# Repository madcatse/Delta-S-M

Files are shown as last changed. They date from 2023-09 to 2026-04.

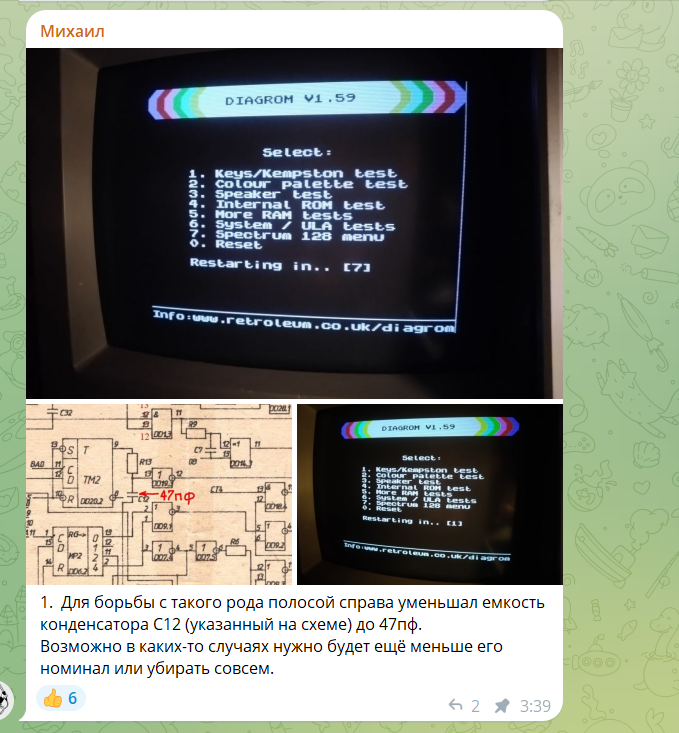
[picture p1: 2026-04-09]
fix1.PNG

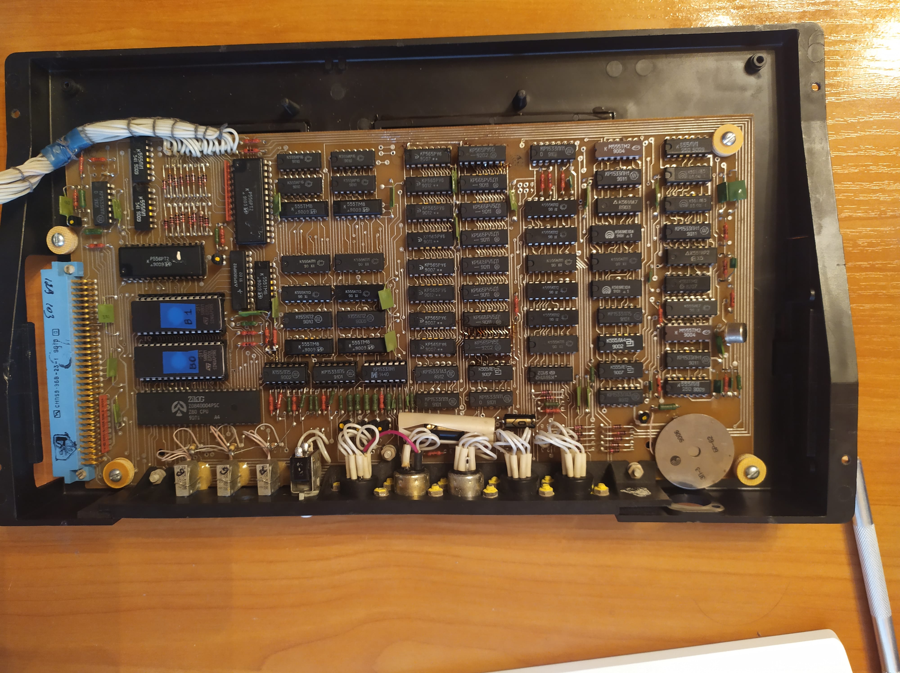
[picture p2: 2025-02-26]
docs/Original Delta/2023-03-17 20.00.21-min.jpg

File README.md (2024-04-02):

# Delta-S-M Ver.1.0 Gerber Files

Delta-S-M Logo

Welcome to the first release of Gerber files for Delta-S-M Ver.1.0! This repository contains the manufacturing files necessary to produce the Delta-S-M Ver.1.0 board.

## Table of Contents
- [Introduction](#introduction)
- [Features](#features)
- [Getting Started](#getting-started)
- [Folder Structure](#folder-structure)
- [Cable pinout difference](#cable-pinout-difference)
- [Making SCART cable](#making-scart-cable)
- [License](#license)

## Introduction
Основной задачей данного проекта я поставил создание наиболее близкого к оригиналу клона персонального восьмибитного компьютера "Дельта-С", который в свою очередь является клоном ZX Spectrum 48K. Выбор модели был обусловлен давней мечтой об "улучшении" оригинальной машины, которой я обладаю с 1991 года. В процессе работы цель проекта несколько раз корректировалась и вместо точной копии стала некоторой "вариацией" на тему оригинала, с небольшими корректировками.

## Features
- High-performance microcontroller
- Multiple digital and analog I/O options
- Onboard peripherals such as LEDs, buttons, and connectors
- Expandable with additional modules or shields
- Compact form factor for easy integration

## Getting Started
To get started with Delta-S-M Ver.1.0, follow these steps:
1. Clone or download this repository.
2. Open the Gerber files in your preferred PCB manufacturing software.
3. Verify the design and make any necessary adjustments.
4. Generate the necessary manufacturing files (e.g., drill files, copper layers).
5. Submit the generated files to your preferred PCB manufacturer.
6. Review the manufacturer's guidelines and requirements for PCB production.
7. Proceed with the manufacturing process.
8. Once manufactured, assemble the components onto the PCB following the provided bill of materials (BOM).
9. Power up the Delta-S-M Ver.1.0 board and start exploring its capabilities!

## Folder Structure
The repository is organized as follows:
- /Gerber: Contains the Gerber files necessary for PCB manufacturing.
- /BOM: Includes the bill of materials (BOM) listing all components required for assembly.
- /Documentation: Provides additional documentation, schematics, and datasheets related to Delta-S-M Ver.1.0.

## Cable pinout difference

Be carefull, as there is a very important difference in video cable pinout between v0.1, v1.0 and v1.2 and up.

**v0.1 and v1.0 boards video pinout:**

- 1 - Sync
- 2 - Red
- 3 - N/C
- 4 - Blue
- 5 - Green
- 6 - GND
- 7 - +5V

**v1.2 boards video pinout:**

- 1 - Sync
- 2 - GND
- 3 - Red
- 4 - Green
- 5 - Blue
- 6 - Audio
- 7 - +5V

V1.2 boards are compatible with original Delta-S and Delta-128 and could be connected with their cables.

## Making SCART cable
The best video quality could be achived with SCART cable with RGB mode. Delta S-M is capable of outputting native RGB signal and uses a SCART cable to connect to RGB-capable TVs. The picture below illustrates pinout of both SCART plug and DIN-7 plug.

SCART Pinout

15 - Red
11 - Green
7 - Blue
20 - Sync
16 - ADD 180 Ohm resistor between computer and SCART plug and connect it to pin 16 to enable switching to correct RGB mode. Direct +5V could DAMAGE YOUR TV!
5, 9, 13, 17 and 21 (metal case) - Ground

## License
This project is licensed under the [MIT License](LICENSE). Feel free to use, modify, and distribute the Delta-S-M Ver.1.0 Gerber files as per the terms of the license.

For more details, refer to the [LICENSE](LICENSE) file.

---

Delta-S-M Ver.1.0

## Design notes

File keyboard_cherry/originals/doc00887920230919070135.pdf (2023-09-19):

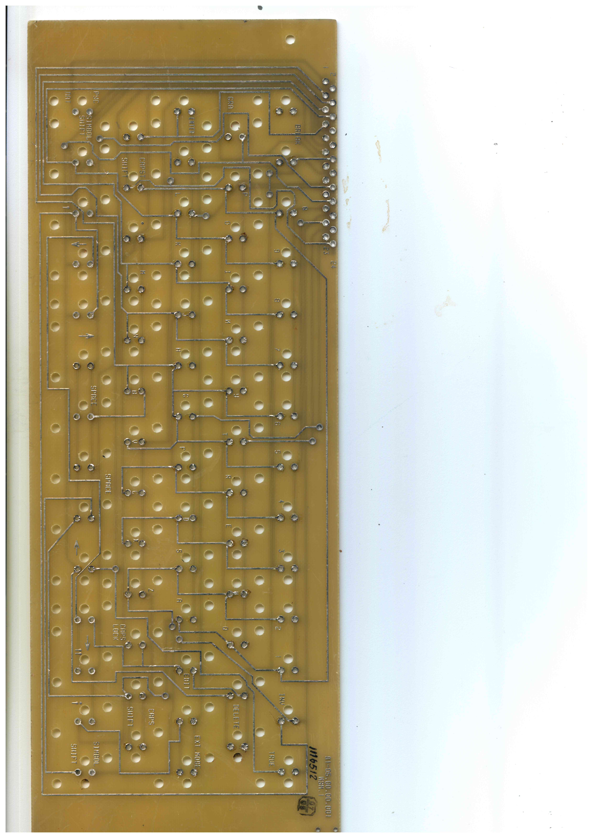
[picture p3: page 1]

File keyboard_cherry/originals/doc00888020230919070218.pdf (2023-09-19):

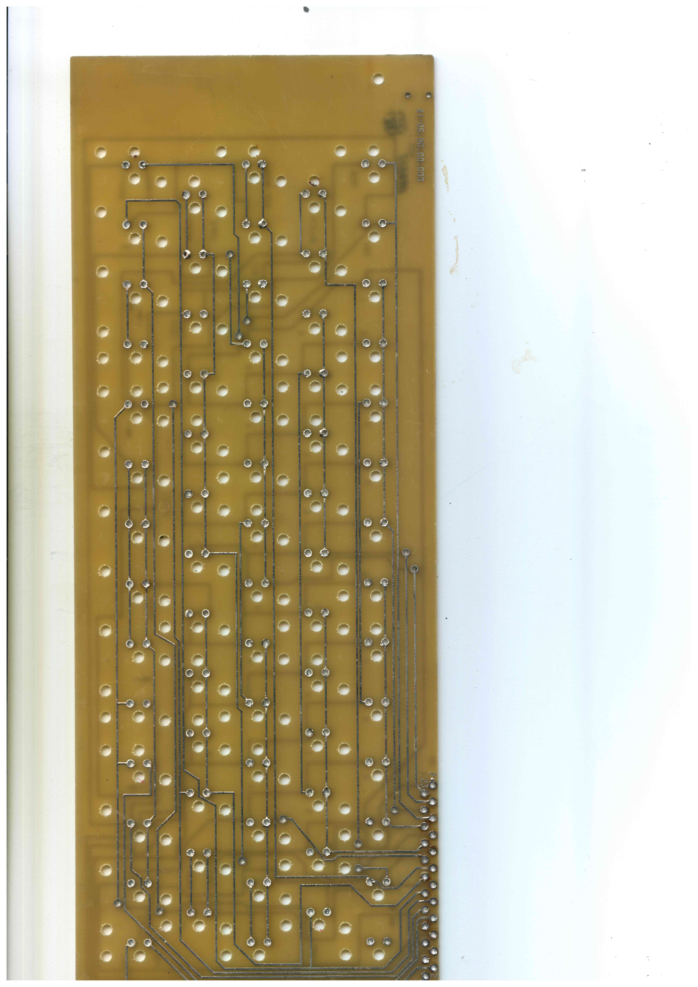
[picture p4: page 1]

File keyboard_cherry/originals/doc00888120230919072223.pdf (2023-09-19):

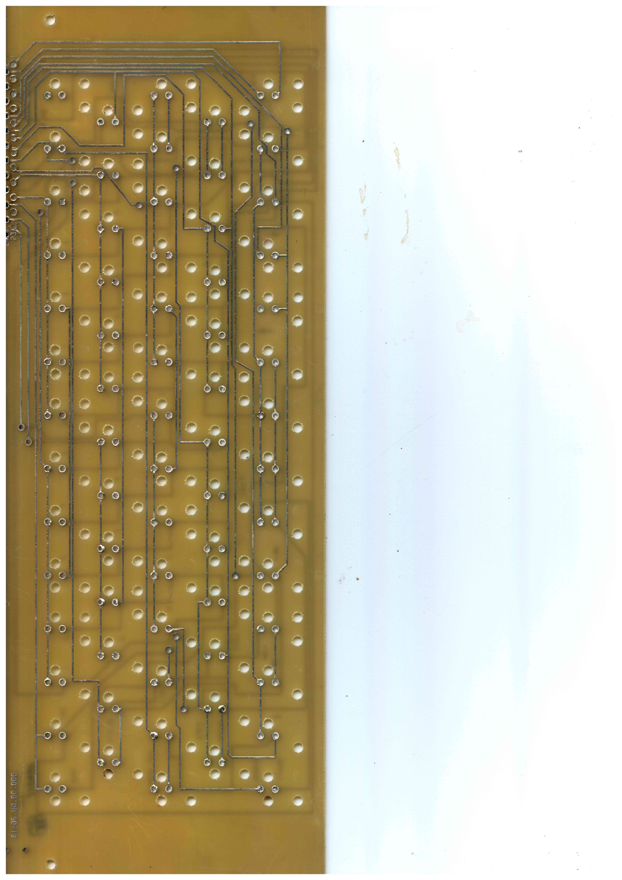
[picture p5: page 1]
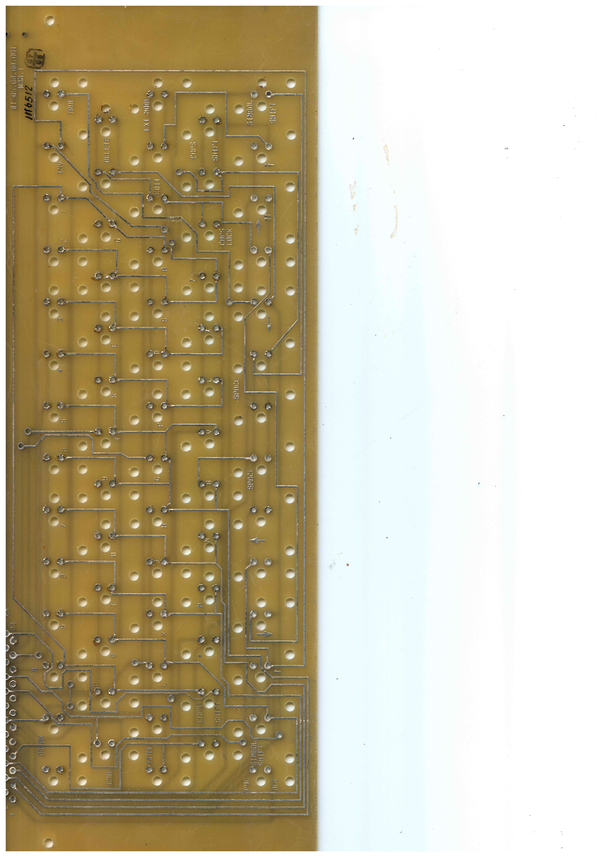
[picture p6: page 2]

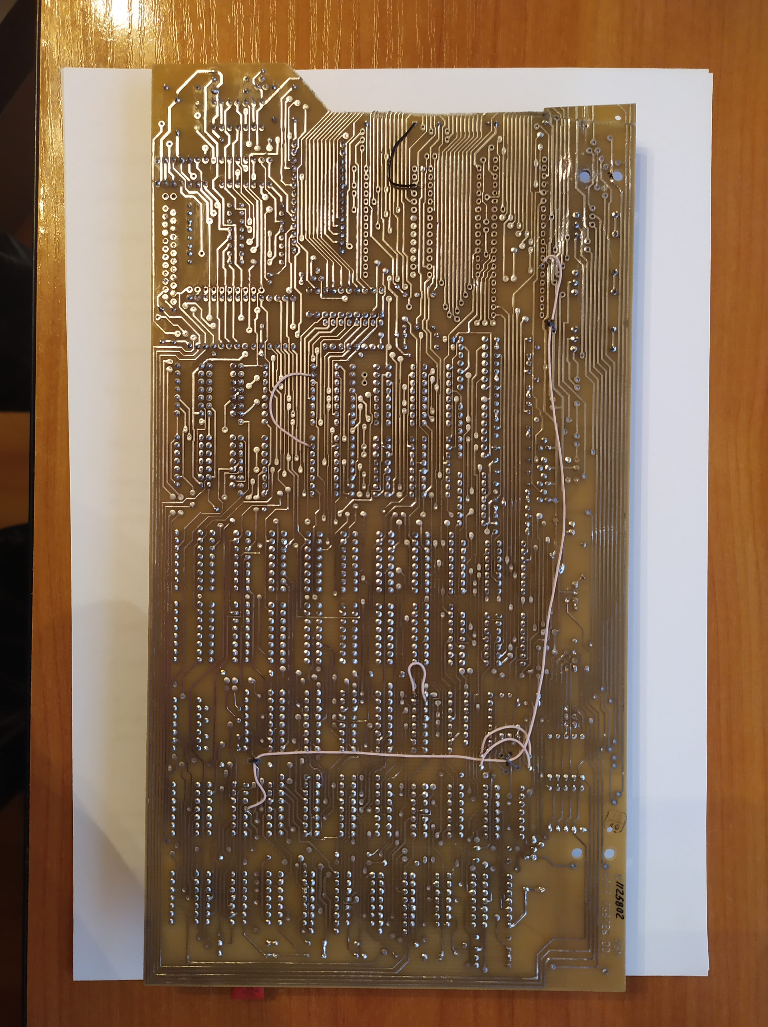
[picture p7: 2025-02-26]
docs/Photos of dead board/2023-03-13 19.23.27-min.jpg

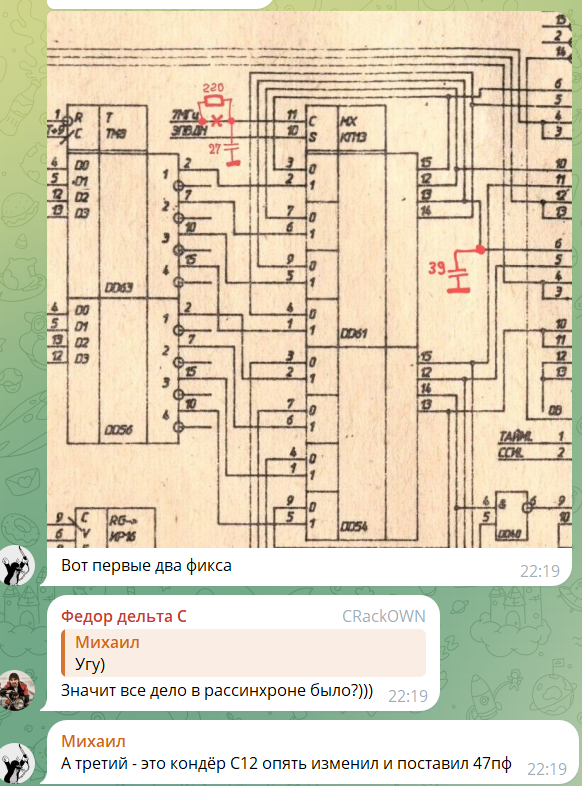
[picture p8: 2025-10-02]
Снимок.PNG

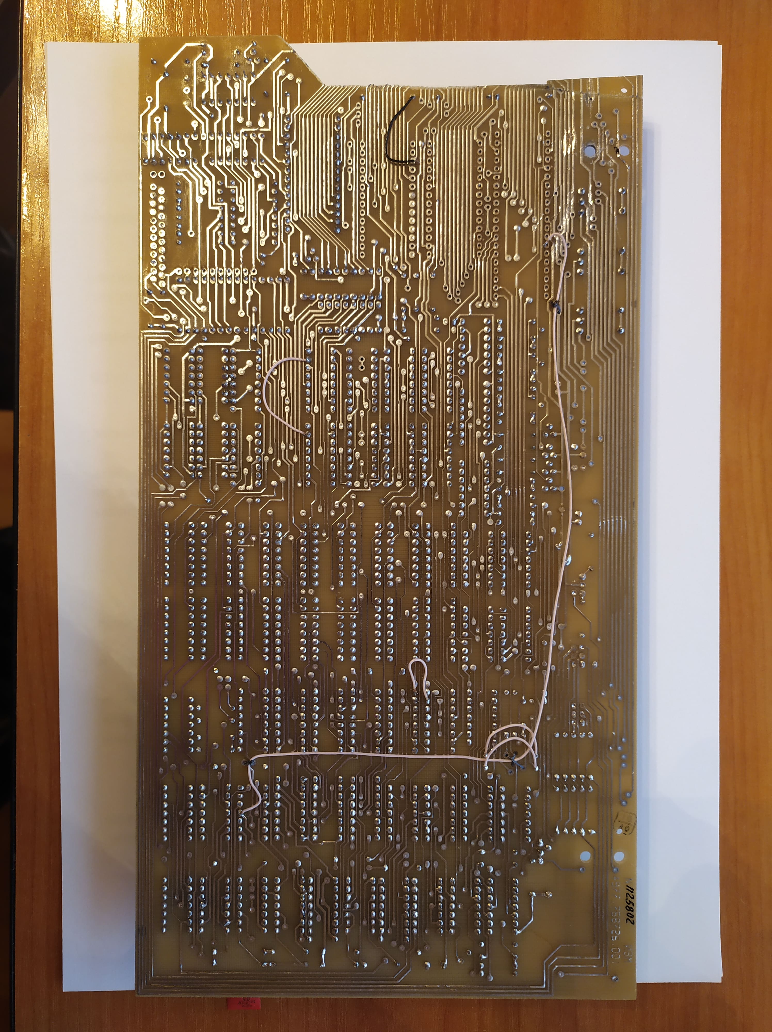
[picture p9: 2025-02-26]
docs/Photos of dead board/2023-03-13 19.23.37-min.jpg

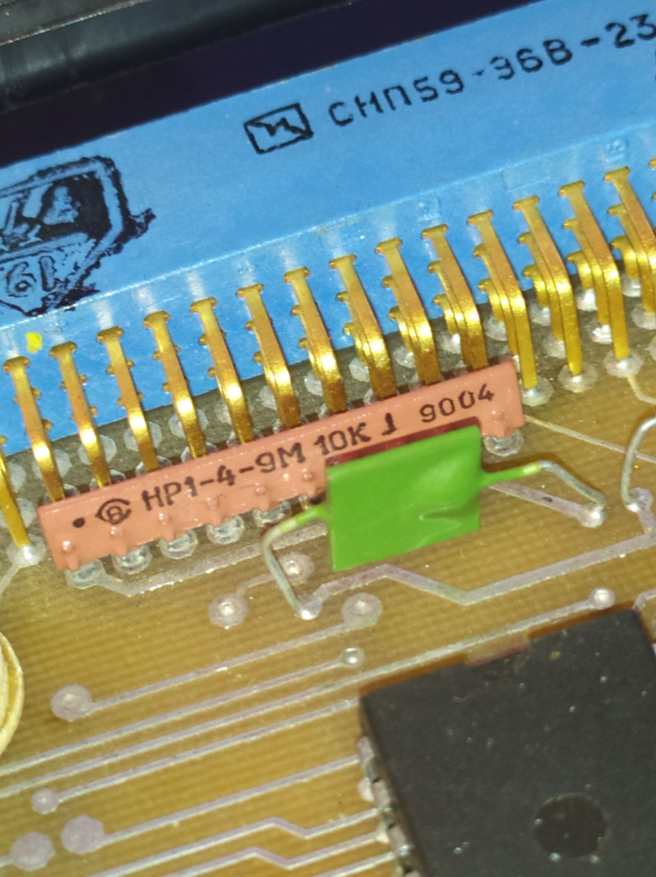
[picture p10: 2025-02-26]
docs/Original Delta/2023-03-13 20.28.23-min.jpg

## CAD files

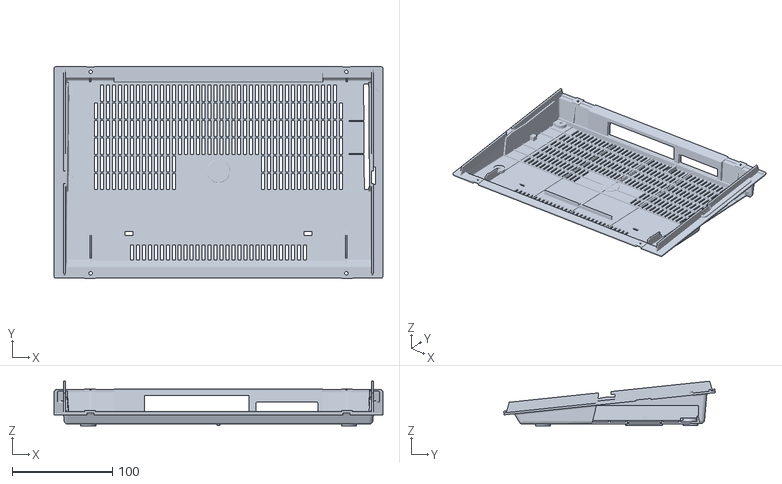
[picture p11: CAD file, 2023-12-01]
3d/stl case for ver2/case_bottom_mm_3.stl
328.0 x 211.2 x 44.5

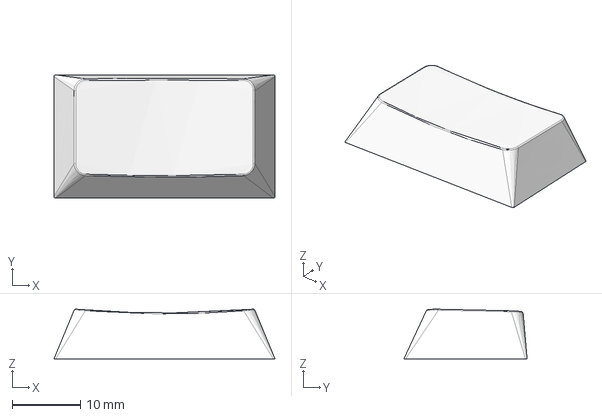
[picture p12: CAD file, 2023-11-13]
keyboard_cherry/175u.stp
32.3 x 18.0 x 7.25 mm

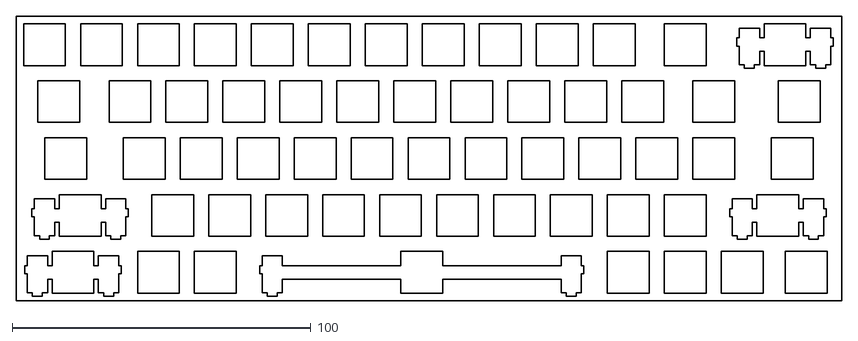
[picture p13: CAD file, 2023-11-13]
keyboard_cherry/raw_data/rev2/panel.dxf
276.2 x 95.2

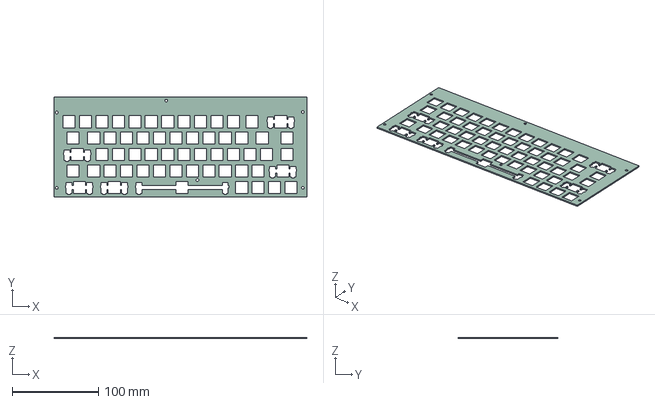
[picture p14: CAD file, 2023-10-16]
keyboard_cherry/rev1/keyboard_cherry_plate.step
293.1 x 115.4 x 1.58 mm

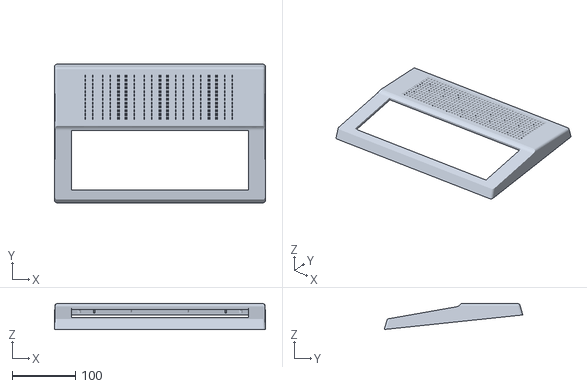
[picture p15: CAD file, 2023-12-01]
3d/stl case for ver2/case_top_mm_3.stl
333.0 x 218.8 x 41.0

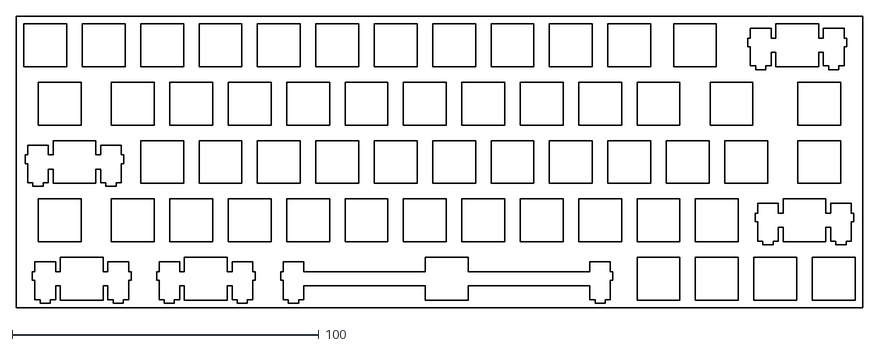
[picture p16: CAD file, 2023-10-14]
keyboard_cherry/plate_switch.dxf
276.2 x 95.2

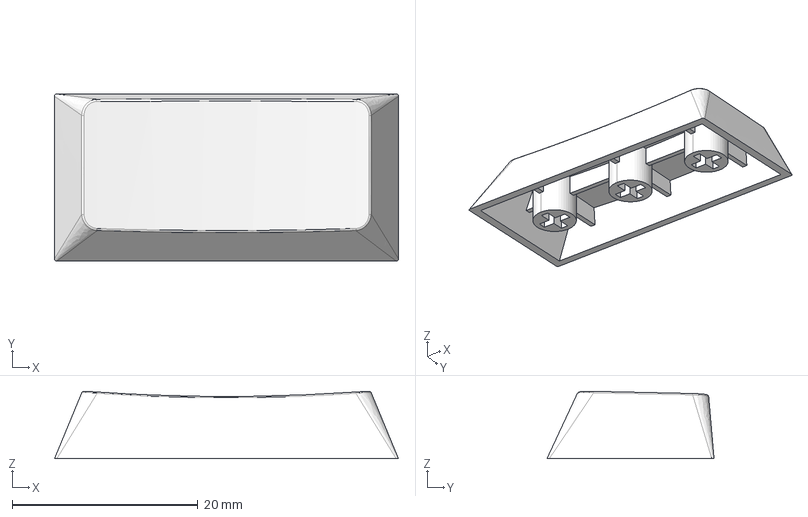
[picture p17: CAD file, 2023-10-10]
keyboard_cherry/200u.stp
37.1 x 18.0 x 7.25 mm

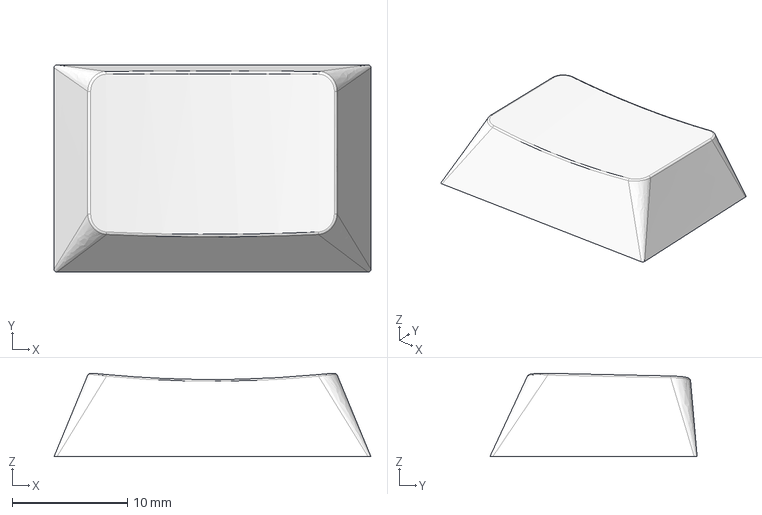
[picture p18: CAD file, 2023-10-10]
keyboard_cherry/150u.stp
27.5 x 18.0 x 7.25 mm

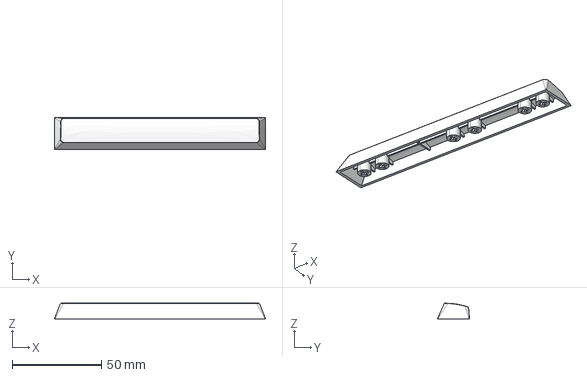
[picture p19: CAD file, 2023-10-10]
keyboard_cherry/625u.stp
118.0 x 18.0 x 8.70 mm

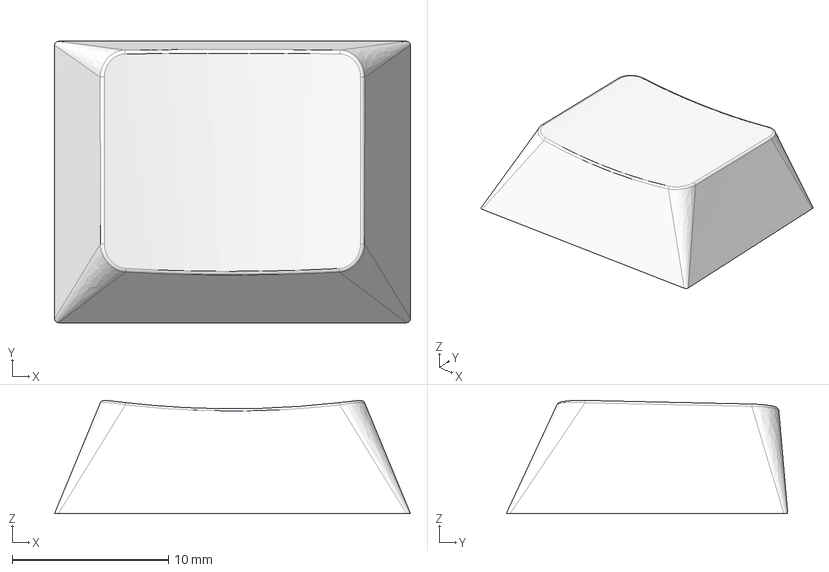
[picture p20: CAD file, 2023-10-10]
keyboard_cherry/125u.stp
22.8 x 18.0 x 7.24 mm

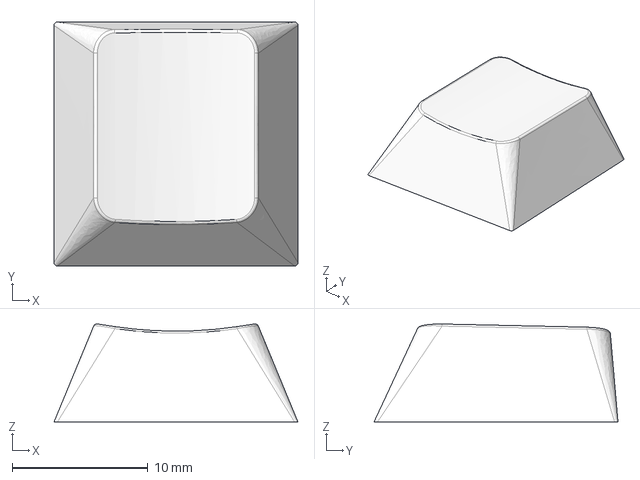
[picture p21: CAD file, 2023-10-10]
keyboard_cherry/100u.stp
18.0 x 18.0 x 7.23 mm

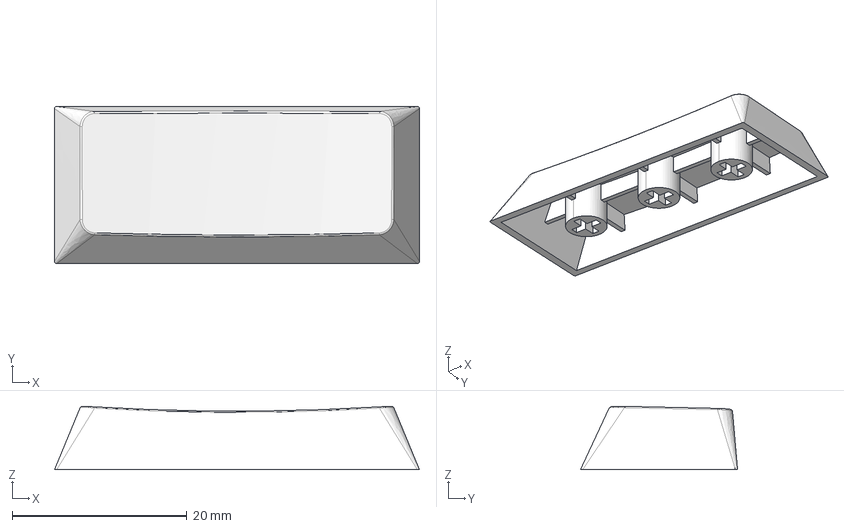
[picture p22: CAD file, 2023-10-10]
keyboard_cherry/225u.stp
41.8 x 18.0 x 7.26 mm

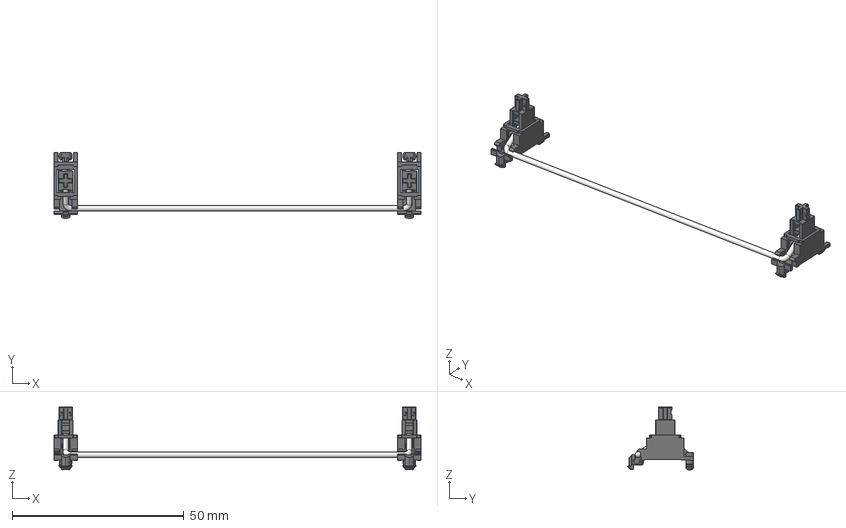
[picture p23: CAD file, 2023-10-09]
keyboard_cherry/Stabilizer_MX_6.25u.step
106.8 x 19.2 x 18.3 mm

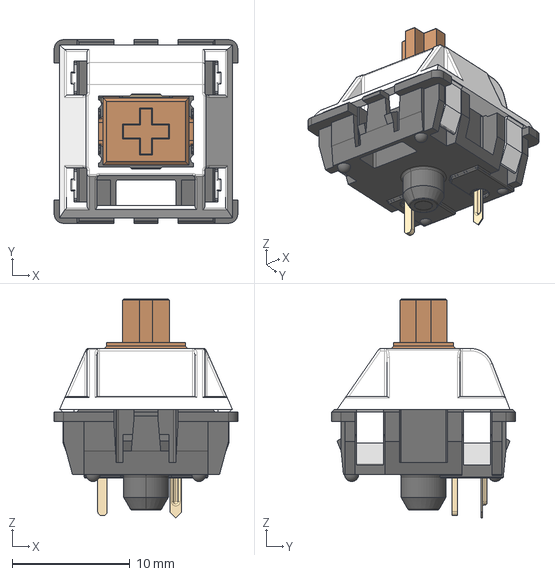
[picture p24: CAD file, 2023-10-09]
keyboard_cherry/MX_Plate.step
15.6 x 15.6 x 18.6 mm

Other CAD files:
keyboard_cherry/Stabilizer_MX_2.00u.step
keyboard_cherry/MX_PCB.step

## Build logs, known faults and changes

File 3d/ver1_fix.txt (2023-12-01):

Сделать шире опоры под мать
Посмотреть почему не садится задняя крышка
боковые выступы дна убрать чтобы крышка садилась
поднять повыше отверстие для динов

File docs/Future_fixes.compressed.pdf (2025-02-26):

Board index (http://www.nedopc.org/forum/index.php?sid=0d16f72c45000bbd3b2833f942d74b38) » ZX SPECTRUM (http://www.nedopc.org/forum/viewforum.php?f=113&sid=0d16f72c45000bbd3b2833f942d74b38) » ZX Spectrum (RUS) (http://www.nedopc.org/forum/viewforum.php?f=35&sid=0d16f72c45000bbd3b2833f942d74b38) | All times are UTC - 8 hours [ DST ]

Moderator: Shaos (http://www.nedopc.org/forum/memberlist.php?mode=viewprofile&u=2696&sid=0d16f72c45000bbd3b2833f942d74b38)

nedoPC.org
Electronics hobbyists community established in 2002

Register (http://www.nedopc.org/forum/ucp.php?mode=register&sid=0d16f72c45000bbd3b2833f942d74b38) • FAQ (http://www.nedopc.org/forum/faq.php?sid=0d16f72c45000bbd3b2833f942d74b38) • Search (http://www.nedopc.org/forum/search.php?sid=0d16f72c45000bbd3b2833f942d74b38) • Login (http://www.nedopc.org/forum/ucp.php?mode=login&sid=0d16f72c45000bbd3b2833f942d74b38)

Atom Feed (http://www.nedopc.org/forum/feed.php) | View unanswered posts (http://www.nedopc.org/forum/search.php?search_id=unanswered&sid=0d16f72c45000bbd3b2833f942d74b38) | View active topics (http://www.nedopc.org/forum/search.php?search_id=active_topics&sid=0d16f72c45000bbd3b2833f942d74b38) | It is currently 18 Nov 2023 15:38

Доработки Дельты-С на 75 микросхемах (http://www.nedopc.org/forum/viewtopic.php?f=35&t=21927&sid=0d16f72c45000bbd3b2833f942d74b38)

Page 1 of 1 [ 5 posts ]

Previous topic (http://www.nedopc.org/forum/viewtopic.php?f=35&t=21927&view=previous&sid=0d16f72c45000bbd3b2833f942d74b38) | Next topic (http://www.nedopc.org/forum/viewtopic.php?f=35&t=21927&view=next&sid=0d16f72c45000bbd3b2833f942d74b38)
ДОРАБОТКИ ДЕЛЬТЫ-С НА 75 МИКРОСХЕМАХ
Author | Message

SKV

Writer

Joined: 06 May 2022
08:39
Posts: 12

Доработки Дельты-С на 75 микросхемах (http://www.nedopc.org/forum/viewtopic.php?f=35&t=21927&sid=2aca3f283532890764204fbb175c0e95#p166377) Содержание:
1) Врождённая болезнь видеосигнала
2) Подключение по SCART
3) Доработки: INT, Kempston, 128K+AY
4) Арбитр IORQ. Разблокировка Sinclair-джойстиков, отключенных Z-Controller'ом.
5) Gotek как замена дискетам
6) Приложение. Принципиальная схема Дельты-С.
1) Вертикальная рябь изображения и усыпание точками экранов Basic 48 и TR-DOS, пропадающие при остановке Z80 (удержании кнопки Reset). Причина - ошибка проектирования печатной платы Дельты: дорожка зелёного видеоканала от крайнего потенциометра R44 до базы транзистора VT5 по всей длине примыкает к высокочастотной дорожке A0. Результат - сильные помехи в зелёном канале, синхронно с выводом звука на бипер.

Устранение - отрезать дорожку при повороте на транзистор, вместо неё от движка потенциометра проложить провод поверху.

В принципиальной схеме Дельты перепутаны каналы RGB, равно как и джойстиков Sinclair.

Attachment:
File comment: Точки на экране Basic 48

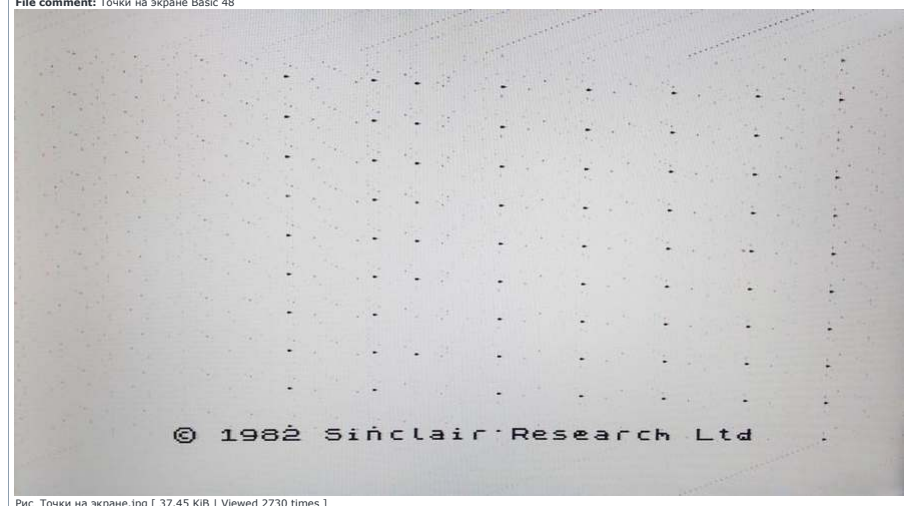
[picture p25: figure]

Рис_Точки на экране.jpg [ 37.45 KiB | Viewed 2730 times ]

Attachment:
File comment: Наводки в зелёном канале на базу VT5 от дорожки А0

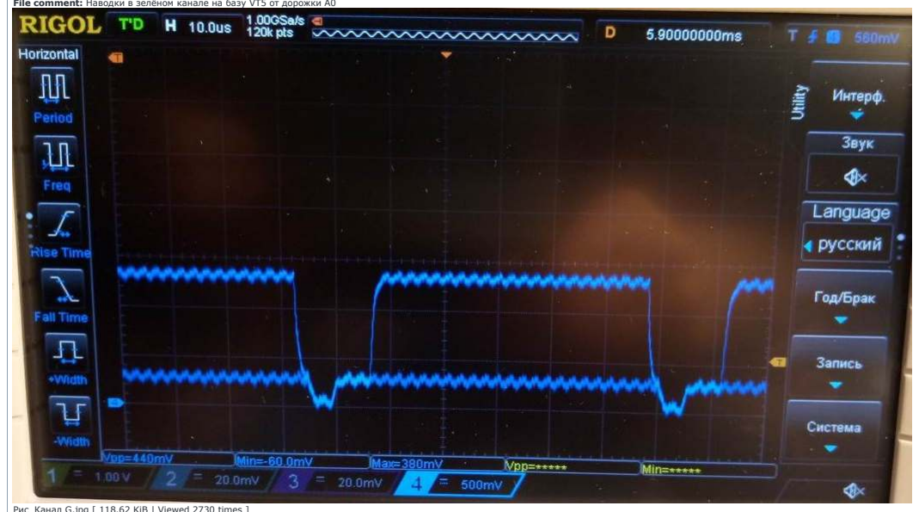
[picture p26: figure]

Рис_Канал G.jpg [ 118.62 KiB | Viewed 2730 times ]

Attachment:
File comment: Отрезание дорожки

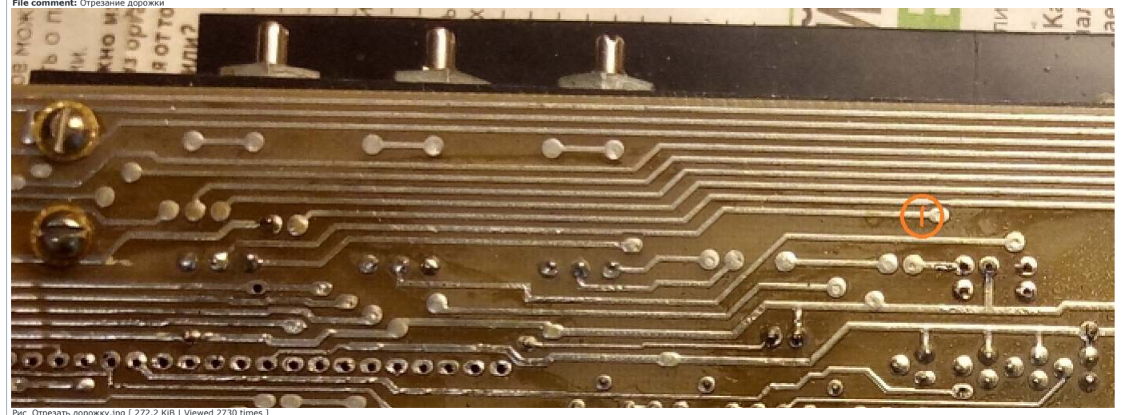
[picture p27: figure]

Рис_Отрезать дорожку.jpg [ 272.2 KiB | Viewed 2730 times ]

### 05 Aug 2022 08:37

SKV

Writer

Re: Доработки Дельты-С на 75 микросхемах (http://www.nedopc.org/forum/viewtopic.php?f=35&t=21927&sid=2aca3f283532890764204fbb175c0e95#p166378)
2) Видео и аудио на SCART
nedoPC.org - View topic - Доработки Дельты-С на 75 микросхемах | http://www.nedopc.org/forum/viewtopic.php?f=35&t=21927&sid=2aca...
Стр. 1 из 7 | 19.11.2023, 1:39

Joined: 06 May 2022
08:39
Posts: 12

Я применил разъём SubD9 от IBM COM-порта.
Размах каналов R,G,B уменьшить потенциометрами до 0,7V по осциллографу, поочерёдно выводя красный, зелёный, синий экран (использовать утилиту TEST TV или команды Бейсика PAPER и BORDER).

Потенциометры - от края к центру платы:
R44 - зелёный, выход на схеме 75, на плате не подписан.
R43 - красный, выход на схеме 74, на плате 4.
R42 - синий, выход на схеме 73, на плате 3.

Attachment:

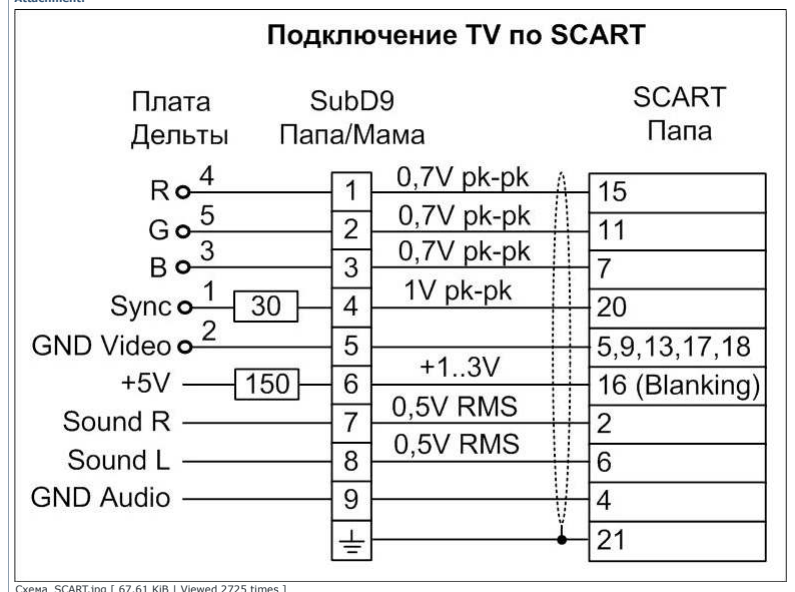
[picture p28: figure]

Схема_SCART.jpg [ 67.61 KiB | Viewed 2725 times ]
3) Доработки
- RC-цепочка длительности INT. (Альтернатива RC-цепочке - на триггере 1533ТМ2 с гашением от Z80).
Симптом болезни INT у Дельт - искажённая до неузнаваемости биперная музыка в ряде игр (Bronx, Ice palace, Arkanoid 2, Viaje al centro de la Terra, Target: Renegade).
- Kempston джойстик
- Память 128кБ, AY3-8910, смешивание аудиосигналов Beep+AY+General Sound

16 микросхем РУ5Д2+РУ6 заменить на 16 штук РУ5(Г).
ROM 27128 заменить на 27256 с прошивкой SOS 128 (либо на 27512 с прошивкой SOS 128 + TR-DOS, см. схему (https://www.cxemateka.ru/v1/Other.png) у Константина Айги).

Все эти новые микросхемы установить в панельки. На каждую микросхему РУ5 снизу по диагонали напаять блокировочный конденсатор 0,1 мкФ. Рекомендуется напаивать такой конденсатор и на все остальные микросхемы.

Attachment:

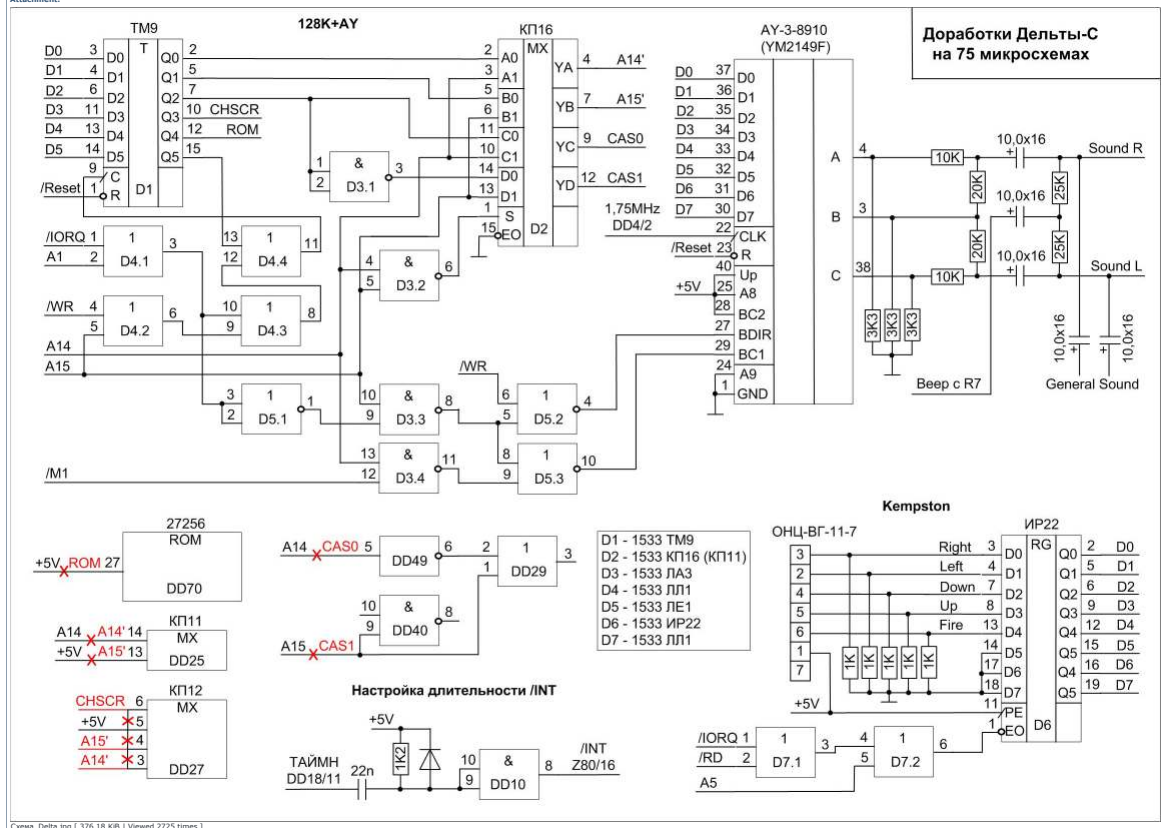
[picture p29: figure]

Схема_Delta.jpg [ 376.18 KiB | Viewed 2725 times ]

Last edited by SKV (http://www.nedopc.org/forum/memberlist.php?mode=viewprofile&u=11034&sid=0d16f72c45000bbd3b2833f942d74b38) on 06 Aug 2022 23:52, edited 1 time in total.

### 05 Aug 2022 09:05

SKV

Writer

Joined: 06 May 2022
08:39
Posts: 12

Re: Доработки Дельты-С на 75 микросхемах (http://www.nedopc.org/forum/viewtopic.php?f=35&t=21927&sid=2aca3f283532890764204fbb175c0e95#p166379)
4) ZX-bus, арбитр IORQ. Разблокировка Sinclair-джойстиков, отключенных Z-Controller'ом или другим контроллером IBM-клавиатуры.

Вся конструкция с ZX-bus размещается в IBM-корпусе, заодно решается и проблема Спектрумов с мощностью блока питания.

Клавиатура Дельты с прозрачными крышками отвратительна - кнопки заедают при нажатии. Поэтому подключение контроллера IBM-клавиатуры является необходимостью. Поразительно, но разработчики таких контроллеров игнорируют существование Sinclair-джойстика - основного (наряду с Kempston) игрового порта. Контроллер IBM-клавиатуры представляет собой внешний порт #FE, посредством арбитра IORQ блокирующий обращение к штатному порту #FE вместе с интегрированными в него Sinclair-джойстиками -таким образом, эти джойстики становятся недоступными. Глубже историю парадоксов ZX Interface II я освещал в другой своей заметке. (http://www.nedopc.org/forum/viewtopic.php?f=35&t=21891) Я нашёл решение этой патовой ситуации, применив 4 микросхемы в дополнение к арбитру IORQ на ЛЛ1.

Нажатие любой кнопки на любом из двух Sinclair-джойстиков обнаруживается элементом D5.
Если при этом (что случается 50 раз в секунду) осуществляется чтение порта #F7FE (полуряд 1..5, А11=0) или порта #EFFE (полуряд 0..6, А12=0), то дешифратор D1 элементом D4.4 отключает внешний порт #FE на Z-Controller и элементом D3.2 разрешает выбор внутреннего порта #FE в обход Z-Controller.
Стр. 2 из 7 | 19.11.2023, 1:39

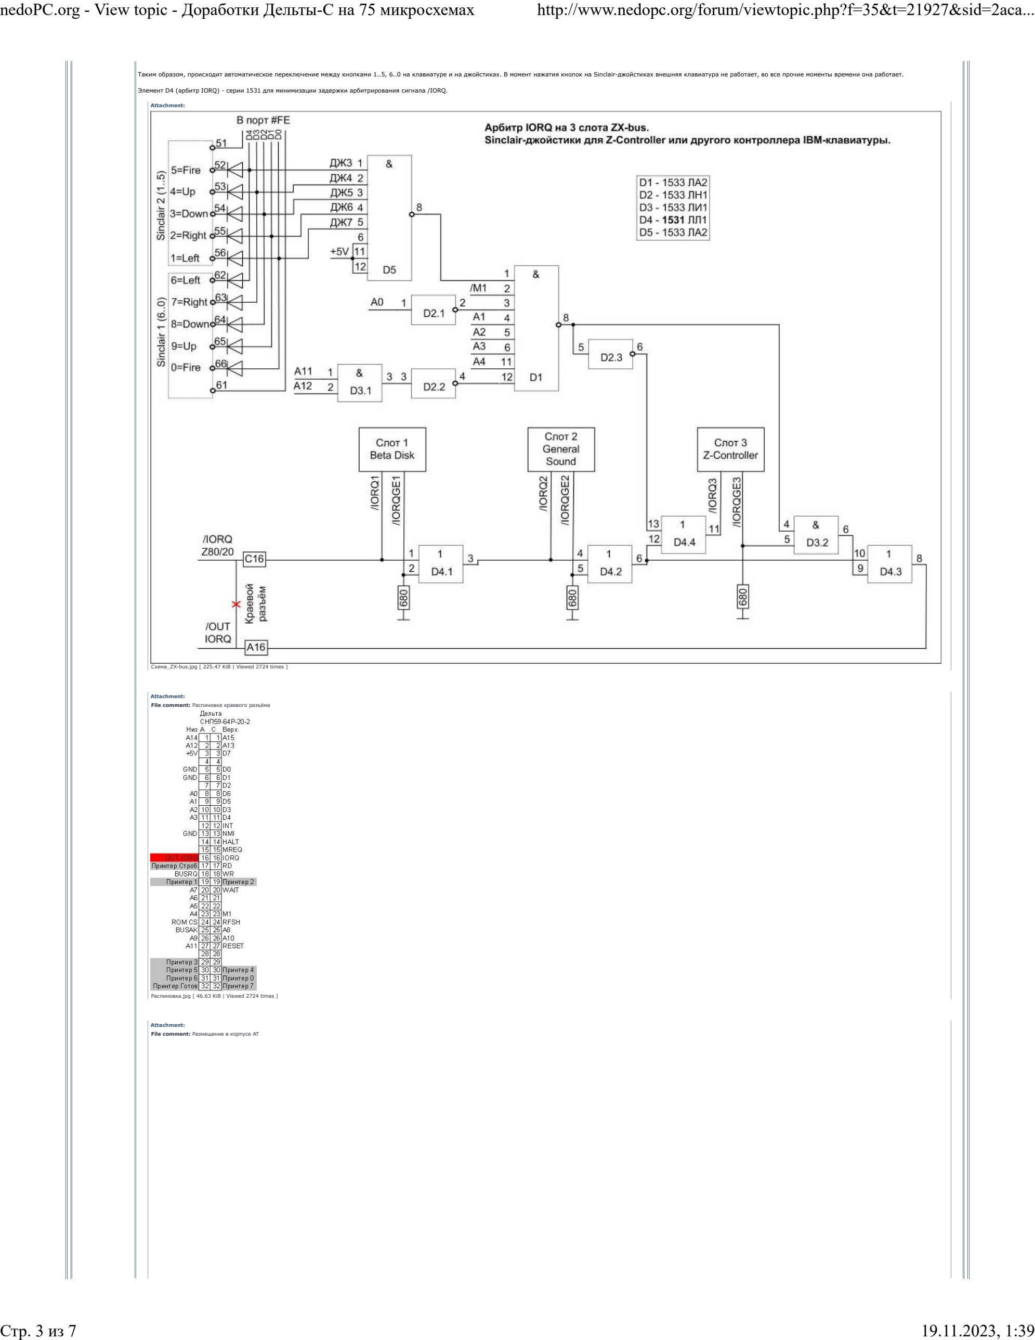
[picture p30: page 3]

Таким образом, происходит автоматическое переключение между кнопками 1..5, 6..0 на клавиатуре и на джойстиках. В момент нажатия кнопок на Sinclair-джойстиках внешняя клавиатура не работает, во все прочие моменты времени она работает.

Элемент D4 (арбитр IORQ) - серии 1531 для минимизации задержки арбитрирования сигнала /IORQ.

Attachment:

Схема_ZX-bus.jpg [ 225.47 KiB | Viewed 2724 times ]

Attachment:
File comment: Распиновка краевого разъёма
Распиновка.jpg [ 46.63 KiB | Viewed 2724 times ]

Attachment:
File comment: Размещение в корпусе AT
Стр. 3 из 7 | 19.11.2023, 1:39

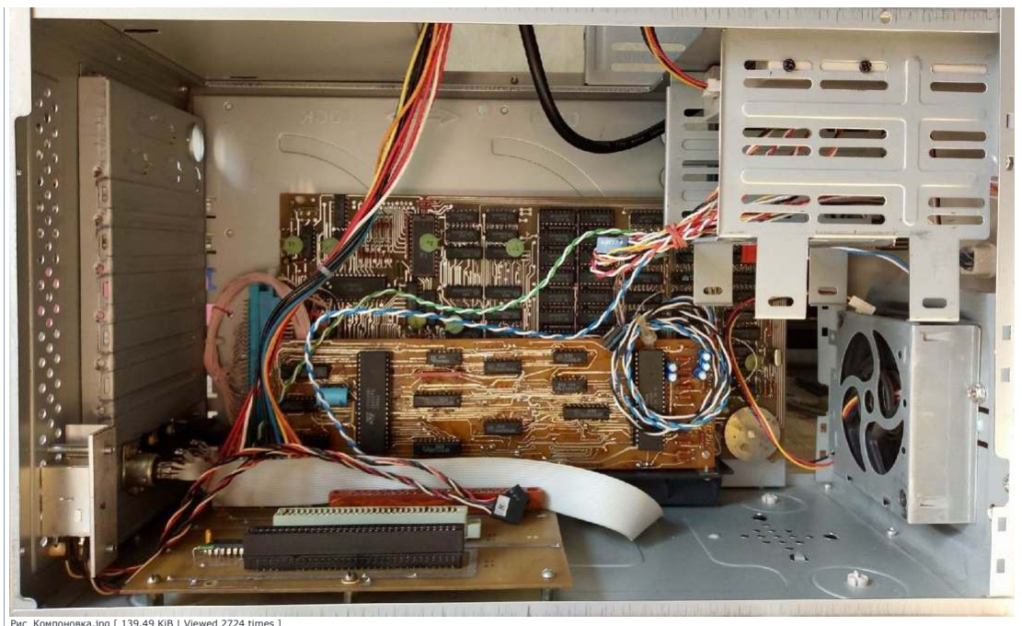
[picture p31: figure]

Рис_Компоновка.jpg [ 139.49 KiB | Viewed 2724 times ]
5) Gotek как замена дискетам
Я приобрёл Z-Controller, рассчитывая использовать встроенный в него Nemo IDE как решение задачи по переходу от своей коллекции из полусотни дискет к единому надёжному носителю. Однако оказалось, что за истёкшие 20 лет задача использования HDD штатными средствами Спектрума так и не была решена. Ближайшее решение, позволяющее запускать TRD-образы с HDD, состоит в инсталляции DNA OS при условии перепрошивки ROM. При штатном же ROM - HDD (равно как и SD-карту) можно использовать лишь как архивное хранилище TRD-образов (используя также копировщики FAT All или Wild Disk Copier).

Разочарованный, я случайно наткнулся на существование эмуляторов FDD и вышел на Gotek с прошивкой Flash Floppy. Приобрёл Gotek на AliExpress, залил в него прошивку Кейра Фразера Flash Floppy, подключил к Beta Disk как дисковод A, перегнал с дисковода B на воткнутую в Gotek флэшку свою коллекцию дискет в TRD-образы и получил универсальный носитель на USB-флэшке, легко доступный и для использования на Beta Disk, и для переноса TRD-файлов извне (с сайта vtrd.in).

У меня Gotek U144K на исчезающем чипе STM32, и для его прошивки программатор ST-Link V2. Кейр Фразер недавно выложил апдейт, (https://github.com/keirf/FlashFloppy/wiki/Gotek-Models) в котором рекомендует Gotek на улучшенной модификации чипа Artery - AT32F435:

«Starting July 2022, the factory is supplying an enhanced MCU option: the Artery AT32F435. This MCU runs at 288MHz and has 384kB SRAM. It is enough for reliable operation, extensive image caching, and will allow for a wider range of firmware features in future. The enhanced firmware which runs on this MCU is called FlashFloppy PLUS (or FlashFloppy+).»

Last edited by SKV (http://www.nedopc.org/forum/memberlist.php?mode=viewprofile&u=11034&sid=0d16f72c45000bbd3b2833f942d74b38) on 07 Aug 2022 00:01, edited 2 times in total.

05 Aug 2022 09:27
| Re: Доработки Дельты-С на 75 микросхемах (http://www.nedopc.org/forum/viewtopic.php?f=35&t=21927&sid=2aca3f283532890764204fbb175c0e95#p166380) 6) Приложение. Принципиальная схема Дельты-С.
SKV

Writer

Joined: 06 May 2022
08:39
Posts: 12

Attachment:

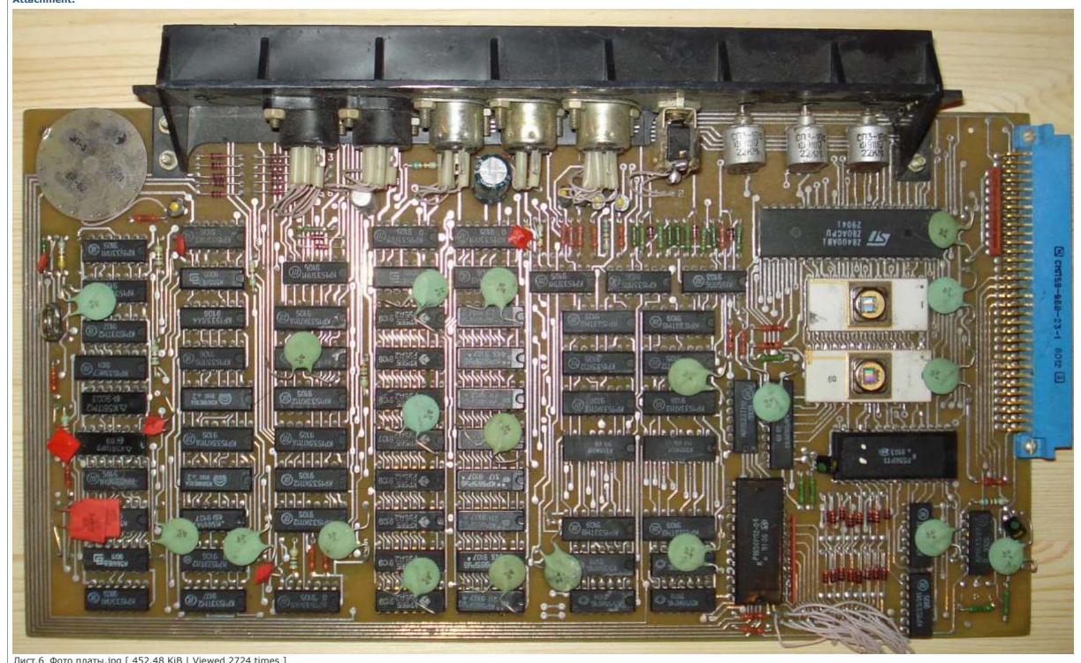
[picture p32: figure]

Лист 6_Фото платы.jpg [ 452.48 KiB | Viewed 2724 times ]

Attachment:

Стр. 4 из 7 | 19.11.2023, 1:39

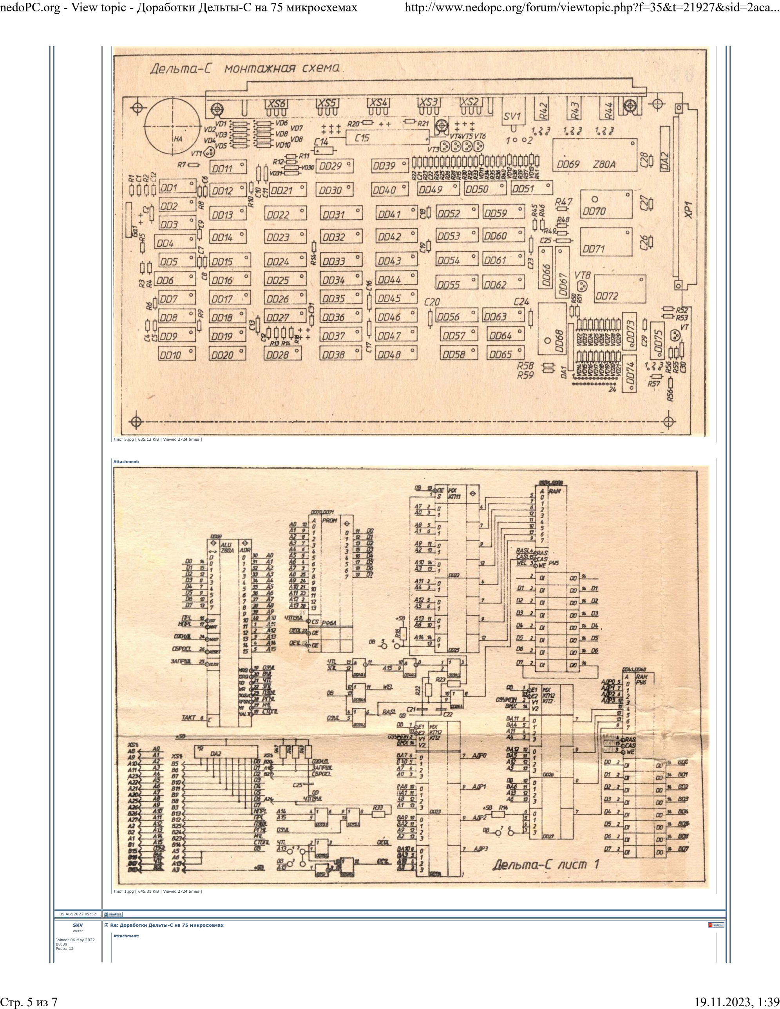
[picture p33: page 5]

Лист 5.jpg [ 635.12 KiB | Viewed 2724 times ]

Attachment:

Лист 1.jpg [ 645.31 KiB | Viewed 2724 times ]

05 Aug 2022 09:52
| Re: Доработки Дельты-С на 75 микросхемах (http://www.nedopc.org/forum/viewtopic.php?f=35&t=21927&sid=2aca3f283532890764204fbb175c0e95#p166381)
SKV

Writer

Joined: 06 May 2022
08:39
Posts: 12

Attachment:

Стр. 5 из 7 | 19.11.2023, 1:39

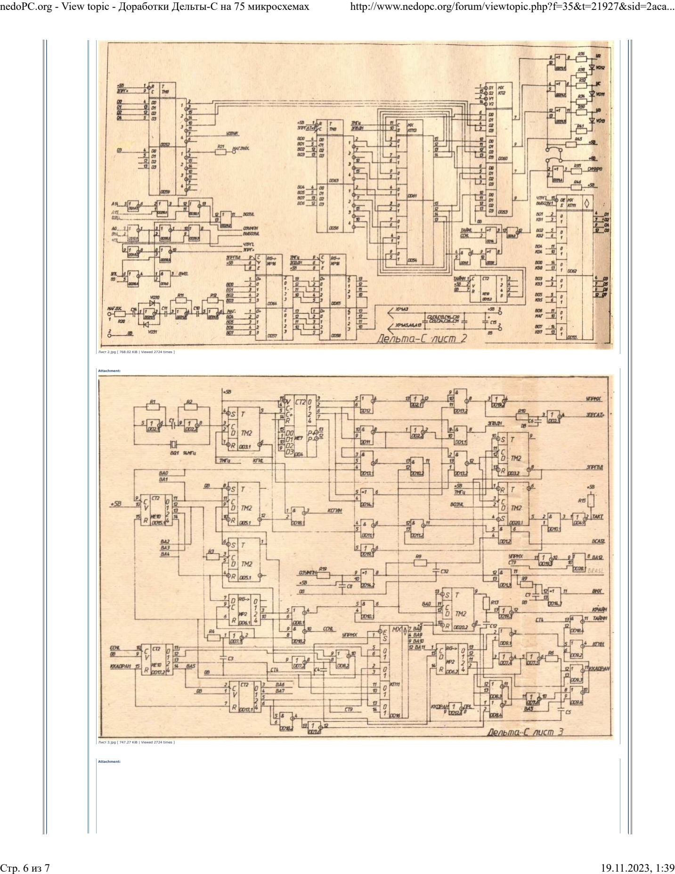
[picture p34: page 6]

Лист 2.jpg [ 768.02 KiB | Viewed 2724 times ]

Attachment:

Лист 3.jpg [ 747.27 KiB | Viewed 2724 times ]

Attachment:

Стр. 6 из 7 | 19.11.2023, 1:39

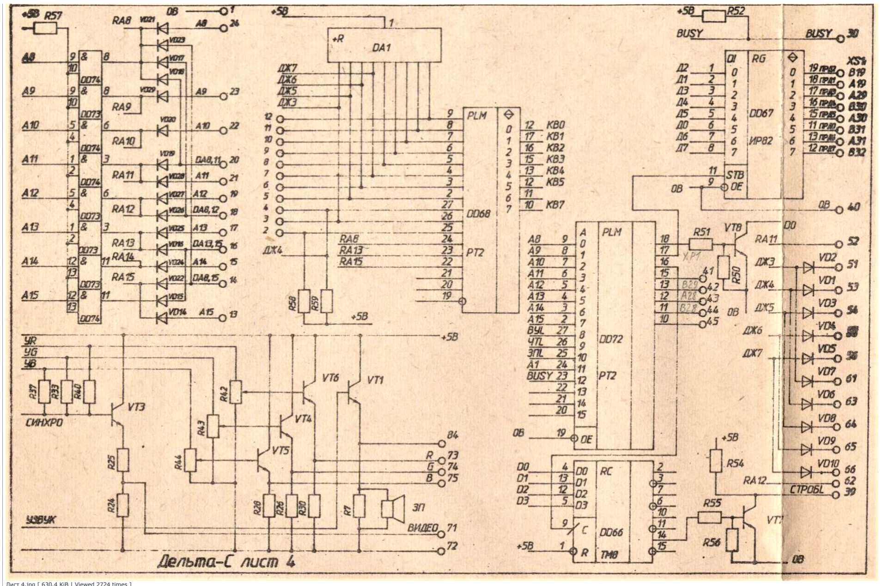
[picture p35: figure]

Board index (http://www.nedopc.org/forum/index.php?sid=0d16f72c45000bbd3b2833f942d74b38) » ZX SPECTRUM (http://www.nedopc.org/forum/viewforum.php?f=113&sid=0d16f72c45000bbd3b2833f942d74b38) » ZX Spectrum (RUS) (http://www.nedopc.org/forum/viewforum.php?f=35&sid=0d16f72c45000bbd3b2833f942d74b38) | All times are UTC - 8 hours [ DST ]
Лист 4.jpg [ 630.4 KiB | Viewed 2724 times ]

05 Aug 2022 09:54

Display posts from previous: | All posts | Sort by | Post time | Ascending | Go

Page 1 of 1 [ 5 posts ]

Who is online

Users browsing this forum: No registered users and 4 guests

You cannot post new topics in this forum You cannot reply to topics in this forum You cannot edit your posts in this forum You cannot delete your posts in this forum You cannot post attachments in this forum

Search for: | Go | Jump to: | ZX Spectrum (RUS) | Go

Powered by phpBB® (https://www.phpbb.com/) Forum Software © phpBB Group Designed by ST Software. (http://www.stsoftware.biz/index.html)

Стр. 7 из 7 | 19.11.2023, 1:39

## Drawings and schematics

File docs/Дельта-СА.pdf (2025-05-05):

C1

120

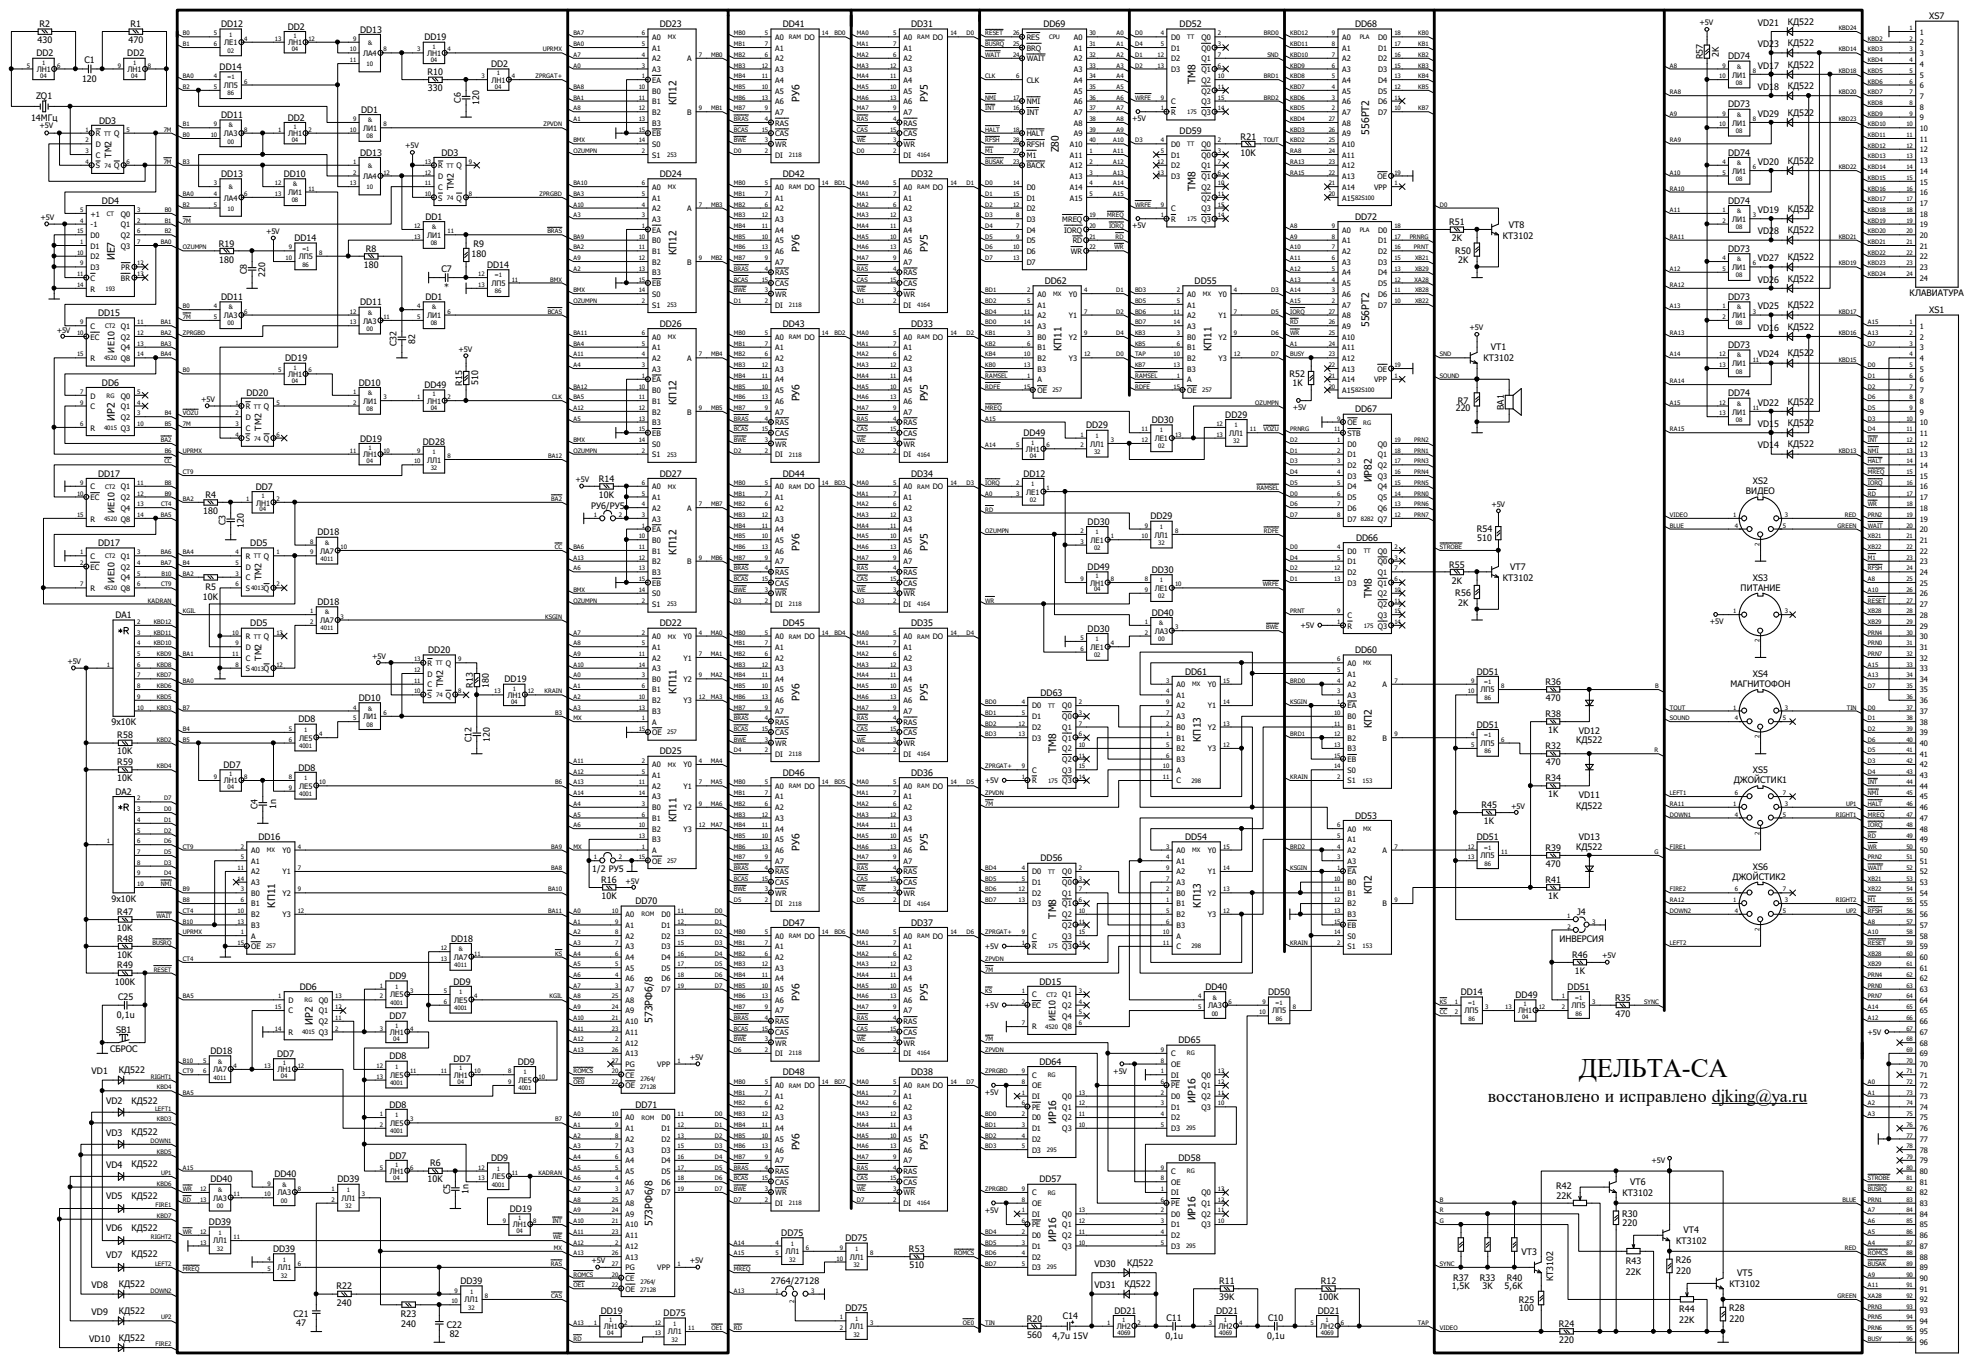
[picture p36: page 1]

восстановлено и исправлено djking@ya.ru

C2

0,1u

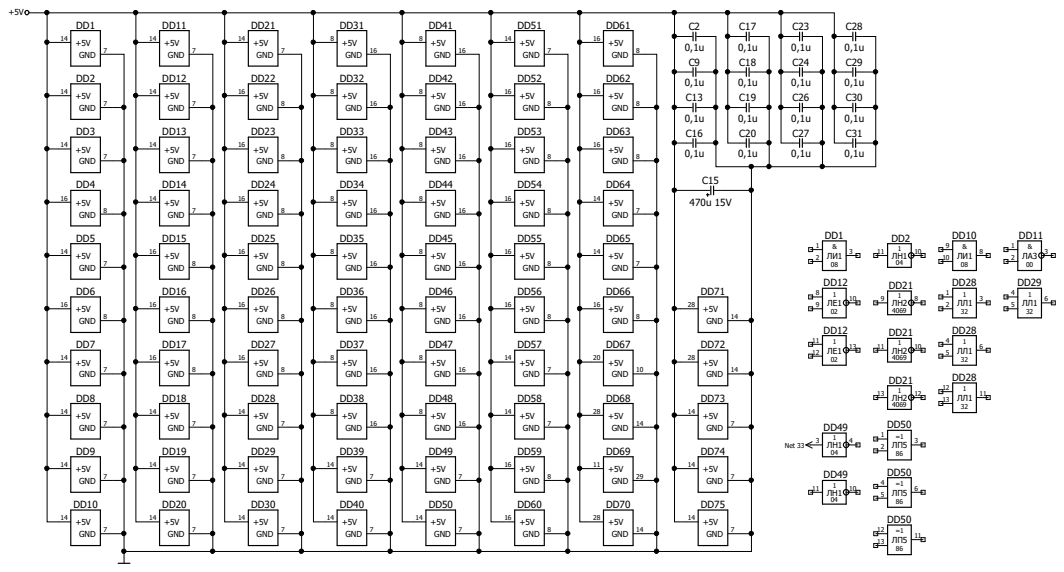
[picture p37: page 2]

# DA2 9х¹0К

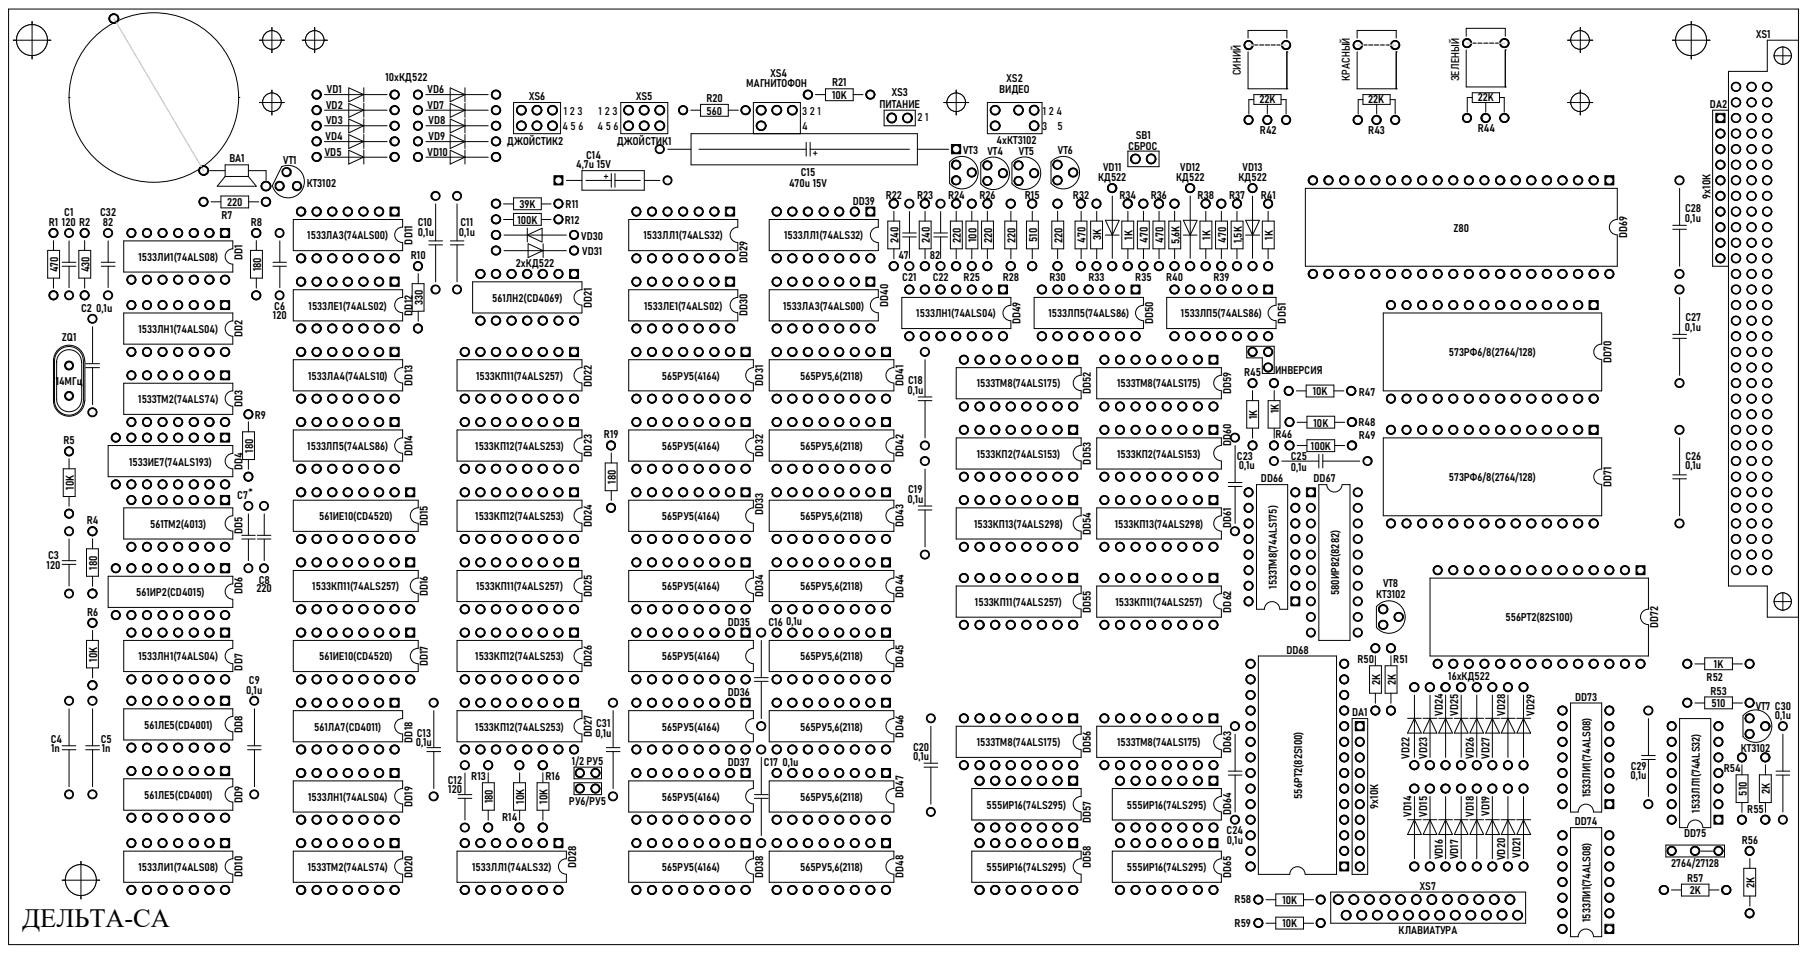
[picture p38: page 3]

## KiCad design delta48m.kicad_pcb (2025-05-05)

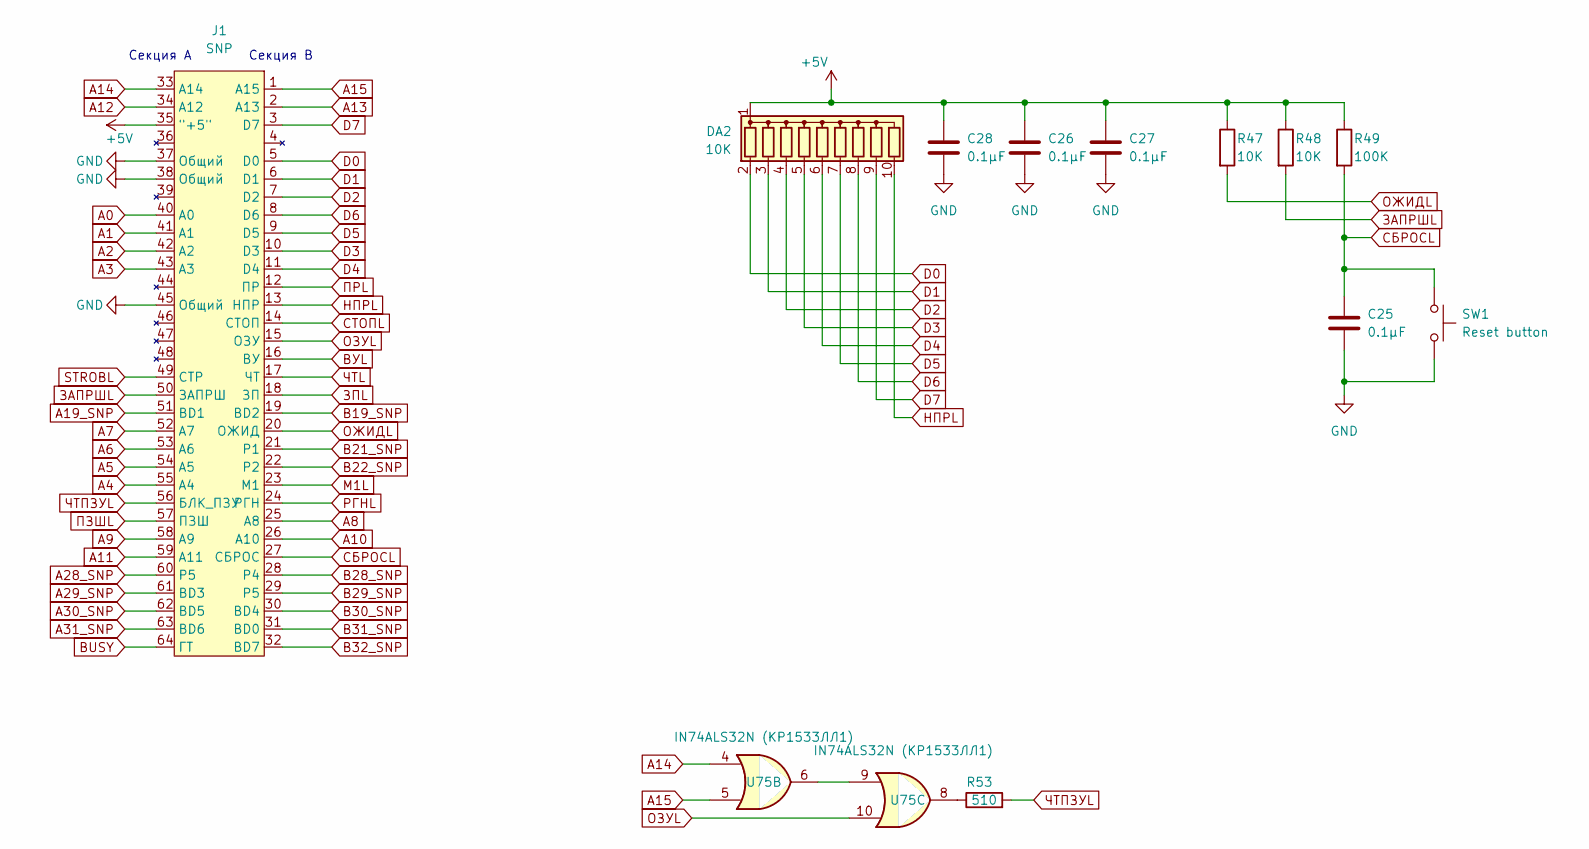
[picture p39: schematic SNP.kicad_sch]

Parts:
C25, C26, C27, C28: 0.1μF; C_Disc_D7.0mm_W2.5mm_P5.00mm
DA2: 10K; R_Array_SIP10
J1: SNP; snp59_96_female_angle_3
R47, R48: 10K; R_Axial_DIN0207_L6.3mm_D2.5mm_P10.16mm_Horizontal
R49: 100K; R_Axial_DIN0207_L6.3mm_D2.5mm_P10.16mm_Horizontal
R53: 510; R_Axial_DIN0207_L6.3mm_D2.5mm_P10.16mm_Horizontal
SW1: Reset button; SW_Tactile_SPST_Angled_PTS645Vx83-2LFS
U75: IN74ALS32N (КР1533ЛЛ1); DIP-14_W7.62mm_Socket

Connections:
+5V: C26.1, C27.1, C28.1, DA2.1 (common), J1.35 ("+5"), R47.1, R48.1, R49.1; also elsewhere on the board
A0: J1.40 (A0); also elsewhere on the board
A1: J1.41 (A1); also elsewhere on the board
A2: J1.42 (A2); also elsewhere on the board
A3: J1.43 (A3); also elsewhere on the board
A4: J1.55 (A4); also elsewhere on the board
A5: J1.54 (A5); also elsewhere on the board
A6: J1.53 (A6); also elsewhere on the board
A7: J1.52 (A7); also elsewhere on the board
A8: J1.25 (A8); also elsewhere on the board
A9: J1.58 (A9); also elsewhere on the board
A10: J1.26 (A10); also elsewhere on the board
A11: J1.59 (A11); also elsewhere on the board
A12: J1.34 (A12); also elsewhere on the board
A13: J1.2 (A13); also elsewhere on the board
A14: J1.33 (A14), U75.4; also elsewhere on the board
A15: J1.1 (A15), U75.5; also elsewhere on the board
A19_SNP: J1.51 (BD1); also elsewhere on the board
A28_SNP: J1.60 (P5); also elsewhere on the board
A29_SNP: J1.61 (BD3); also elsewhere on the board
A30_SNP: J1.62 (BD5); also elsewhere on the board
A31_SNP: J1.63 (BD6); also elsewhere on the board
B19_SNP: J1.19 (BD2); also elsewhere on the board
B21_SNP: J1.21 (P1); also elsewhere on the board
B22_SNP: J1.22 (P2); also elsewhere on the board
B28_SNP: J1.28 (P4); also elsewhere on the board
B29_SNP: J1.29 (P5); also elsewhere on the board
B30_SNP: J1.30 (BD4); also elsewhere on the board
B31_SNP: J1.31 (BD0); also elsewhere on the board
B32_SNP: J1.32 (BD7); also elsewhere on the board
BUSY: J1.64 (ГТ); also elsewhere on the board
D0: DA2.2 (R1), J1.5 (D0); also elsewhere on the board
D1: DA2.3 (R2), J1.6 (D1); also elsewhere on the board
D2: DA2.4 (R3), J1.7 (D2); also elsewhere on the board
D3: DA2.5 (R4), J1.10 (D3); also elsewhere on the board
D4: DA2.6 (R5), J1.11 (D4); also elsewhere on the board
D5: DA2.7 (R6), J1.9 (D5); also elsewhere on the board
D6: DA2.8 (R7), J1.8 (D6); also elsewhere on the board
D7: DA2.9 (R8), J1.3 (D7); also elsewhere on the board
GND: C25.2, C26.2, C27.2, C28.2, J1.37 (Общий), J1.38 (Общий), J1.45 (Общий), SW1.2; also elsewhere on the board
M1L: J1.23 (М1); also elsewhere on the board
unnamed: R53.1, U75.8
unnamed: U75.6, U75.9
STROBL: J1.49 (СТР); also elsewhere on the board
ВУL: J1.16 (ВУ); also elsewhere on the board
ЗАПРШL: J1.50 (ЗАПРШ), R48.2; also elsewhere on the board
ЗПL: J1.18 (ЗП); also elsewhere on the board
НПРL: DA2.10 (R9), J1.13 (НПР); also elsewhere on the board
ОЖИДL: J1.20 (ОЖИД), R47.2; also elsewhere on the board
ОЗУL: J1.15 (ОЗУ), U75.10; also elsewhere on the board
ПЗШL: J1.57 (ПЗШ); also elsewhere on the board
ПРL: J1.12 (ПР); also elsewhere on the board
РГНL: J1.24 (РГН); also elsewhere on the board
СБРОСL: C25.1, J1.27 (СБРОС), R49.2, SW1.1; also elsewhere on the board
СТОПL: J1.14 (СТОП); also elsewhere on the board
ЧТL: J1.17 (ЧТ); also elsewhere on the board
ЧТПЗУL: J1.56 (БЛК_ПЗУ), R53.2; also elsewhere on the board

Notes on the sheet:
Секция А
Секция В

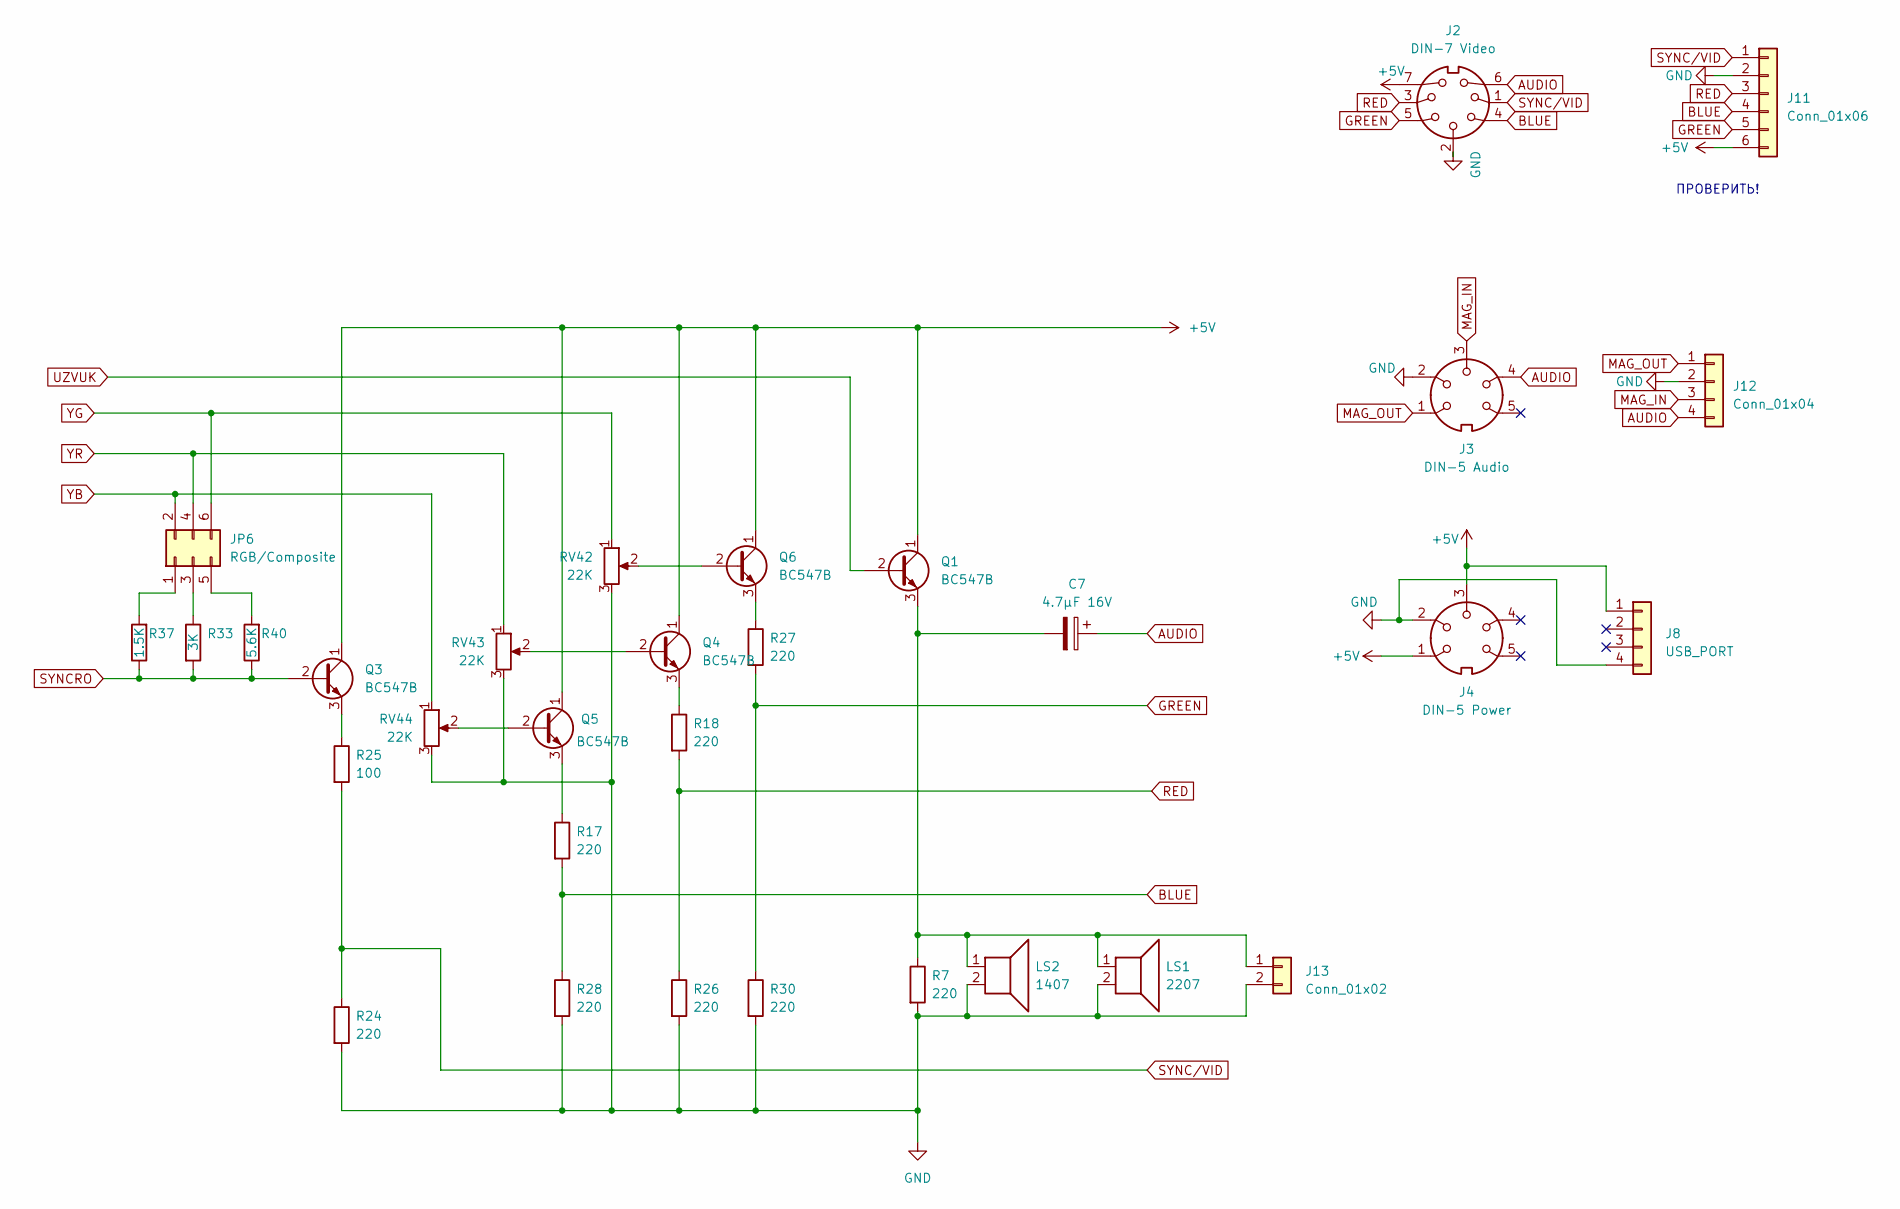
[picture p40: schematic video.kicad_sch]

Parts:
C7: 4.7µF 16V; CP_Radial_D4.0mm_P2.00mm
J2: DIN-7 Video; DIN-7-Variable
J3: DIN-5 Audio; DIN-5-Variable
J4: DIN-5 Power; DIN-5-Variable
J8: USB_PORT; USB-C Power board
J11: Conn_01x06; PinHeader_1x06_P2.54mm_Vertical
J12: Conn_01x04; PinHeader_1x04_P2.54mm_Vertical
J13: Conn_01x02; PinHeader_1x02_P2.54mm_Vertical
JP6: RGB/Composite; PinHeader_2x03_P2.54mm_Vertical
LS1: 2207; ZM-Piezo Buzzer-2207T2
LS2: 1407; 1407 Piezoelectric Passive Buzzer
Q1, Q3, Q4, Q5, Q6: BC547B; TO-92_Inline
R7, R17, R18, R24, R26, R27, R28, R30: 220; R_Axial_DIN0207_L6.3mm_D2.5mm_P10.16mm_Horizontal
R25: 100; R_Axial_DIN0207_L6.3mm_D2.5mm_P10.16mm_Horizontal
R33: 3K; R_Axial_DIN0207_L6.3mm_D2.5mm_P10.16mm_Horizontal
R37: 1.5K; R_Axial_DIN0207_L6.3mm_D2.5mm_P10.16mm_Horizontal
R40: 5.6K; R_Axial_DIN0207_L6.3mm_D2.5mm_P10.16mm_Horizontal
RV42, RV43, RV44: 22K; Potentiometer_Bourns_3299X_Horizontal

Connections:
+5V: J2.7, J4.1, J4.3, J8.1, J11.6, Q1.1 (C), Q3.1 (C), Q4.1 (C), Q5.1 (C), Q6.1 (C); also elsewhere on the board
AUDIO: C7.1, J2.6, J3.4, J12.4
BLUE: J2.4, J11.4, R17.2, R28.1
GND: J2.2, J3.2, J4.2, J8.4, J11.2, J12.2, J13.2, LS1.2, LS2.2, R7.2, R24.2, R26.2, R28.2, R30.2, RV42.3, RV43.3, RV44.3; also elsewhere on the board
GREEN: J2.5, J11.5, R27.2, R30.1
MAG_IN: J3.3, J12.3; also elsewhere on the board
MAG_OUT: J3.1, J12.1; also elsewhere on the board
unnamed: C7.2, J13.1, LS1.1, LS2.1, Q1.3 (E), R7.1
unnamed: JP6.1, R37.2
unnamed: JP6.3, R33.1
unnamed: JP6.5, R40.2
unnamed: Q3.3 (E), R25.1
unnamed: Q4.2 (B), RV43.2
unnamed: Q4.3 (E), R18.1
unnamed: Q5.2 (B), RV44.2
unnamed: Q5.3 (E), R17.1
unnamed: Q6.2 (B), RV42.2
unnamed: Q6.3 (E), R27.1
RED: J2.3, J11.3, R18.2, R26.1
SYNCRO: Q3.2 (B), R33.2, R37.1, R40.1; also elsewhere on the board
SYNC/VID: J2.1, J11.1, R24.1, R25.2
UZVUK: Q1.2 (B); also elsewhere on the board
YB: JP6.2, RV44.1; also elsewhere on the board
YG: JP6.6, RV42.1; also elsewhere on the board
YR: JP6.4, RV43.1; also elsewhere on the board

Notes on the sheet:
ПРОВЕРИТЬ!

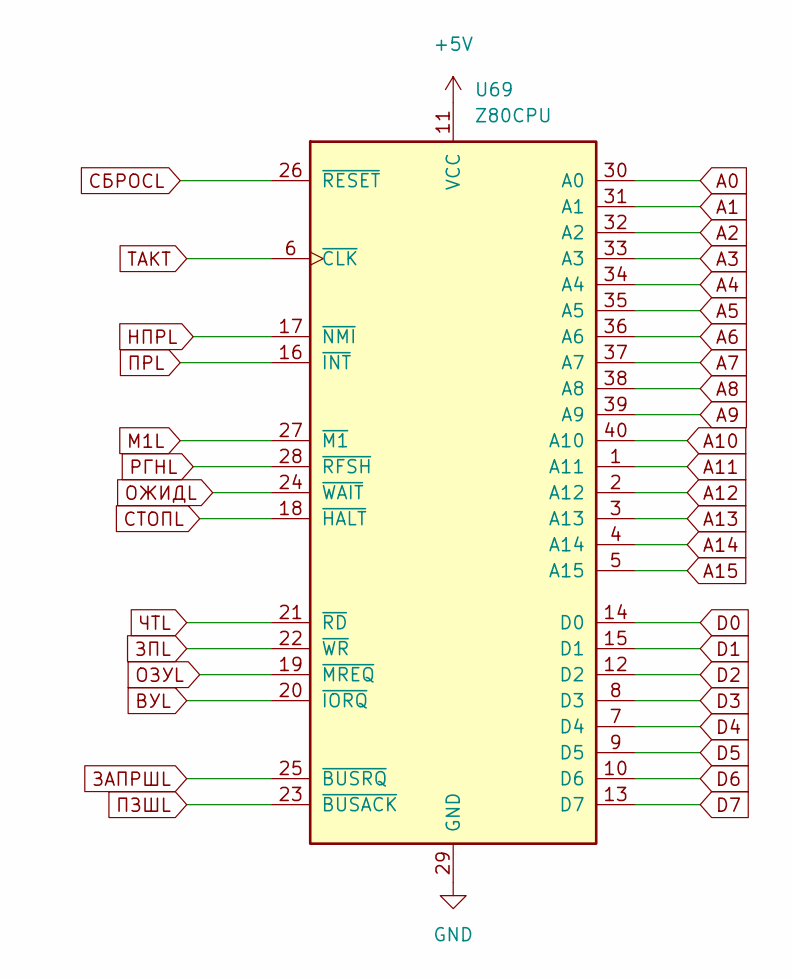
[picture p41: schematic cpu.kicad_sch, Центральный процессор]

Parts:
U69: Z80CPU; DIP-40_W15.24mm_Socket

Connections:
+5V: U69.11 (VCC); also elsewhere on the board
A0: U69.30 (A0); also elsewhere on the board
A1: U69.31 (A1); also elsewhere on the board
A2: U69.32 (A2); also elsewhere on the board
A3: U69.33 (A3); also elsewhere on the board
A4: U69.34 (A4); also elsewhere on the board
A5: U69.35 (A5); also elsewhere on the board
A6: U69.36 (A6); also elsewhere on the board
A7: U69.37 (A7); also elsewhere on the board
A8: U69.38 (A8); also elsewhere on the board
A9: U69.39 (A9); also elsewhere on the board
A10: U69.40 (A10); also elsewhere on the board
A11: U69.1 (A11); also elsewhere on the board
A12: U69.2 (A12); also elsewhere on the board
A13: U69.3 (A13); also elsewhere on the board
A14: U69.4 (A14); also elsewhere on the board
A15: U69.5 (A15); also elsewhere on the board
D0: U69.14 (D0); also elsewhere on the board
D1: U69.15 (D1); also elsewhere on the board
D2: U69.12 (D2); also elsewhere on the board
D3: U69.8 (D3); also elsewhere on the board
D4: U69.7 (D4); also elsewhere on the board
D5: U69.9 (D5); also elsewhere on the board
D6: U69.10 (D6); also elsewhere on the board
D7: U69.13 (D7); also elsewhere on the board
GND: U69.29 (GND); also elsewhere on the board
M1L: U69.27 (~M1); also elsewhere on the board
ВУL: U69.20 (~IORQ); also elsewhere on the board
ЗАПРШL: U69.25 (~BUSRQ); also elsewhere on the board
ЗПL: U69.22 (~WR); also elsewhere on the board
НПРL: U69.17 (~NMI); also elsewhere on the board
ОЖИДL: U69.24 (~WAIT); also elsewhere on the board
ОЗУL: U69.19 (~MREQ); also elsewhere on the board
ПЗШL: U69.23 (~BUSACK); also elsewhere on the board
ПРL: U69.16 (~INT); also elsewhere on the board
РГНL: U69.28 (~RFSH); also elsewhere on the board
СБРОСL: U69.26 (~RESET); also elsewhere on the board
СТОПL: U69.18 (~HALT); also elsewhere on the board
ТАКТ: U69.6 (~CLK); also elsewhere on the board
ЧТL: U69.21 (~RD); also elsewhere on the board

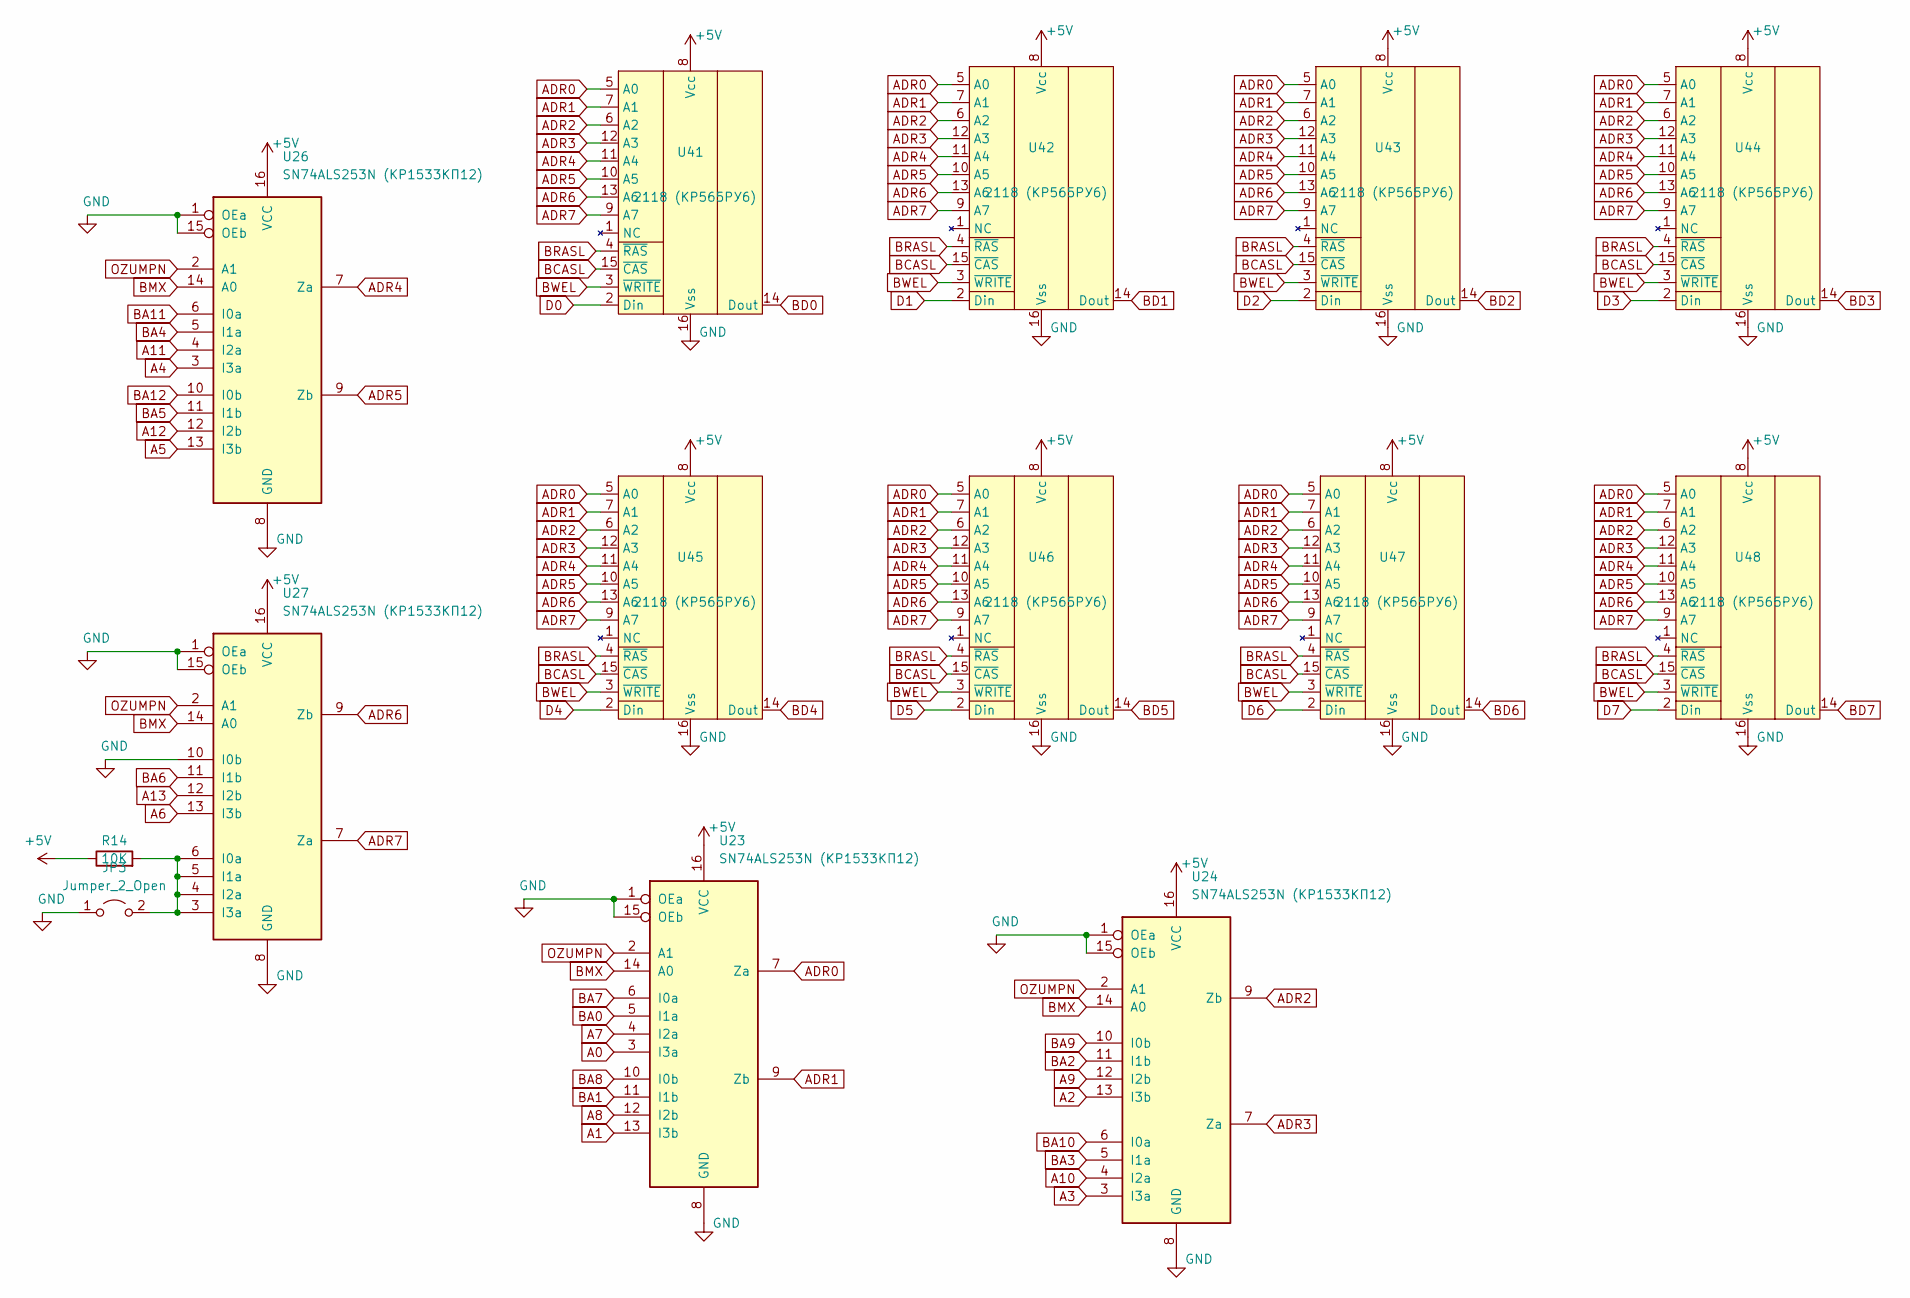
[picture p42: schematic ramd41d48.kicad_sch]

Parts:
JP3: Jumper_2_Open; PinHeader_1x02_P2.54mm_Vertical
R14: 10K; R_Axial_DIN0207_L6.3mm_D2.5mm_P10.16mm_Horizontal
U23, U24, U26, U27: SN74ALS253N (КР1533КП12); DIP-16_W7.62mm_Socket
U41, U42, U43, U44, U45, U46, U47, U48: 2118 (КР565РУ6); DIP-16_W7.62mm_Socket

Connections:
+5V: R14.1, U23.16 (VCC), U24.16 (VCC), U26.16 (VCC), U27.16 (VCC), U41.8 (Vcc), U42.8 (Vcc), U43.8 (Vcc), U44.8 (Vcc), U45.8 (Vcc), U46.8 (Vcc), U47.8 (Vcc), U48.8 (Vcc); also elsewhere on the board
A0: U23.3 (I3a); also elsewhere on the board
A1: U23.13 (I3b); also elsewhere on the board
A2: U24.13 (I3b); also elsewhere on the board
A3: U24.3 (I3a); also elsewhere on the board
A4: U26.3 (I3a); also elsewhere on the board
A5: U26.13 (I3b); also elsewhere on the board
A6: U27.13 (I3b); also elsewhere on the board
A7: U23.4 (I2a); also elsewhere on the board
A8: U23.12 (I2b); also elsewhere on the board
A9: U24.12 (I2b); also elsewhere on the board
A10: U24.4 (I2a); also elsewhere on the board
A11: U26.4 (I2a); also elsewhere on the board
A12: U26.12 (I2b); also elsewhere on the board
A13: U27.12 (I2b); also elsewhere on the board
ADR0: U23.7 (Za), U41.5 (A0), U42.5 (A0), U43.5 (A0), U44.5 (A0), U45.5 (A0), U46.5 (A0), U47.5 (A0), U48.5 (A0)
ADR1: U23.9 (Zb), U41.7 (A1), U42.7 (A1), U43.7 (A1), U44.7 (A1), U45.7 (A1), U46.7 (A1), U47.7 (A1), U48.7 (A1)
ADR2: U24.9 (Zb), U41.6 (A2), U42.6 (A2), U43.6 (A2), U44.6 (A2), U45.6 (A2), U46.6 (A2), U47.6 (A2), U48.6 (A2)
ADR3: U24.7 (Za), U41.12 (A3), U42.12 (A3), U43.12 (A3), U44.12 (A3), U45.12 (A3), U46.12 (A3), U47.12 (A3), U48.12 (A3)
ADR4: U26.7 (Za), U41.11 (A4), U42.11 (A4), U43.11 (A4), U44.11 (A4), U45.11 (A4), U46.11 (A4), U47.11 (A4), U48.11 (A4)
ADR5: U26.9 (Zb), U41.10 (A5), U42.10 (A5), U43.10 (A5), U44.10 (A5), U45.10 (A5), U46.10 (A5), U47.10 (A5), U48.10 (A5)
ADR6: U27.9 (Zb), U41.13 (A6), U42.13 (A6), U43.13 (A6), U44.13 (A6), U45.13 (A6), U46.13 (A6), U47.13 (A6), U48.13 (A6)
ADR7: U27.7 (Za), U41.9 (A7), U42.9 (A7), U43.9 (A7), U44.9 (A7), U45.9 (A7), U46.9 (A7), U47.9 (A7), U48.9 (A7)
BA0: U23.5 (I1a); also elsewhere on the board
BA1: U23.11 (I1b); also elsewhere on the board
BA2: U24.11 (I1b); also elsewhere on the board
BA3: U24.5 (I1a); also elsewhere on the board
BA4: U26.5 (I1a); also elsewhere on the board
BA5: U26.11 (I1b); also elsewhere on the board
BA6: U27.11 (I1b); also elsewhere on the board
BA7: U23.6 (I0a); also elsewhere on the board
BA8: U23.10 (I0b); also elsewhere on the board
BA9: U24.10 (I0b); also elsewhere on the board
BA10: U24.6 (I0a); also elsewhere on the board
BA11: U26.6 (I0a); also elsewhere on the board
BA12: U26.10 (I0b); also elsewhere on the board
BCASL: U41.15 (~CAS), U42.15 (~CAS), U43.15 (~CAS), U44.15 (~CAS), U45.15 (~CAS), U46.15 (~CAS), U47.15 (~CAS), U48.15 (~CAS); also elsewhere on the board
BD0: U41.14 (Dout); also elsewhere on the board
BD1: U42.14 (Dout); also elsewhere on the board
BD2: U43.14 (Dout); also elsewhere on the board
BD3: U44.14 (Dout); also elsewhere on the board
BD4: U45.14 (Dout); also elsewhere on the board
BD5: U46.14 (Dout); also elsewhere on the board
BD6: U47.14 (Dout); also elsewhere on the board
BD7: U48.14 (Dout); also elsewhere on the board
BMX: U23.14 (A0), U24.14 (A0), U26.14 (A0), U27.14 (A0); also elsewhere on the board
BRASL: U41.4 (~RAS), U42.4 (~RAS), U43.4 (~RAS), U44.4 (~RAS), U45.4 (~RAS), U46.4 (~RAS), U47.4 (~RAS), U48.4 (~RAS); also elsewhere on the board
BWEL: U41.3 (~WRITE), U42.3 (~WRITE), U43.3 (~WRITE), U44.3 (~WRITE), U45.3 (~WRITE), U46.3 (~WRITE), U47.3 (~WRITE), U48.3 (~WRITE); also elsewhere on the board
D0: U41.2 (Din); also elsewhere on the board
D1: U42.2 (Din); also elsewhere on the board
D2: U43.2 (Din); also elsewhere on the board
D3: U44.2 (Din); also elsewhere on the board
D4: U45.2 (Din); also elsewhere on the board
D5: U46.2 (Din); also elsewhere on the board
D6: U47.2 (Din); also elsewhere on the board
D7: U48.2 (Din); also elsewhere on the board
GND: JP3.1 (A), U23.1 (OEa), U23.8 (GND), U23.15 (OEb), U24.1 (OEa), U24.8 (GND), U24.15 (OEb), U26.1 (OEa), U26.8 (GND), U26.15 (OEb), U27.1 (OEa), U27.8 (GND), U27.10 (I0b), U27.15 (OEb), U41.16 (Vss), U42.16 (Vss), U43.16 (Vss), U44.16 (Vss), U45.16 (Vss), U46.16 (Vss), U47.16 (Vss), U48.16 (Vss); also elsewhere on the board
unnamed: JP3.2 (B), R14.2, U27.3 (I3a), U27.4 (I2a), U27.5 (I1a), U27.6 (I0a)
OZUMPN: U23.2 (A1), U24.2 (A1), U26.2 (A1), U27.2 (A1); also elsewhere on the board

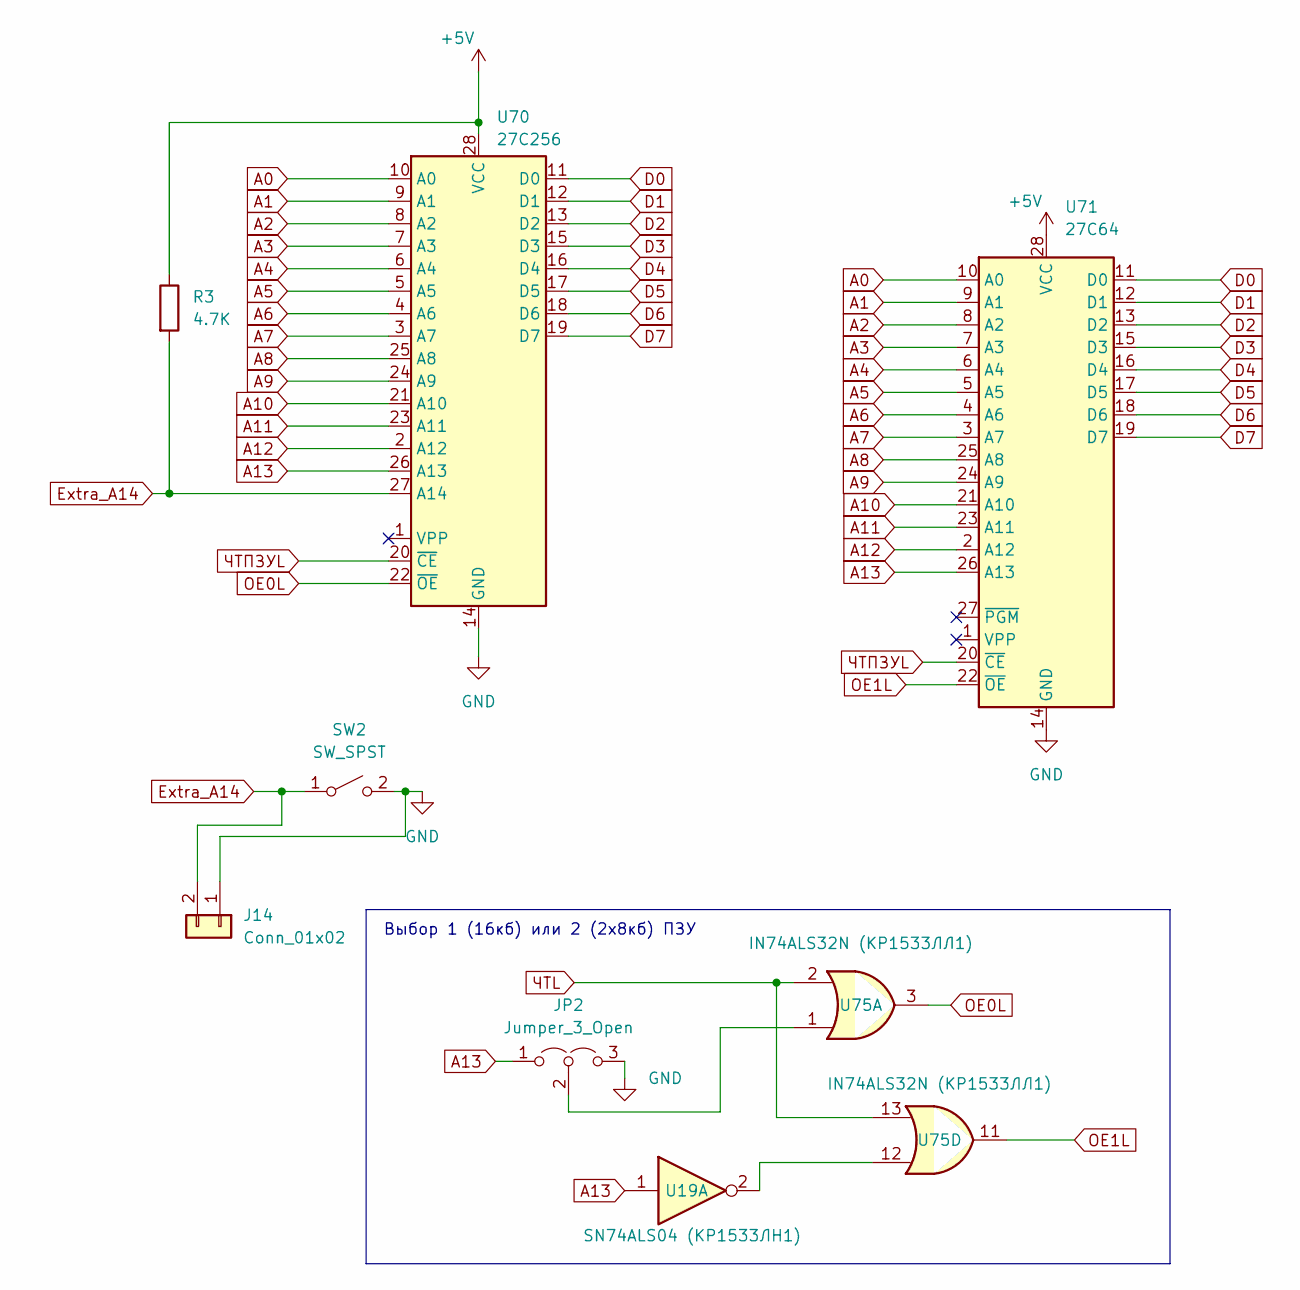
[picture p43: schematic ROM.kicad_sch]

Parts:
J14: Conn_01x02; PinHeader_1x02_P2.54mm_Vertical
JP2: Jumper_3_Open; PinHeader_1x03_P2.54mm_Vertical
R3: 4.7K; R_Axial_DIN0207_L6.3mm_D2.5mm_P10.16mm_Horizontal
SW2: SW_SPST; onoffswitch
U19: SN74ALS04 (КР1533ЛН1); DIP-14_W7.62mm_Socket
U70: 27C256; DIP-28_W15.24mm_Socket
U71: 27C64; DIP-28_W15.24mm_Socket
U75: IN74ALS32N (КР1533ЛЛ1); DIP-14_W7.62mm_Socket

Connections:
+5V: R3.1, U70.28 (VCC), U71.28 (VCC); also elsewhere on the board
A0: U70.10 (A0), U71.10 (A0); also elsewhere on the board
A1: U70.9 (A1), U71.9 (A1); also elsewhere on the board
A2: U70.8 (A2), U71.8 (A2); also elsewhere on the board
A3: U70.7 (A3), U71.7 (A3); also elsewhere on the board
A4: U70.6 (A4), U71.6 (A4); also elsewhere on the board
A5: U70.5 (A5), U71.5 (A5); also elsewhere on the board
A6: U70.4 (A6), U71.4 (A6); also elsewhere on the board
A7: U70.3 (A7), U71.3 (A7); also elsewhere on the board
A8: U70.25 (A8), U71.25 (A8); also elsewhere on the board
A9: U70.24 (A9), U71.24 (A9); also elsewhere on the board
A10: U70.21 (A10), U71.21 (A10); also elsewhere on the board
A11: U70.23 (A11), U71.23 (A11); also elsewhere on the board
A12: U70.2 (A12), U71.2 (A12); also elsewhere on the board
A13: JP2.1 (A), U19.1, U70.26 (A13), U71.26 (A13); also elsewhere on the board
D0: U70.11 (D0), U71.11 (D0); also elsewhere on the board
D1: U70.12 (D1), U71.12 (D1); also elsewhere on the board
D2: U70.13 (D2), U71.13 (D2); also elsewhere on the board
D3: U70.15 (D3), U71.15 (D3); also elsewhere on the board
D4: U70.16 (D4), U71.16 (D4); also elsewhere on the board
D5: U70.17 (D5), U71.17 (D5); also elsewhere on the board
D6: U70.18 (D6), U71.18 (D6); also elsewhere on the board
D7: U70.19 (D7), U71.19 (D7); also elsewhere on the board
Extra_A14: J14.2, R3.2, SW2.1 (A), U70.27 (A14)
GND: J14.1, JP2.3 (B), SW2.2 (B), U70.14 (GND), U71.14 (GND); also elsewhere on the board
unnamed: JP2.2 (C), U75.1
unnamed: U19.2, U75.12
OE0L: U70.22 (~OE), U75.3
OE1L: U71.22 (~OE), U75.11
ЧТL: U75.2, U75.13; also elsewhere on the board
ЧТПЗУL: U70.20 (~CE), U71.20 (~CE); also elsewhere on the board

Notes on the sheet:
Выбор 1 (16кб) или 2 (2х8кб) ПЗУ

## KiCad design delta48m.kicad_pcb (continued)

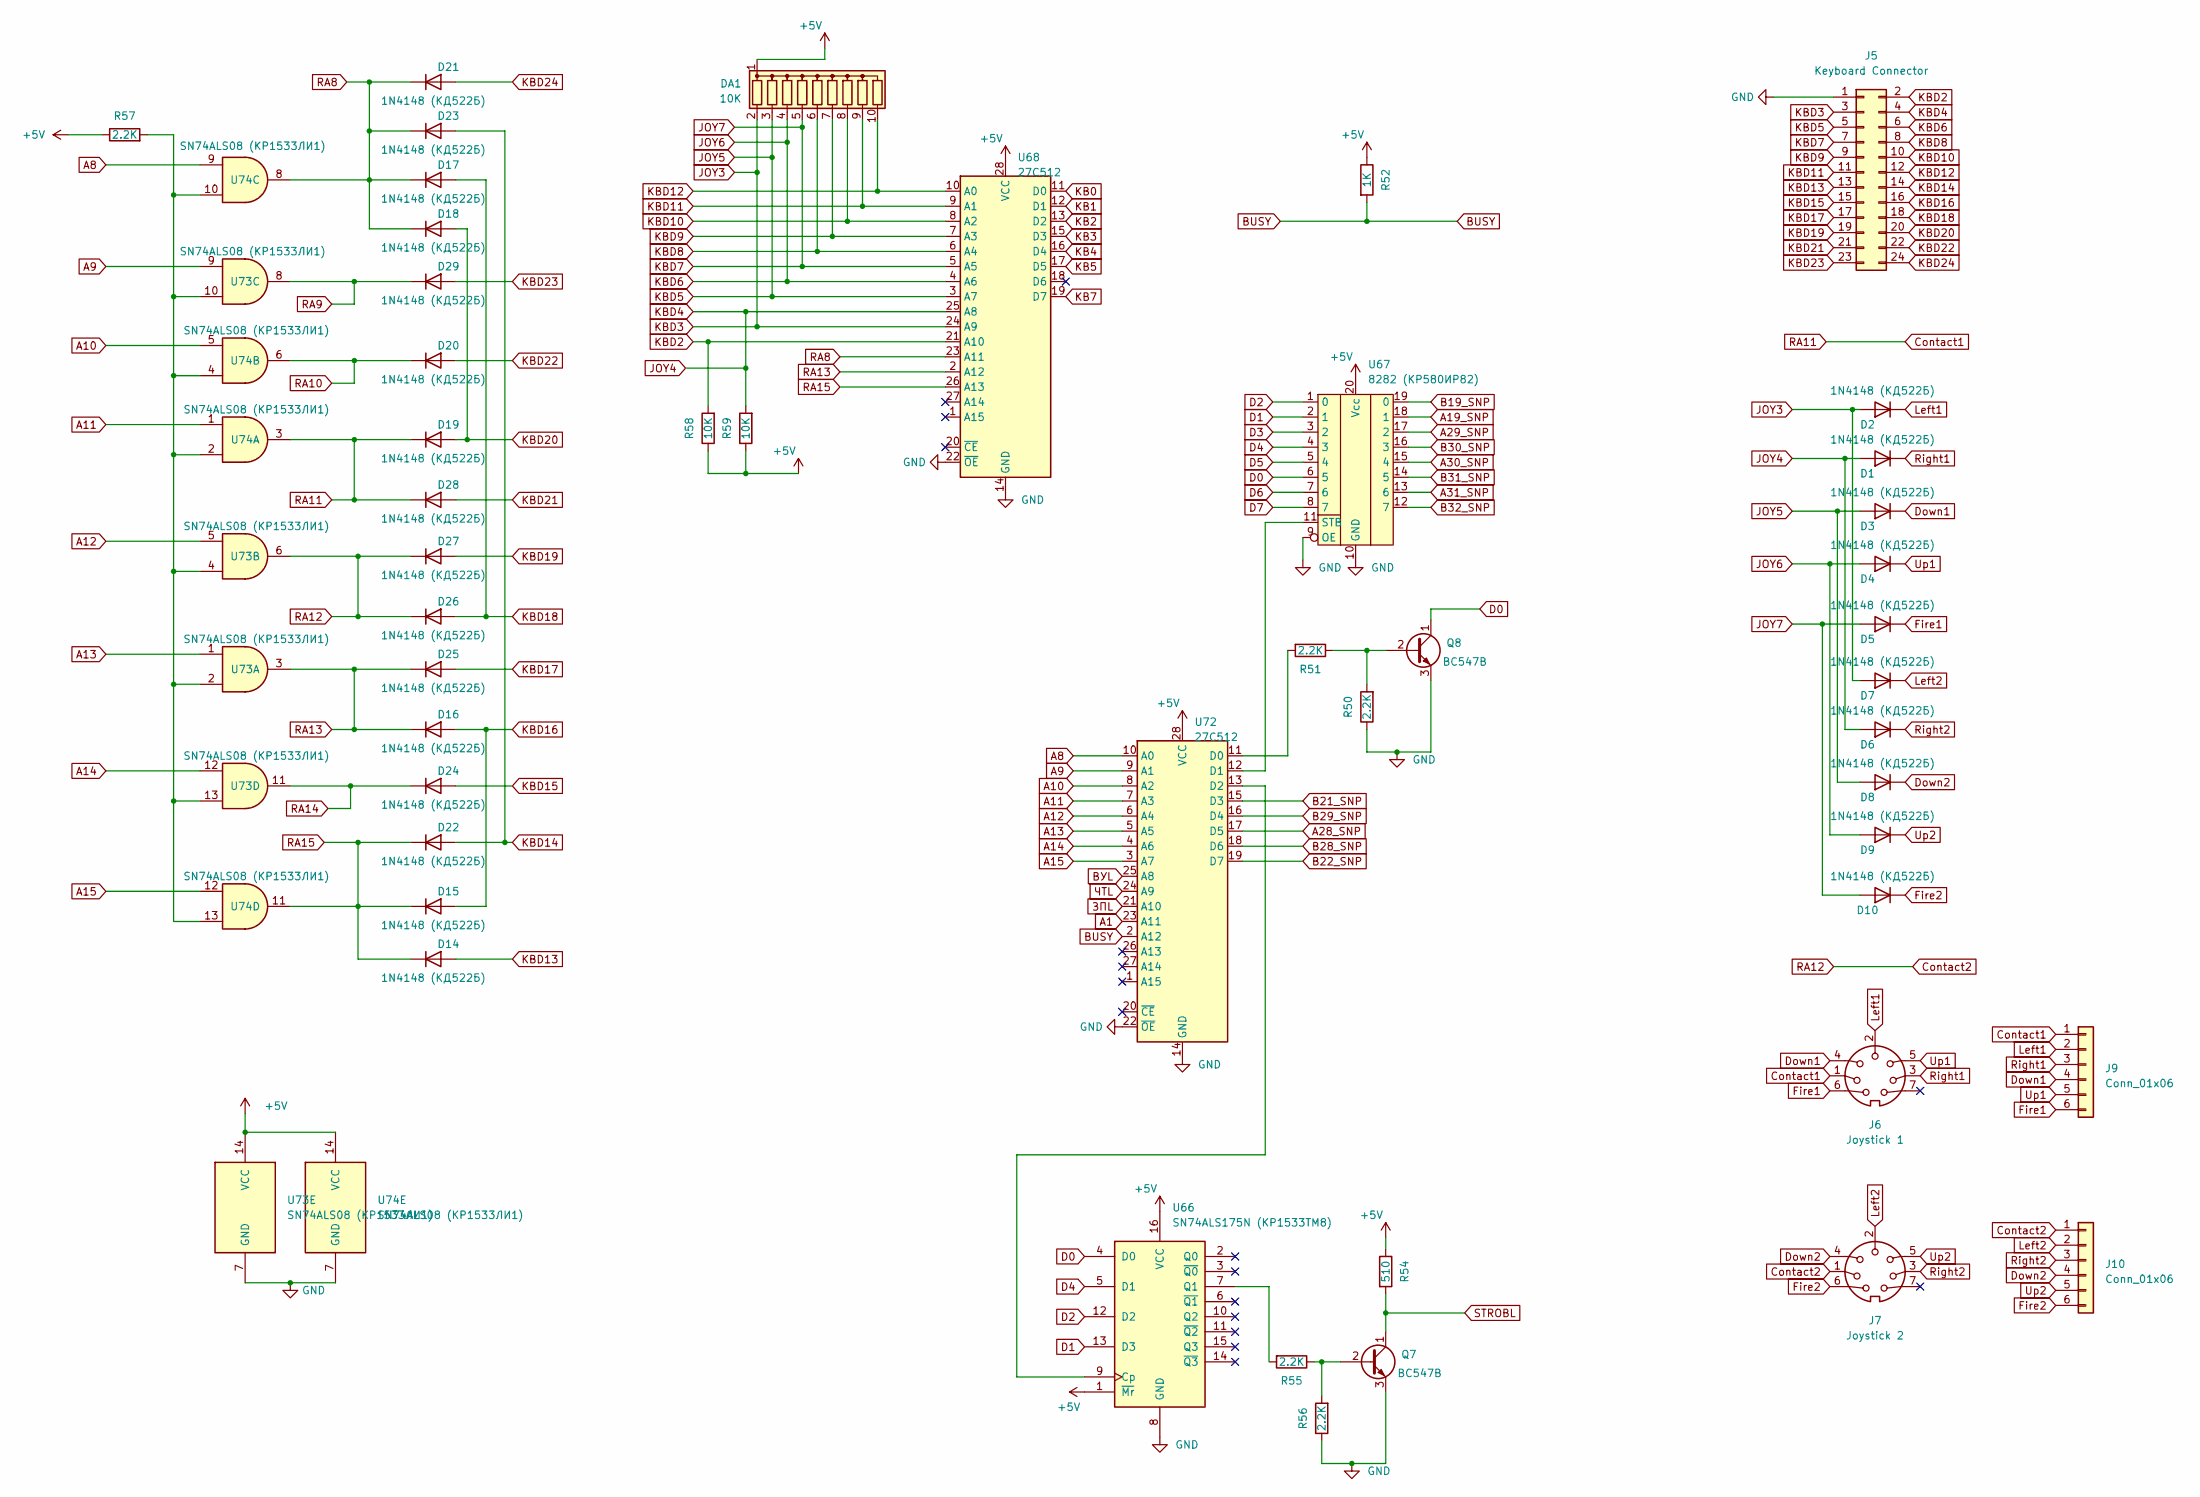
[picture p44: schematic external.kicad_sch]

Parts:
D1, D2, D3, D4, D5, D6, D7, D8, D9, D10, D14, D15, D16, D17, D18, D19, D20, D21, D22, D23, D24, D25, D26, D27, D28, D29: 1N4148 (КД522Б); D_DO-35_SOD27_P10.16mm_Horizontal
DA1: 10K; R_Array_SIP10
J5: Keyboard Connector; IDC-Header_2x12_P2.54mm_Vertical
J6: Joystick 1; DIN-7-Variable
J7: Joystick 2; DIN-7-Variable
J9, J10: Conn_01x06; PinHeader_1x06_P2.54mm_Vertical
Q7, Q8: BC547B; TO-92_Inline
R50, R51, R55, R56, R57: 2.2K; R_Axial_DIN0207_L6.3mm_D2.5mm_P10.16mm_Horizontal
R52: 1K; R_Axial_DIN0207_L6.3mm_D2.5mm_P10.16mm_Horizontal
R54: 510; R_Axial_DIN0207_L6.3mm_D2.5mm_P10.16mm_Horizontal
R58, R59: 10K; R_Axial_DIN0207_L6.3mm_D2.5mm_P10.16mm_Horizontal
U66: SN74ALS175N (КР1533ТМ8); DIP-16_W7.62mm_Socket
U67: 8282 (КР580ИР82); DIP-20_W7.62mm_Socket
U68, U72: 27C512; DIP-28_W15.24mm_Socket
U73, U74: SN74ALS08 (КР1533ЛИ1); DIP-14_W7.62mm_Socket

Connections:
+5V: DA1.1 (common), R52.1, R54.1, R57.1, R58.1, R59.1, U66.1 (~Mr), U66.16 (VCC), U67.20 (Vcc), U68.28 (VCC), U72.28 (VCC), U73.14 (VCC), U74.14 (VCC); also elsewhere on the board
A1: U72.23 (A11); also elsewhere on the board
A8: U72.10 (A0), U74.9; also elsewhere on the board
A9: U72.9 (A1), U73.9; also elsewhere on the board
A10: U72.8 (A2), U74.5; also elsewhere on the board
A11: U72.7 (A3), U74.1; also elsewhere on the board
A12: U72.6 (A4), U73.5; also elsewhere on the board
A13: U72.5 (A5), U73.1; also elsewhere on the board
A14: U72.4 (A6), U73.12; also elsewhere on the board
A15: U72.3 (A7), U74.12; also elsewhere on the board
A19_SNP: U67.18 (1); also elsewhere on the board
A28_SNP: U72.17 (D5); also elsewhere on the board
A29_SNP: U67.17 (2); also elsewhere on the board
A30_SNP: U67.15 (4); also elsewhere on the board
A31_SNP: U67.13 (6); also elsewhere on the board
B19_SNP: U67.19 (0); also elsewhere on the board
B21_SNP: U72.15 (D3); also elsewhere on the board
B22_SNP: U72.19 (D7); also elsewhere on the board
B28_SNP: U72.18 (D6); also elsewhere on the board
B29_SNP: U72.16 (D4); also elsewhere on the board
B30_SNP: U67.16 (3); also elsewhere on the board
B31_SNP: U67.14 (5); also elsewhere on the board
B32_SNP: U67.12 (7); also elsewhere on the board
BUSY: R52.2, U72.2 (A12); also elsewhere on the board
Contact1: D19.1 (K), D28.1 (K), J6.1, J9.1, U74.3
Contact2: D26.1 (K), D27.1 (K), J7.1, J10.1, U73.6
D0: Q8.1 (C), U66.4 (D0), U67.6 (5); also elsewhere on the board
D1: U66.13 (D3), U67.2 (1); also elsewhere on the board
D2: U66.12 (D2), U67.1 (0); also elsewhere on the board
D3: U67.3 (2); also elsewhere on the board
D4: U66.5 (D1), U67.4 (3); also elsewhere on the board
D5: U67.5 (4); also elsewhere on the board
D6: U67.7 (6); also elsewhere on the board
D7: U67.8 (7); also elsewhere on the board
Down1: D3.1 (K), J6.4, J9.4
Down2: D8.1 (K), J7.4, J10.4
Fire1: D5.1 (K), J6.6, J9.6
Fire2: D10.1 (K), J7.6, J10.6
GND: J5.1, Q7.3 (E), Q8.3 (E), R50.1, R56.1, U66.8 (GND), U67.9 (OE), U67.10 (GND), U68.14 (GND), U68.22 (~OE), U72.14 (GND), U72.22 (~OE), U73.7 (GND), U74.7 (GND); also elsewhere on the board
JOY3: D2.2 (A), D7.2 (A), DA1.2 (R1), J5.3, U68.24 (A9)
JOY4: D1.2 (A), D6.2 (A), J5.4, R59.2, U68.25 (A8)
JOY5: D3.2 (A), D8.2 (A), DA1.3 (R2), J5.5, U68.3 (A7)
JOY6: D4.2 (A), D9.2 (A), DA1.4 (R3), J5.6, U68.4 (A6)
JOY7: D5.2 (A), D10.2 (A), DA1.5 (R4), J5.7, U68.5 (A5)
KB0: U68.11 (D0); also elsewhere on the board
KB1: U68.12 (D1); also elsewhere on the board
KB2: U68.13 (D2); also elsewhere on the board
KB3: U68.15 (D3); also elsewhere on the board
KB4: U68.16 (D4); also elsewhere on the board
KB5: U68.17 (D5); also elsewhere on the board
KB7: U68.19 (D7); also elsewhere on the board
KBD2: J5.2, R58.2, U68.21 (A10)
KBD8: DA1.6 (R5), J5.8, U68.6 (A4)
KBD9: DA1.7 (R6), J5.9, U68.7 (A3)
KBD10: DA1.8 (R7), J5.10, U68.8 (A2)
KBD11: DA1.9 (R8), J5.11, U68.9 (A1)
KBD12: DA1.10 (R9), J5.12, U68.10 (A0)
KBD13: D14.2 (A), J5.13
KBD14: D22.2 (A), D23.2 (A), J5.14
KBD15: D24.2 (A), J5.15
KBD16: D15.2 (A), D16.2 (A), J5.16
KBD17: D25.2 (A), J5.17
KBD18: D17.2 (A), D26.2 (A), J5.18
KBD19: D27.2 (A), J5.19
KBD20: D18.2 (A), D19.2 (A), J5.20
KBD21: D28.2 (A), J5.21
KBD22: D20.2 (A), J5.22
KBD23: D29.2 (A), J5.23
KBD24: D21.2 (A), J5.24
Left1: D2.1 (K), J6.2, J9.2
Left2: D7.1 (K), J7.2, J10.2
unnamed: Q7.2 (B), R55.1, R56.2
unnamed: Q8.2 (B), R50.2, R51.1
unnamed: R57.2, U73.2, U73.4, U73.10, U73.13, U74.2, U74.4, U74.10, U74.13
unnamed: U66.9 (Cp), U72.13 (D2)
unnamed: R55.2, U66.7 (Q1)
unnamed: U67.11 (STB), U72.12 (D1)
unnamed: R51.2, U72.11 (D0)
RA8: D17.1 (K), D18.1 (K), D21.1 (K), D23.1 (K), U68.23 (A11), U74.8
RA9: D29.1 (K), U73.8
RA10: D20.1 (K), U74.6
RA13: D16.1 (K), D25.1 (K), U68.2 (A12), U73.3
RA14: D24.1 (K), U73.11
RA15: D14.1 (K), D15.1 (K), D22.1 (K), U68.26 (A13), U74.11
Right1: D1.1 (K), J6.3, J9.3
Right2: D6.1 (K), J7.3, J10.3
STROBL: Q7.1 (C), R54.2; also elsewhere on the board
Up1: D4.1 (K), J6.5, J9.5
Up2: D9.1 (K), J7.5, J10.5
ВУL: U72.25 (A8); also elsewhere on the board
ЗПL: U72.21 (A10); also elsewhere on the board
ЧТL: U72.24 (A9); also elsewhere on the board

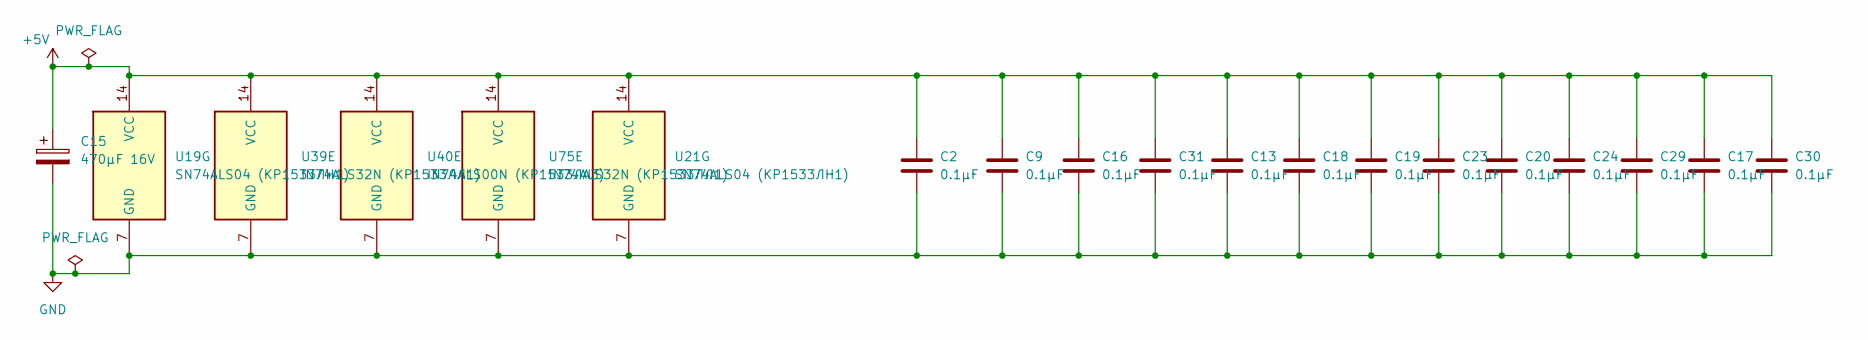
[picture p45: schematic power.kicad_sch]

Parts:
C2, C9, C13, C16, C17, C18, C19, C20, C23, C24, C29, C30, C31: 0.1μF; C_Disc_D7.0mm_W2.5mm_P5.00mm
C15: 470µF 16V; CP_Radial_D10.0mm_P5.00mm
U19, U21: SN74ALS04 (КР1533ЛН1); DIP-14_W7.62mm_Socket
U39, U75: IN74ALS32N (КР1533ЛЛ1); DIP-14_W7.62mm_Socket
U40: IN74ALS00N (КР1533ЛА3); DIP-14_W7.62mm_Socket

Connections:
+5V: C2.1, C9.1, C13.1, C15.1, C16.1, C17.1, C18.1, C19.1, C20.1, C23.1, C24.1, C29.1, C30.1, C31.1, U19.14 (VCC), U21.14 (VCC), U39.14 (VCC), U40.14 (VCC), U75.14 (VCC); also elsewhere on the board
GND: C2.2, C9.2, C13.2, C15.2, C16.2, C17.2, C18.2, C19.2, C20.2, C23.2, C24.2, C29.2, C30.2, C31.2, U19.7 (GND), U21.7 (GND), U39.7 (GND), U40.7 (GND), U75.7 (GND); also elsewhere on the board

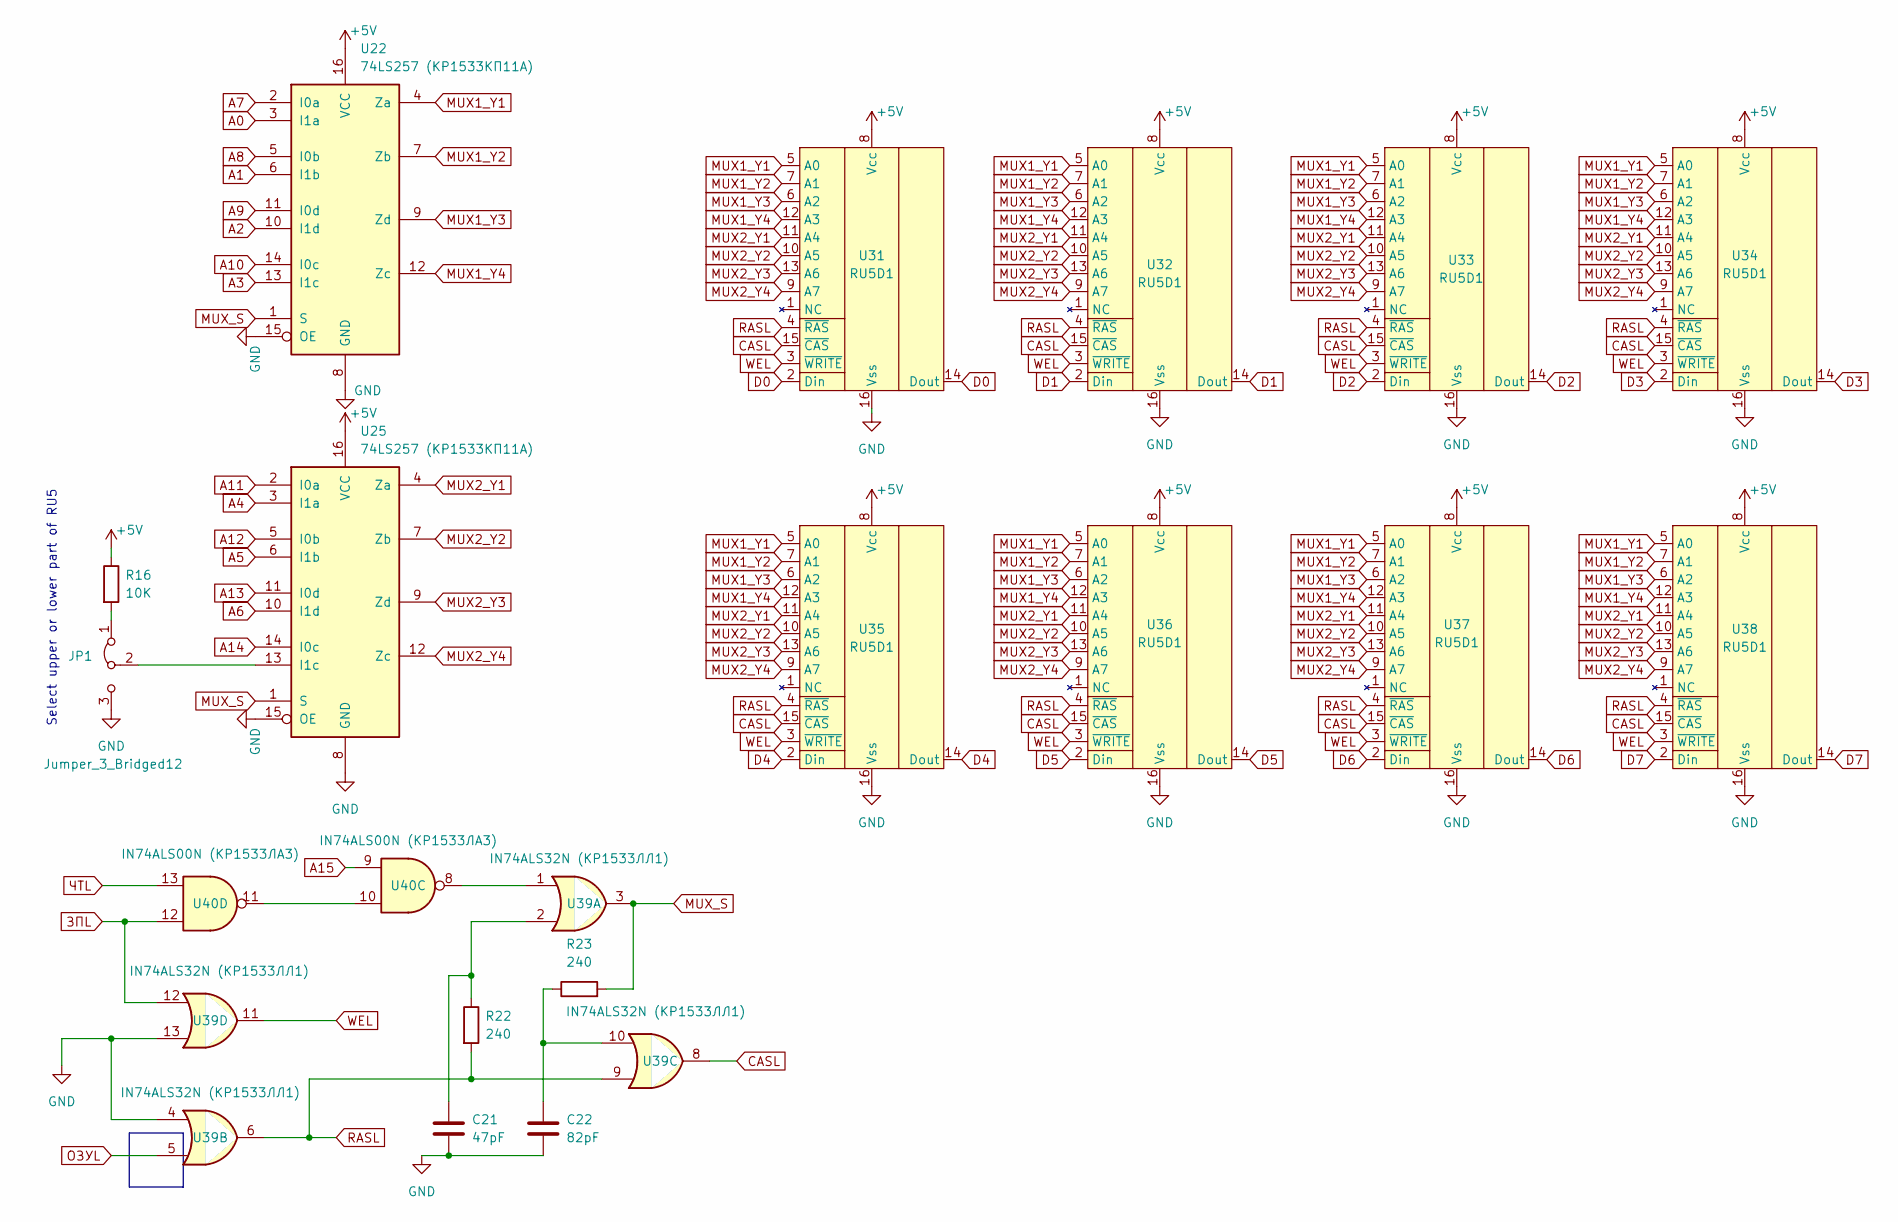
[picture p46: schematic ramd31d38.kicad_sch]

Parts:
C21: 47pF; C_Disc_D7.0mm_W2.5mm_P5.00mm
C22: 82pF; C_Disc_D7.0mm_W2.5mm_P5.00mm
JP1: Jumper_3_Bridged12; PinHeader_1x03_P2.54mm_Vertical
R16: 10K; R_Axial_DIN0207_L6.3mm_D2.5mm_P10.16mm_Horizontal
R22, R23: 240; R_Axial_DIN0207_L6.3mm_D2.5mm_P10.16mm_Horizontal
U22, U25: 74LS257 (КР1533КП11А); DIP-16_W7.62mm_Socket
U31, U32, U33, U34, U35, U36, U37, U38: RU5D1; DIP-16_W7.62mm_Socket
U39: IN74ALS32N (КР1533ЛЛ1); DIP-14_W7.62mm_Socket
U40: IN74ALS00N (КР1533ЛА3); DIP-14_W7.62mm_Socket

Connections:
+5V: R16.1, U22.16 (VCC), U25.16 (VCC), U31.8 (Vcc), U32.8 (Vcc), U33.8 (Vcc), U34.8 (Vcc), U35.8 (Vcc), U36.8 (Vcc), U37.8 (Vcc), U38.8 (Vcc); also elsewhere on the board
A0: U22.3 (I1a); also elsewhere on the board
A1: U22.6 (I1b); also elsewhere on the board
A2: U22.10 (I1d); also elsewhere on the board
A3: U22.13 (I1c); also elsewhere on the board
A4: U25.3 (I1a); also elsewhere on the board
A5: U25.6 (I1b); also elsewhere on the board
A6: U25.10 (I1d); also elsewhere on the board
A7: U22.2 (I0a); also elsewhere on the board
A8: U22.5 (I0b); also elsewhere on the board
A9: U22.11 (I0d); also elsewhere on the board
A10: U22.14 (I0c); also elsewhere on the board
A11: U25.2 (I0a); also elsewhere on the board
A12: U25.5 (I0b); also elsewhere on the board
A13: U25.11 (I0d); also elsewhere on the board
A14: U25.14 (I0c); also elsewhere on the board
A15: U40.9; also elsewhere on the board
CASL: U31.15 (~CAS), U32.15 (~CAS), U33.15 (~CAS), U34.15 (~CAS), U35.15 (~CAS), U36.15 (~CAS), U37.15 (~CAS), U38.15 (~CAS), U39.8
D0: U31.2 (Din), U31.14 (Dout); also elsewhere on the board
D1: U32.2 (Din), U32.14 (Dout); also elsewhere on the board
D2: U33.2 (Din), U33.14 (Dout); also elsewhere on the board
D3: U34.2 (Din), U34.14 (Dout); also elsewhere on the board
D4: U35.2 (Din), U35.14 (Dout); also elsewhere on the board
D5: U36.2 (Din), U36.14 (Dout); also elsewhere on the board
D6: U37.2 (Din), U37.14 (Dout); also elsewhere on the board
D7: U38.2 (Din), U38.14 (Dout); also elsewhere on the board
GND: C21.2, C22.2, JP1.3 (B), U22.8 (GND), U22.15 (OE), U25.8 (GND), U25.15 (OE), U31.16 (Vss), U32.16 (Vss), U33.16 (Vss), U34.16 (Vss), U35.16 (Vss), U36.16 (Vss), U37.16 (Vss), U38.16 (Vss), U39.4, U39.13; also elsewhere on the board
MUX1_Y1: U22.4 (Za), U31.5 (A0), U32.5 (A0), U33.5 (A0), U34.5 (A0), U35.5 (A0), U36.5 (A0), U37.5 (A0), U38.5 (A0)
MUX1_Y2: U22.7 (Zb), U31.7 (A1), U32.7 (A1), U33.7 (A1), U34.7 (A1), U35.7 (A1), U36.7 (A1), U37.7 (A1), U38.7 (A1)
MUX1_Y3: U22.9 (Zd), U31.6 (A2), U32.6 (A2), U33.6 (A2), U34.6 (A2), U35.6 (A2), U36.6 (A2), U37.6 (A2), U38.6 (A2)
MUX1_Y4: U22.12 (Zc), U31.12 (A3), U32.12 (A3), U33.12 (A3), U34.12 (A3), U35.12 (A3), U36.12 (A3), U37.12 (A3), U38.12 (A3)
MUX2_Y1: U25.4 (Za), U31.11 (A4), U32.11 (A4), U33.11 (A4), U34.11 (A4), U35.11 (A4), U36.11 (A4), U37.11 (A4), U38.11 (A4)
MUX2_Y2: U25.7 (Zb), U31.10 (A5), U32.10 (A5), U33.10 (A5), U34.10 (A5), U35.10 (A5), U36.10 (A5), U37.10 (A5), U38.10 (A5)
MUX2_Y3: U25.9 (Zd), U31.13 (A6), U32.13 (A6), U33.13 (A6), U34.13 (A6), U35.13 (A6), U36.13 (A6), U37.13 (A6), U38.13 (A6)
MUX2_Y4: U25.12 (Zc), U31.9 (A7), U32.9 (A7), U33.9 (A7), U34.9 (A7), U35.9 (A7), U36.9 (A7), U37.9 (A7), U38.9 (A7)
MUX_S: R23.2, U22.1 (S), U25.1 (S), U39.3
unnamed: C21.1, R22.1, U39.2
unnamed: C22.1, R23.1, U39.10
unnamed: JP1.1 (A), R16.2
unnamed: JP1.2 (C), U25.13 (I1c)
unnamed: U39.1, U40.8
unnamed: U40.10, U40.11
RASL: R22.2, U31.4 (~RAS), U32.4 (~RAS), U33.4 (~RAS), U34.4 (~RAS), U35.4 (~RAS), U36.4 (~RAS), U37.4 (~RAS), U38.4 (~RAS), U39.6, U39.9
WEL: U31.3 (~WRITE), U32.3 (~WRITE), U33.3 (~WRITE), U34.3 (~WRITE), U35.3 (~WRITE), U36.3 (~WRITE), U37.3 (~WRITE), U38.3 (~WRITE), U39.11
ЗПL: U39.12, U40.12; also elsewhere on the board
ОЗУL: U39.5; also elsewhere on the board
ЧТL: U40.13; also elsewhere on the board

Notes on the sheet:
Select upper or lower part of RU5

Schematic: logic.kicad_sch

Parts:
C1, C6, C8, C12: 120pF; C_Disc_D7.0mm_W2.5mm_P5.00mm
C3: 220pF; C_Disc_D7.0mm_W2.5mm_P5.00mm
C4, C5: 1000pF; C_Disc_D7.0mm_W2.5mm_P5.00mm
C32: 82pF; C_Disc_D7.0mm_W2.5mm_P5.00mm
R1, R2: 470; R_Axial_DIN0207_L6.3mm_D2.5mm_P10.16mm_Horizontal
R4, R8, R9, R13: 160; R_Axial_DIN0207_L6.3mm_D2.5mm_P10.16mm_Horizontal
R5, R6: 10K; R_Axial_DIN0207_L6.3mm_D2.5mm_P10.16mm_Horizontal
R10: 330; R_Axial_DIN0207_L6.3mm_D2.5mm_P10.16mm_Horizontal
R15: 510; R_Axial_DIN0207_L6.3mm_D2.5mm_P10.16mm_Horizontal
R19: 180; R_Axial_DIN0207_L6.3mm_D2.5mm_P10.16mm_Horizontal
U1, U10: SN74ALS08 (КР1533ЛИ1); DIP-14_W7.62mm_Socket
U2, U7, U19, U49: SN74ALS04 (КР1533ЛН1); DIP-14_W7.62mm_Socket
U3, U20: SN74ALS74AN (КР1533ТМ2); DIP-14_W7.62mm_Socket
U4: SN74ALS193N_(КР1533ИЕ7); DIP-16_W7.62mm_Socket
U5: СD4013АN_(К561ТМ2); DIP-14_W7.62mm_Socket
U6: CD4015A (К561ИР2); DIP-16_W7.62mm_Socket
U8, U9: СD4001АN (К561ЛЕ5); DIP-14_W7.62mm_Socket
U11: IN74ALS00N (КР1533ЛА3); DIP-14_W7.62mm_Socket
U12: IN74ALS02N (КР1533ЛЕ1); DIP-14_W7.62mm_Socket
U13: SN74ALS10 (КР1533ЛА4); DIP-14_W7.62mm_Socket
U14: SN74ALS86N (КР1533ЛП5); DIP-14_W7.62mm_Socket
U15, U17: CD4520АN (К561ИЕ10A); DIP-16_W7.62mm_Socket
U16: SN74ALS257N_(КР1533КП11А); DIP-16_W7.62mm_Socket
U18: CD4011 (К561ЛА7); DIP-14_W7.62mm_Socket
U28: IN74ALS32N (КР1533ЛЛ1); DIP-14_W7.62mm_Socket
Y1: 14 MHz; Crystal_HC49-U_Vertical

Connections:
7MHZ: U3.2 (D), U3.6 (~Q), U3.11 (C), U11.5; also elsewhere on the board
+5V: R15.2, U1.14 (VCC), U2.14 (VCC), U3.1 (~R), U3.4 (~S), U3.10 (~S), U3.13 (~R), U3.14 (VCC), U4.4 (DOWN), U4.11 (~LOAD), U4.16 (VCC), U5.14 (Ucc), U6.16 (Vdd), U7.14 (VCC), U8.14 (VDD), U9.14 (VDD), U10.14 (VCC), U11.14 (VCC), U13.14 (VCC), U14.10, U15.10 (Enable), U16.16 (VCC), U17.16 (VDD), U18.14 (VDD), U20.1 (~R), U20.14 (VCC), U28.14 (VCC); also elsewhere on the board
BA0: U4.7 (QD), U13.4, U14.4, U15.9 (CK), U20.11 (C); also elsewhere on the board
BA1: U5.11 (C2), U15.11 (Q1); also elsewhere on the board
BA2: R4.1, R5.1, U15.12 (Q2); also elsewhere on the board
BA3: U15.13 (Q3); also elsewhere on the board
BA4: U5.4 (R1), U6.7 (D), U15.14 (Q4); also elsewhere on the board
BA5: U6.1 (CP), U9.9, U17.2 (Enable), U17.14 (Q4); also elsewhere on the board
BA6: U17.3 (Q1); also elsewhere on the board
BA7: U17.4 (Q2); also elsewhere on the board
BA8: U16.7 (Zb); also elsewhere on the board
BA9: U16.4 (Za); also elsewhere on the board
BA10: U16.9 (Zd); also elsewhere on the board
BA11: U16.12 (Zc); also elsewhere on the board
BA12: U28.8; also elsewhere on the board
BCASL: U1.6; also elsewhere on the board
BMX: U14.11; also elsewhere on the board
BRASL: R9.1, U1.11; also elsewhere on the board
CCML: U17.10 (Enable), U18.10; also elsewhere on the board
CT4: U16.10 (I1d), U17.13 (Q3), U18.13
CT9: U16.2 (I0a), U17.6 (Q4), U18.6, U28.10
GND: C3.1, C4.1, C5.1, C6.1, C8.1, C12.2, C32.1, U1.7 (GND), U2.7 (GND), U3.7 (GND), U4.1 (B), U4.8 (GND), U4.9 (D), U4.10 (C), U4.14 (CLR), U4.15 (A), U5.6 (S1), U5.7 (GND), U5.8 (S2), U5.10 (R2), U6.8 (Vss), U6.14 (MR), U7.7 (GND), U8.7 (VSS), U9.7 (VSS), U10.7 (GND), U11.7 (GND), U13.7 (GND), U14.13, U16.8 (GND), U16.11 (I0d), U16.15 (OE), U17.1 (CK), U17.8 (VSS), U17.9 (CK), U18.7 (VSS), U20.7 (GND), U28.7 (GND); also elsewhere on the board
KGIL: U9.4, U18.1
KKADRAN: U9.11, U17.7 (Reset), U17.15 (Reset), U19.9
KRAIN: U19.12; also elsewhere on the board
KSGIN: U18.3; also elsewhere on the board
unnamed: C1.1, R2.2, U2.6
unnamed: C1.2, R1.1, U2.9
unnamed: C3.2, R4.2, U7.1
unnamed: C4.2, U7.8, U8.8
unnamed: C5.2, R6.1, U9.12
unnamed: C6.2, R10.2, U2.3
unnamed: C8.2, R19.2, U14.9
unnamed: C12.1, R13.1, U19.13
unnamed: C32.2, R8.2, U1.4
unnamed: R2.1, U2.5, Y1.1
unnamed: R6.2, U7.6
unnamed: R8.1, U1.13, U14.8
unnamed: R9.2, U14.12
unnamed: R10.1, U13.8, U19.3
unnamed: U1.5, U11.11
unnamed: U1.10, U2.2
unnamed: R1.2, U2.8, U3.3 (C), Y1.2
unnamed: U1.12, U3.12 (D), U13.12
unnamed: U4.3 (QA), U11.4, U11.10, U12.5, U19.5
unnamed: U4.2 (QB), U11.9, U12.6
unnamed: U1.9, U4.6 (QC), U13.5, U14.5
unnamed: R5.2, U5.3 (C1)
unnamed: U5.5 (D1), U6.3 (Q3), U8.5
unnamed: U5.1 (Q1), U5.9 (D2), U18.9
unnamed: U5.12 (Q2o), U18.2
unnamed: U6.9 (CP), U7.2, U18.8
unnamed: U6.10 (Q4), U7.9, U8.6, U8.9
unnamed: U6.15 (D), U7.13, U18.4
unnamed: U6.13 (Q1), U9.2
unnamed: U6.11 (Q3), U8.12
unnamed: U6.2 (Q4), U7.3, U9.1
unnamed: U7.4, U7.5, U8.1, U8.13, U9.13
unnamed: U7.10, U9.8
unnamed: U7.11, U8.11
unnamed: U7.12, U8.2
unnamed: U9.3, U9.5
unnamed: U10.1, U19.6
unnamed: U10.3, U49.1
unnamed: U8.3, U10.4
unnamed: U8.4, U10.5
unnamed: U10.13, U13.6
unnamed: U2.1, U11.8, U13.2, U13.3
unnamed: U11.6, U11.12
unnamed: U2.13, U12.4
unnamed: U2.12, U13.9, U13.10
unnamed: U13.11, U13.13, U14.6
unnamed: U6.6 (MR), U8.10, U15.15 (Reset)
unnamed: U16.5 (I0b), U16.13 (I1c), U17.5 (Q3), U18.5
unnamed: U16.3 (I1a), U17.12 (Q2)
unnamed: U16.6 (I1b), U17.11 (Q1)
unnamed: U9.6, U9.10, U18.12
unnamed: U19.10, U28.9
unnamed: U3.5 (Q), U4.5 (UP), U20.3 (C)
unnamed: U10.2, U20.5 (Q)
unnamed: U10.11, U20.4 (~S)
unnamed: U10.6, U10.12, U13.1, U20.12 (D)
unnamed: R13.2, U20.9 (Q)
unnamed: U20.10 (~S), U20.13 (~R)
OZUMPN: R19.1; also elsewhere on the board
TAIMS: U18.11; also elsewhere on the board
UPRMX: U16.1 (S), U19.4, U19.11
VOZUL: U20.2 (D); also elsewhere on the board
ZPRGAT+: U2.4; also elsewhere on the board
ZPRGBD: U3.8 (~Q), U11.13; also elsewhere on the board
ZPVDN: U1.8; also elsewhere on the board
ПРL: U19.8; also elsewhere on the board
ТАКТ: R15.1, U49.2; also elsewhere on the board

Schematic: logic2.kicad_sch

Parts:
C10, C11: 0.1µF; C_Disc_D7.0mm_W2.5mm_P5.00mm
C14: 4.7µF 16V; CP_Radial_D4.0mm_P2.00mm
D11, D12, D13, D30, D31: 1N4148 (КД522Б); D_DO-35_SOD27_P10.16mm_Horizontal
JP4, JP5: Jumper_2_Open; PinHeader_1x02_P2.54mm_Vertical
R11: 39K; R_Axial_DIN0207_L6.3mm_D2.5mm_P10.16mm_Horizontal
R12: 100K; R_Axial_DIN0207_L6.3mm_D2.5mm_P10.16mm_Horizontal
R20: 560; R_Axial_DIN0207_L6.3mm_D2.5mm_P10.16mm_Horizontal
R21: 10K; R_Axial_DIN0207_L6.3mm_D2.5mm_P10.16mm_Horizontal
R32, R35, R36, R39: 470; R_Axial_DIN0207_L6.3mm_D2.5mm_P10.16mm_Horizontal
R34, R38, R41: 2.7K; R_Axial_DIN0207_L6.3mm_D2.5mm_P10.16mm_Horizontal
R45, R46: 1K; R_Axial_DIN0207_L6.3mm_D2.5mm_P10.16mm_Horizontal
U12, U30: IN74ALS02N (КР1533ЛЕ1); DIP-14_W7.62mm_Socket
U14, U50: SN74ALS86N (КР1533ЛП5); DIP-14_W7.62mm_Socket
U15: CD4520АN (К561ИЕ10A); DIP-16_W7.62mm_Socket
U21, U49: SN74ALS04 (КР1533ЛН1); DIP-14_W7.62mm_Socket
U29: IN74ALS32N (КР1533ЛЛ1); DIP-14_W7.62mm_Socket
U40: IN74ALS00N (КР1533ЛА3); DIP-14_W7.62mm_Socket
U51: SN7486N (К155ЛП5); DIP-14_W7.62mm_Socket
U52, U56, U59, U63: SN74ALS175N (КР1533ТМ8); DIP-16_W7.62mm_Socket
U53, U60: SN74ALS153N (КР1533КП2); DIP-16_W7.62mm_Socket
U54, U61: SN74ALS298N (КР1533КП13); DIP-16_W7.62mm_Socket
U55, U62: 74LS257 (КР1533КП11А); DIP-16_W7.62mm_Socket
U57, U58, U64, U65: SN74LS295N_(К555ИР16); DIP-14_W7.62mm_Socket

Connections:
7MHZ: U54.11 (Cp), U58.9 (Cp), U61.11 (Cp), U65.9 (Cp); also elsewhere on the board
+5V: R45.2, R46.2, U12.14 (VCC), U14.14 (VCC), U15.2 (Enable), U15.16 (VDD), U29.14 (VCC), U30.14 (VCC), U49.14 (VCC), U50.14 (VCC), U51.14 (VCC), U52.1 (~Mr), U52.16 (VCC), U53.16 (VCC), U54.16 (VCC), U55.16 (VCC), U56.1 (~Mr), U56.16 (VCC), U57.6 (Pe), U57.8 (OE), U57.14 (VCC), U58.8 (OE), U58.14 (VCC), U59.1 (~Mr), U59.16 (VCC), U60.16 (VCC), U61.16 (VCC), U62.16 (VCC), U63.1 (~Mr), U63.16 (VCC), U64.6 (Pe), U64.8 (OE), U64.14 (VCC), U65.8 (OE), U65.14 (VCC); also elsewhere on the board
A0: U12.3; also elsewhere on the board
A14: U49.5; also elsewhere on the board
A15: U29.1; also elsewhere on the board
BD0: U62.14 (I0c), U63.4 (D0), U64.2 (P0); also elsewhere on the board
BD1: U62.2 (I0a), U63.5 (D1), U64.3 (P1); also elsewhere on the board
BD2: U62.5 (I0b), U63.12 (D2), U64.4 (P2); also elsewhere on the board
BD3: U55.2 (I0a), U63.13 (D3), U64.5 (P3); also elsewhere on the board
BD4: U56.4 (D0), U57.2 (P0), U62.11 (I0d); also elsewhere on the board
BD5: U55.5 (I0b), U56.5 (D1), U57.3 (P1); also elsewhere on the board
BD6: U55.11 (I0d), U56.12 (D2), U57.4 (P2); also elsewhere on the board
BD7: U55.14 (I0c), U56.13 (D3), U57.5 (P3); also elsewhere on the board
BWEL: U40.3; also elsewhere on the board
CCML: U14.2; also elsewhere on the board
CHTRGL: U29.8, U55.15 (OE), U62.15 (OE)
D0: U52.4 (D0), U62.12 (Zc); also elsewhere on the board
D1: U52.12 (D1), U62.4 (Za); also elsewhere on the board
D2: U52.13 (D2), U62.7 (Zb); also elsewhere on the board
D3: U55.4 (Za), U59.4 (D0); also elsewhere on the board
D4: U52.5 (D3), U62.9 (Zd); also elsewhere on the board
D5: U55.7 (Zb); also elsewhere on the board
D6: U55.9 (Zd); also elsewhere on the board
D7: U55.12 (Zc); also elsewhere on the board
GND: JP4.2 (B), JP5.2 (B), U12.7 (GND), U14.7 (GND), U15.7 (Reset), U15.8 (VSS), U29.7 (GND), U30.5, U30.7 (GND), U49.7 (GND), U50.7 (GND), U51.7 (GND), U52.8 (GND), U53.8 (GND), U53.12 (I2b), U53.13 (I3b), U54.8 (GND), U55.8 (GND), U56.8 (GND), U57.7 (GND), U58.7 (GND), U59.8 (GND), U60.8 (GND), U61.8 (GND), U62.8 (GND), U63.8 (GND), U64.7 (GND), U65.1 (Ds), U65.7 (GND); also elsewhere on the board
KB0: U62.13 (I1c); also elsewhere on the board
KB1: U62.3 (I1a); also elsewhere on the board
KB2: U62.6 (I1b); also elsewhere on the board
KB3: U55.3 (I1a); also elsewhere on the board
KB4: U62.10 (I1d); also elsewhere on the board
KB5: U55.6 (I1b); also elsewhere on the board
KB7: U55.13 (I1c); also elsewhere on the board
KRAIN: U53.2 (S1), U60.2 (S1); also elsewhere on the board
KSGIN: U53.1 (Ea), U53.15 (Eb), U60.1 (Ea), U60.15 (Eb); also elsewhere on the board
MAG: R12.2, U21.6, U55.10 (I1d)
MAG_IN: R20.1; also elsewhere on the board
MAG_OUT: R21.2; also elsewhere on the board
unnamed: C10.1, R11.2, U21.4
unnamed: C10.2, R12.1, U21.5
unnamed: C11.2, R11.1, U21.3
unnamed: C14.2, R20.2
unnamed: D11.1 (K), R34.2
unnamed: D12.1 (K), R38.2
unnamed: D13.1 (K), R41.2
unnamed: C14.1, D30.2 (A), D31.1 (K), U21.1
unnamed: C11.1, D30.1 (K), D31.2 (A), U21.2
unnamed: JP4.1 (A), R46.1, U51.1
unnamed: JP5.1 (A), R45.1, U51.5, U51.10, U51.13
unnamed: R32.1, U51.6
unnamed: R35.1, U51.3
unnamed: R36.1, U51.8
unnamed: R39.1, U51.11
unnamed: U14.3, U49.13
unnamed: U15.6 (Q4), U40.5
unnamed: U29.2, U49.6
unnamed: U29.10, U30.1
unnamed: U29.3, U29.12, U30.12
unnamed: U30.4, U40.2
unnamed: U30.8, U49.8
unnamed: U40.6, U50.9
unnamed: U49.12, U51.2
unnamed: U52.2 (Q0), U60.3 (I3a), U60.4 (I2a)
unnamed: U52.10 (Q2), U60.12 (I2b), U60.13 (I3b)
unnamed: U52.15 (Q3), U53.3 (I3a), U53.4 (I2a)
unnamed: U53.6 (I0a), U61.9 (I0c), U61.13 (Qc)
unnamed: U53.10 (I0b), U53.11 (I1b), U54.9 (I0c), U54.13 (Qc)
unnamed: U53.5 (I1a), U54.7 (I0d), U54.12 (Qd)
unnamed: U50.8, U53.14 (S0), U60.14 (S0)
unnamed: U51.12, U53.7 (Za)
unnamed: R34.1, R38.1, R41.1, U53.9 (Zb)
unnamed: U54.3 (I0a), U54.15 (Qa), U60.11 (I1b)
unnamed: U40.4, U54.4 (I0b), U54.14 (Qb)
unnamed: U54.2 (I1a), U56.2 (Q0)
unnamed: U54.1 (I1b), U56.15 (Q3)
unnamed: U54.5 (I1c), U56.10 (Q2)
unnamed: U54.6 (I1d), U56.7 (Q1)
unnamed: U57.13 (Q0), U58.2 (P0)
unnamed: U57.12 (Q1), U58.3 (P1)
unnamed: U57.11 (Q2), U58.4 (P2)
unnamed: U57.10 (Q3), U58.5 (P3)
unnamed: U58.1 (Ds), U65.10 (Q3)
unnamed: U50.10, U58.10 (Q3)
unnamed: R21.1, U59.2 (Q0)
unnamed: U60.6 (I0a), U61.3 (I0a), U61.15 (Qa)
unnamed: U60.10 (I0b), U61.7 (I0d), U61.12 (Qd)
unnamed: U60.5 (I1a), U61.4 (I0b), U61.14 (Qb)
unnamed: U51.9, U60.7 (Za)
unnamed: U51.4, U60.9 (Zb)
unnamed: U61.2 (I1a), U63.2 (Q0)
unnamed: U61.1 (I1b), U63.15 (Q3)
unnamed: U61.5 (I1c), U63.10 (Q2)
unnamed: U61.6 (I1d), U63.7 (Q1)
unnamed: U64.13 (Q0), U65.2 (P0)
unnamed: U64.12 (Q1), U65.3 (P1)
unnamed: U64.11 (Q2), U65.4 (P2)
unnamed: U64.10 (Q3), U65.5 (P3)
OZUMPN: U29.13, U30.2, U30.13, U40.1; also elsewhere on the board
SYNCRO: R35.2; also elsewhere on the board
TAIMS: U14.1, U15.1 (CK); also elsewhere on the board
UZVUK: U52.7 (Q1); also elsewhere on the board
VIBOZUL: U12.1, U30.3, U49.9, U55.1 (S), U62.1 (S)
VOZUL: U29.11; also elsewhere on the board
YB: D13.2 (A), R39.2; also elsewhere on the board
YG: D12.2 (A), R36.2; also elsewhere on the board
YR: D11.2 (A), R32.2; also elsewhere on the board
ZPRG+: U30.10, U52.9 (Cp), U59.9 (Cp)
ZPRGAT+: U56.9 (Cp), U63.9 (Cp); also elsewhere on the board
ZPRGBD: U57.9 (Cp), U64.9 (Cp); also elsewhere on the board
ZPVDN: U54.10 (S), U58.6 (Pe), U61.10 (S), U65.6 (Pe); also elsewhere on the board
ВУL: U12.2; also elsewhere on the board
ЗПL: U30.6, U30.9; also elsewhere on the board
ОЗУL: U30.11; also elsewhere on the board
ЧТL: U29.9; also elsewhere on the board

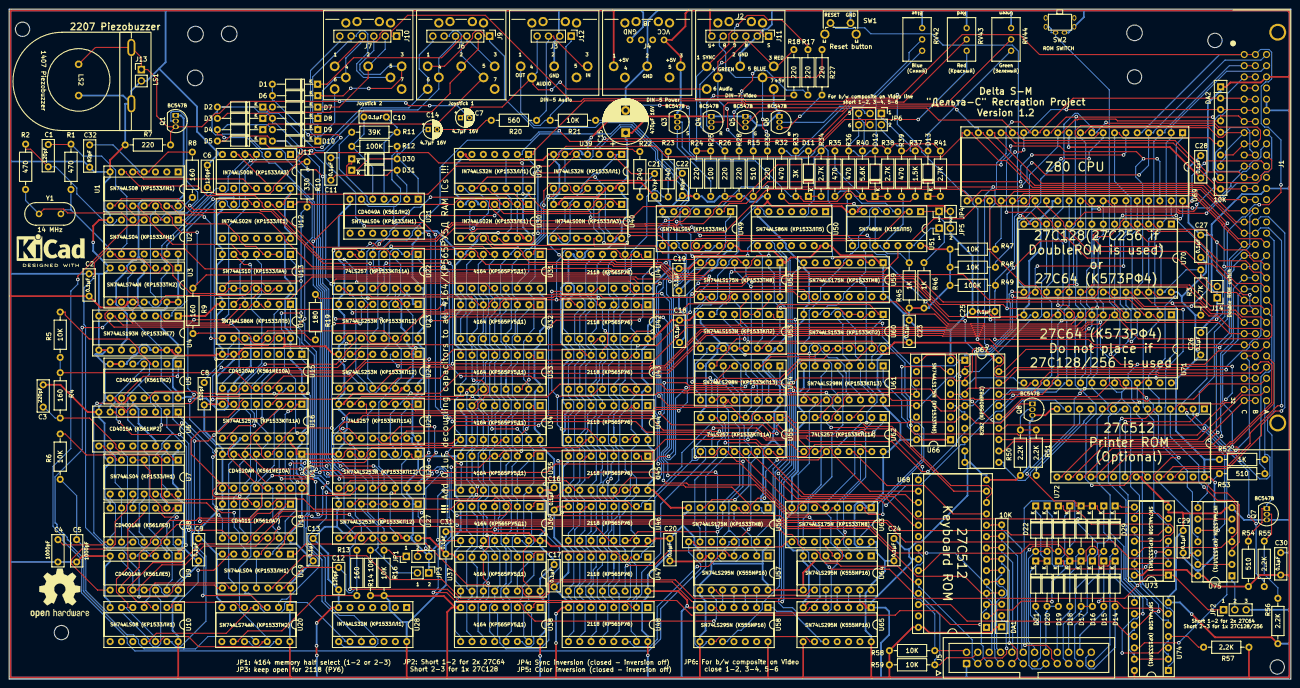
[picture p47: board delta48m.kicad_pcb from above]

Board: 2 copper layers, 287.0 x 150.0 mm, 240 parts (0 on the bottom side), 329 nets.

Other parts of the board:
H1, H7, H10: MountingHole_3.5mm
H3, H4, H5, H6, H9: MountingHole_3.2mm_M3
H8: MountingHole_3mm
Log1: KiCad-Logo2_6mm_SilkScreen
Log2: OSHW-Logo2_14.6x12mm_SilkScreen

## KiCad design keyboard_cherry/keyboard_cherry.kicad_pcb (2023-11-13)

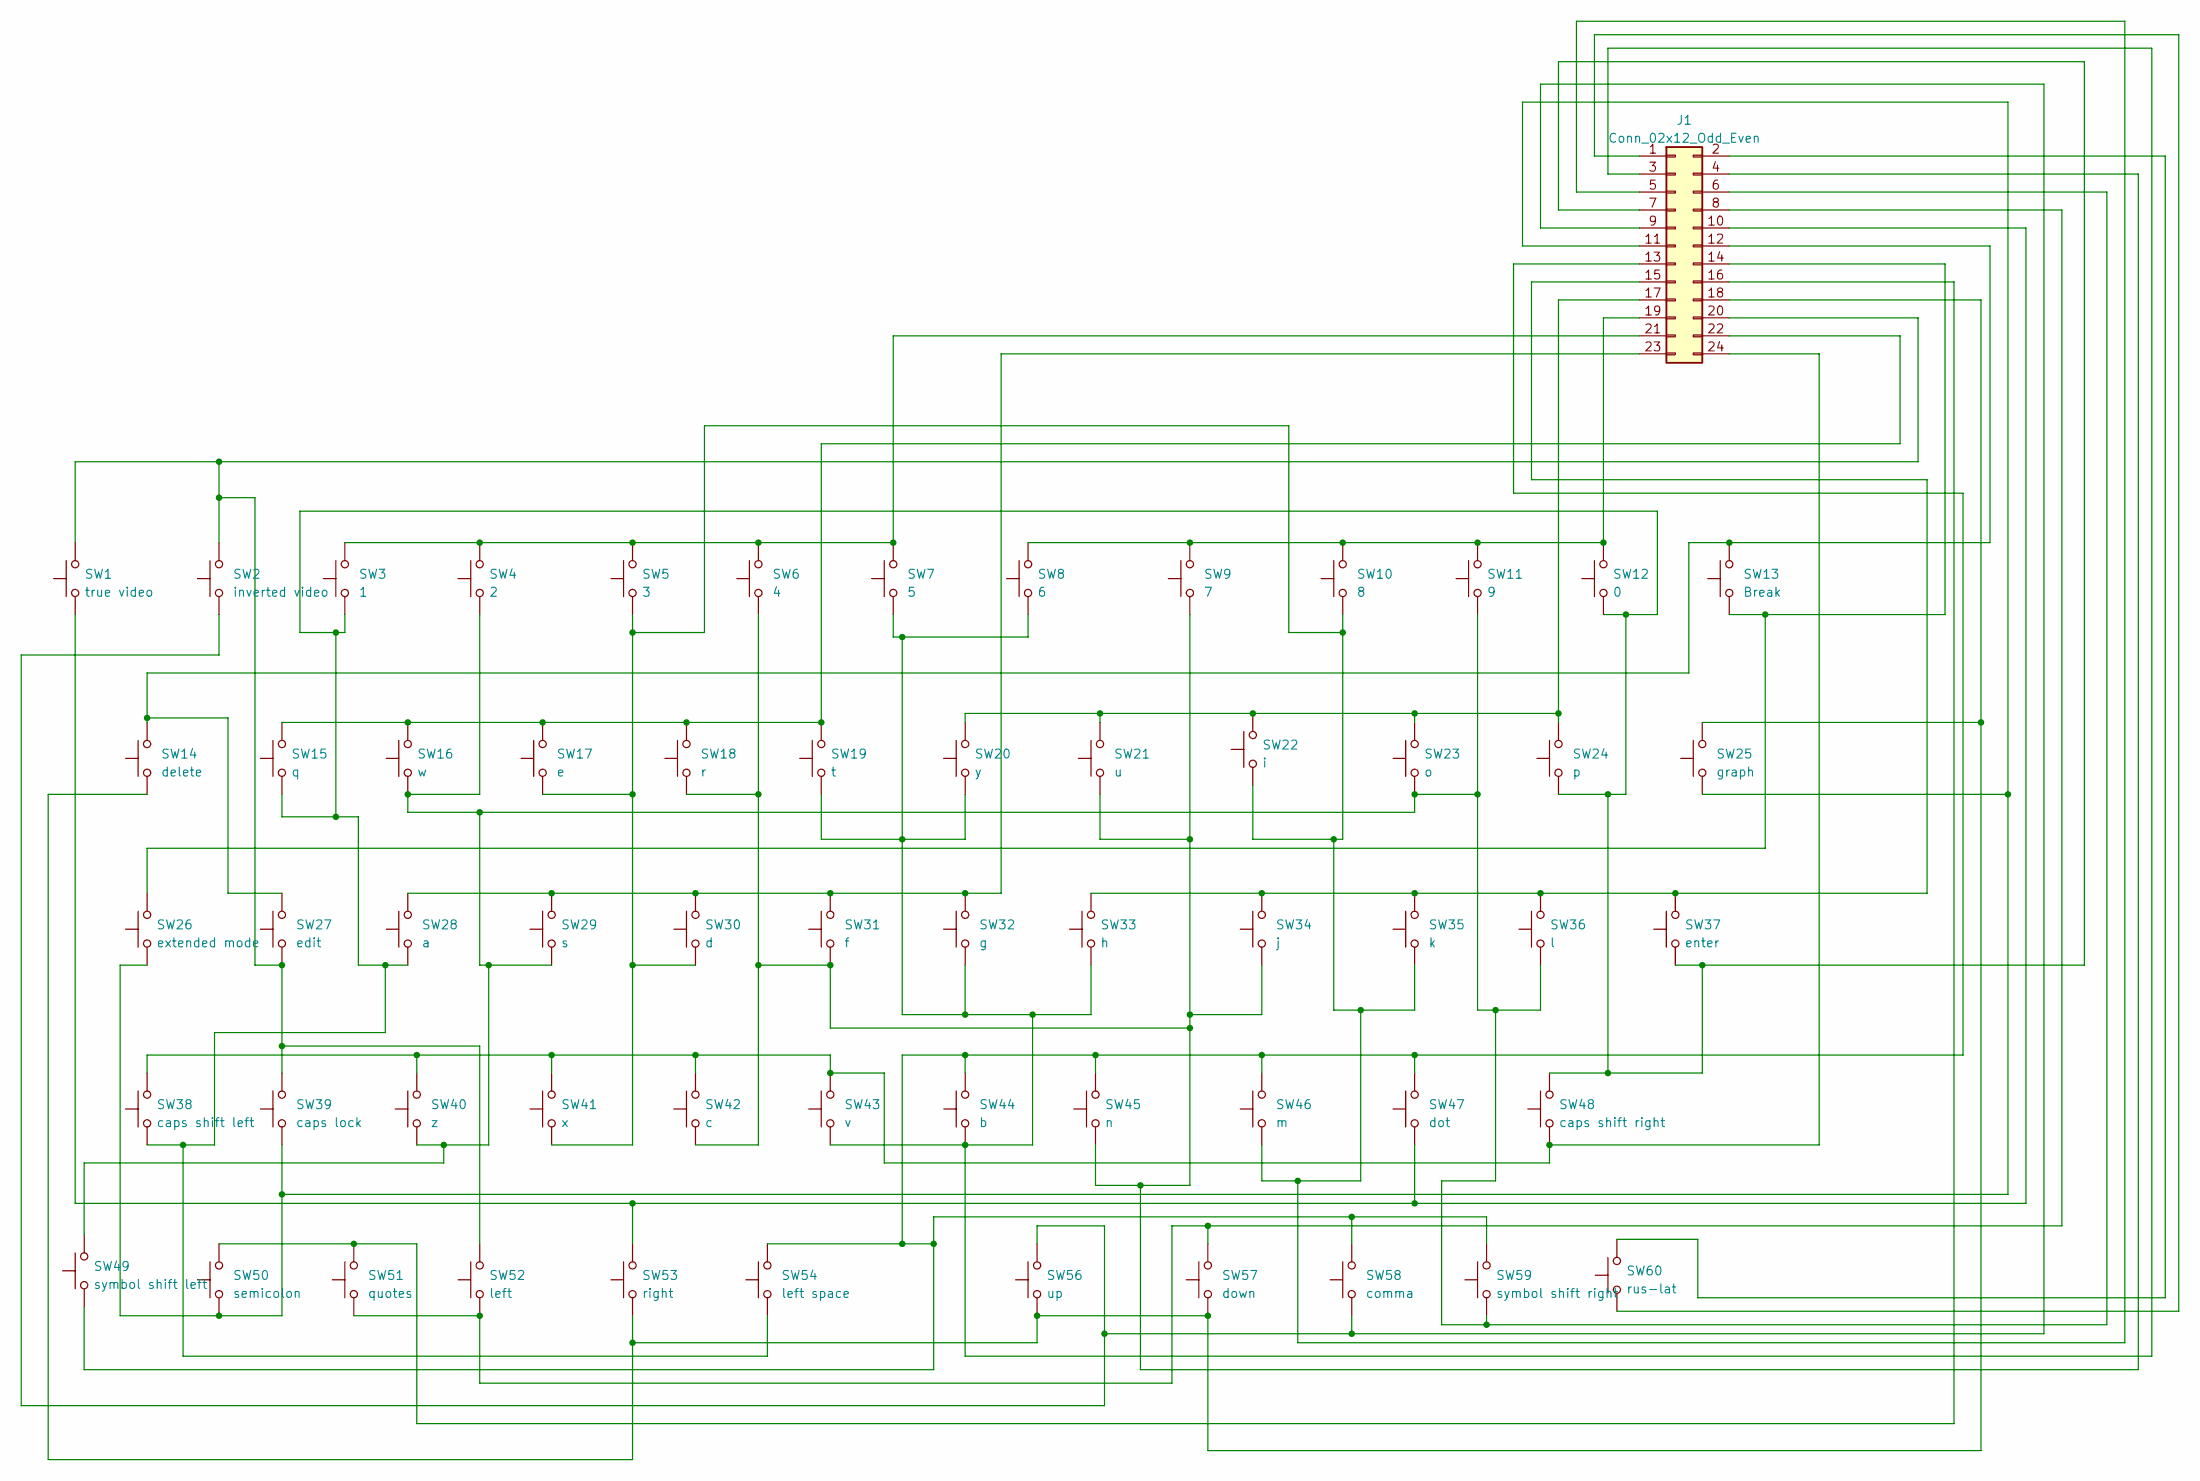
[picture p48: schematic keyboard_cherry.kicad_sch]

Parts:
J1: Conn_02x12_Odd_Even; IDC-Header_2x12_P2.54mm_Vertical
SW1: true video; SW_Cherry_MX_1.50u_PCB
SW2: inverted video; SW_Cherry_MX_1.50u_PCB
SW3: 1; SW_Cherry_MX_1.00u_PCB
SW4: 2; SW_Cherry_MX_1.00u_PCB
SW5: 3; SW_Cherry_MX_1.00u_PCB
SW6: 4; SW_Cherry_MX_1.00u_PCB
SW7: 5; SW_Cherry_MX_1.00u_PCB
SW8: 6; SW_Cherry_MX_1.00u_PCB
SW9: 7; SW_Cherry_MX_1.00u_PCB
SW10: 8; SW_Cherry_MX_1.00u_PCB
SW11: 9; SW_Cherry_MX_1.00u_PCB
SW12: 0; SW_Cherry_MX_1.00u_PCB
SW13: Break; SW_Cherry_MX_1.00u_PCB
SW14: delete; SW_Cherry_MX_2.00u_PCB
SW15: q; SW_Cherry_MX_1.00u_PCB
SW16: w; SW_Cherry_MX_1.00u_PCB
SW17: e; SW_Cherry_MX_1.00u_PCB
SW18: r; SW_Cherry_MX_1.00u_PCB
SW19: t; SW_Cherry_MX_1.00u_PCB
SW20: y; SW_Cherry_MX_1.00u_PCB
SW21: u; SW_Cherry_MX_1.00u_PCB
SW22: i; SW_Cherry_MX_1.00u_PCB
SW23: o; SW_Cherry_MX_1.00u_PCB
SW24: p; SW_Cherry_MX_1.00u_PCB
SW25: graph; SW_Cherry_MX_1.00u_PCB
SW26: extended mode; SW_Cherry_MX_1.75u_PCB
SW27: edit; SW_Cherry_MX_1.50u_PCB
SW28: a; SW_Cherry_MX_1.00u_PCB
SW29: s; SW_Cherry_MX_1.00u_PCB
SW30: d; SW_Cherry_MX_1.00u_PCB
SW31: f; SW_Cherry_MX_1.00u_PCB
SW32: g; SW_Cherry_MX_1.00u_PCB
SW33: h; SW_Cherry_MX_1.00u_PCB
SW34: j; SW_Cherry_MX_1.00u_PCB
SW35: k; SW_Cherry_MX_1.00u_PCB
SW36: l; SW_Cherry_MX_1.00u_PCB
SW37: enter; SW_Cherry_MX_1.75u_PCB
SW38: caps shift left; SW_Cherry_MX_2.25u_PCB
SW39: caps lock; SW_Cherry_MX_1.00u_PCB
SW40: z; SW_Cherry_MX_1.00u_PCB
SW41: x; SW_Cherry_MX_1.00u_PCB
SW42: c; SW_Cherry_MX_1.00u_PCB
SW43: v; SW_Cherry_MX_1.00u_PCB
SW44: b; SW_Cherry_MX_1.00u_PCB
SW45: n; SW_Cherry_MX_1.00u_PCB
SW46: m; SW_Cherry_MX_1.00u_PCB
SW47: dot; SW_Cherry_MX_1.00u_PCB
SW48: caps shift right; SW_Cherry_MX_2.25u_PCB
SW49: symbol shift left; SW_Cherry_MX_2.00u_PCB
SW50: semicolon; SW_Cherry_MX_1.00u_PCB
SW51: quotes; SW_Cherry_MX_1.00u_PCB
SW52: left; SW_Cherry_MX_1.00u_PCB
SW53: right; SW_Cherry_MX_1.00u_PCB
SW54: left space; SW_Cherry_MX_6.25u_PCB
SW56: up; SW_Cherry_MX_1.00u_PCB
SW57: down; SW_Cherry_MX_1.00u_PCB
SW58: comma; SW_Cherry_MX_1.00u_PCB
SW59: symbol shift right; SW_Cherry_MX_1.25u_PCB
SW60: rus-lat; SW_Cherry_MX_1.50u_PCB

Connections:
unnamed: J1.1, SW60.1
unnamed: J1.2, SW60.2
unnamed: J1.3, SW7.1, SW8.1, SW19.1, SW20.1, SW32.1, SW33.1, SW43.1, SW44.1
unnamed: J1.4, SW6.1, SW9.1, SW18.1, SW21.1, SW31.1, SW34.1, SW42.1, SW45.1
unnamed: J1.5, SW5.1, SW10.1, SW17.1, SW22.1, SW30.1, SW35.1, SW41.1, SW46.1
unnamed: J1.6, SW4.1, SW11.1, SW16.1, SW23.1, SW29.1, SW36.1, SW40.1, SW49.2, SW59.1
unnamed: J1.7, SW3.1, SW12.1, SW15.1, SW24.1, SW28.1, SW37.1, SW38.1, SW48.2, SW54.1
unnamed: J1.8, SW51.1, SW52.1, SW57.2
unnamed: J1.9, SW2.1, SW56.2, SW58.1
unnamed: J1.10, SW1.1, SW47.1, SW53.2
unnamed: J1.11, SW25.1, SW26.1, SW39.1, SW50.1
unnamed: J1.12, SW13.2, SW14.2, SW27.2
unnamed: J1.13, SW44.2, SW45.2, SW46.2, SW47.2, SW49.1, SW54.2, SW58.2, SW59.2
unnamed: J1.14, SW13.1, SW26.2
unnamed: J1.15, SW33.2, SW34.2, SW35.2, SW36.2, SW37.2
unnamed: J1.16, SW50.2, SW51.2
unnamed: J1.17, SW20.2, SW21.2, SW22.2, SW23.2, SW24.2
unnamed: J1.18, SW14.1, SW25.2, SW53.1, SW56.1, SW57.1
unnamed: J1.19, SW8.2, SW9.2, SW10.2, SW11.2, SW12.2
unnamed: J1.20, SW1.2, SW2.2, SW27.1, SW39.2, SW52.2
unnamed: J1.21, SW3.2, SW4.2, SW5.2, SW6.2, SW7.2
unnamed: J1.22, SW15.2, SW16.2, SW17.2, SW18.2, SW19.2
unnamed: J1.23, SW28.2, SW29.2, SW30.2, SW31.2, SW32.2
unnamed: J1.24, SW38.2, SW40.2, SW41.2, SW42.2, SW43.2, SW48.1

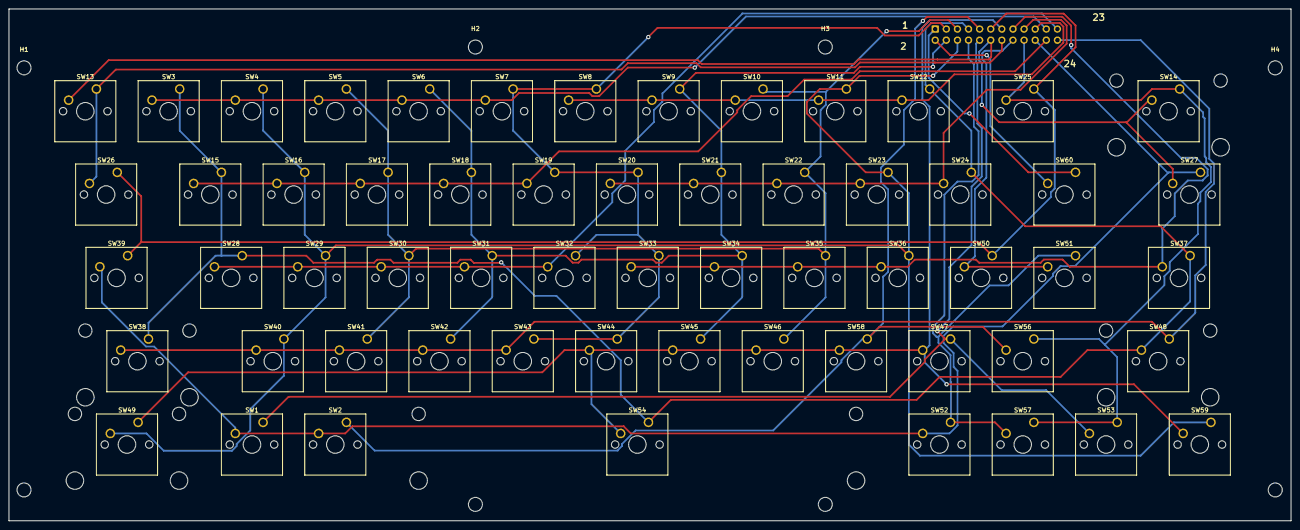
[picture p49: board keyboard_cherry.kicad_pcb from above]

Board: 2 copper layers, 293.1 x 117.0 mm, 68 parts (1 on the bottom side), 24 nets.

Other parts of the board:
H1, H2, H3, H5, H6, H7: MountingHole_3.2mm_M3
H4, H8: MountingHole_3.2mm; MountingHole_3.2mm_M3

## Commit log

2023-03-17 Initial version
    [ROM.kicad_sch, SNP.kicad_sch, cpu.kicad_sch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]
2023-03-19 20 march version
    Added 2nd list, working on the third
    [delta48m.kicad_sch, logic.kicad_sch, logic2.kicad_sch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]
2023-03-21 March 21st update
    [delta48m.kicad_sch, logic.kicad_sch, logic2.kicad_sch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]
2023-03-22 March 22nd additions
    [delta48m.kicad_sch, logic.kicad_sch, logic2.kicad_sch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]
2023-03-22 March 22nd update 2
    [delta48m.kicad_sch, logic.kicad_sch, unused.kicad_sch]
2023-03-22 March 22nd - 3rd edition
    List 3 is complete
    [SNP.kicad_sch, cpu.kicad_sch, delta48m.kicad_sch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]
2023-03-23 March 23rd Update 1
    [SNP.kicad_sch, delta48m.kicad_sch, logic.kicad_sch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]
2023-03-23 March 23rd First pre-alpha
    First time ZERO errors and 93 warnings. Schematics are done, now to deal with warnings and footprints.
    [ROM.kicad_sch, SNP.kicad_sch, delta48m.kicad_sch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]
2023-03-23 March 24th - First Edition of PCB
    [SNP.kicad_sch, cpu.kicad_sch, delta48m.kicad_pcb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]
2023-03-24 March 24th Second Update
    [ROM.kicad_sch, SNP.kicad_sch, cpu.kicad_sch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]
2023-03-26 March 26th update
    [ROM.kicad_sch, SNP.kicad_sch, cpu.kicad_sch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]
2023-03-26 March 27th Update 1
    [Netlist_1.xlsx]
2023-03-27 Fixes for schematics
2023-03-27 27th of March Update 1
    [Netlist_1.xlsx]
2023-03-28 28th march ver2
    [Netlist_1.xlsx, SNP.kicad_sch, delta48m.kicad_pcb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]
2023-03-29 29th march 2023 Update 1
    [Netlist_1.xlsx, delta48m.kicad_pcb, external.kicad_sch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]
2023-03-31 March 31st Update
    [delta48m.kicad_pcb, delta48m.kicad_sch, logic2.kicad_sch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]
2023-03-31 Version 0.1 (March 31st)
    [delta48m.kicad_pcb, delta48m.kicad_sch, logic2.kicad_sch]
2023-03-31 March 31st final update (for today)
    [delta48m-B_Cu.gbr, delta48m-B_Mask.gbr, delta48m-B_Silkscreen.gbr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]
2023-05-11 11th may update
    [BOM — копия.xlsx, BOM.xlsx]
2023-07-18 Small cleanup
    [delta48m-B_Cu.gbr, delta48m-B_Mask.gbr, delta48m-B_Silkscreen.gbr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]
2023-08-18 Kicad version update
    [ROM.kicad_sch, SNP.kicad_sch, cpu.kicad_sch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]
2023-09-19 Added keyboard project
    [keyboard.kicad_pcb, keyboard.kicad_sch]
2023-09-20 Update 20092023
    [keyboard.kicad_pcb, keyboard.kicad_sch]
2023-09-20 Late night update
    [keyboard.kicad_sch]
2023-09-23 Tracing finished
    [keyboard.kicad_sch]
2023-09-24 24.09.23 Added test keyboard
    [keyboard_test.kicad_pcb, keyboard_test.kicad_sch]
2023-09-25 Added silkscreen to test keyboard
    [keyboard_test.kicad_pcb]
2023-09-26 Keyboard fix applied (DA14 and 15)
    [delta48m.kicad_pcb, external.kicad_sch]
2023-09-27 Update for version 0.2
    [delta48m-B_Cu.gbr, delta48m-B_Mask.gbr, delta48m-B_Silkscreen.gbr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]
2023-09-28 Original keyboard fix
    [keyboard.kicad_sch]
2023-09-30 Cherry Keyboard Ver0.01
    [keyboard_cherry.kicad_pcb, keyboard_cherry.kicad_sch]
2023-10-03 Update for U21 fix (tape loading works now)
    [delta48m.kicad_pcb, logic2.kicad_sch, power.kicad_sch]
2023-10-08 Version 1.0 schematics and PCB complete
    [ROM.kicad_sch, SNP.kicad_sch, cpu.kicad_sch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]
2023-10-09 Gerbers and Version 1.0 fix
    [delta48m.kicad_pcb]
2023-10-09 Keyboard models update
    [MX_PCB.step, MX_Plate.step, Stabilizer_MX_2.00u.step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]
2023-10-10 Update 3d models for keyboard and capacitor
    [100u.stp, 125u.stp, 150u.stp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]
2023-10-11 3d model fix
    [delta48m.kicad_pcb]
2023-10-12 3d models update
    [delta48m.kicad_pcb]
2023-10-14 Adding plate to keyboard
    [keyboard_cherry.kicad_pcb, plate_switch.dxf]
2023-10-16 Update 16.10.2023 (3D stuff)
    [keyboard_cherry.kicad_pcb, keyboard_cherry_large_pcb.kicad_pcb, keyboard_cherry_panel.kicad_pcb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]
2023-10-19 Keyboard gerbers and 3d modelling of top case
    [keyboard_cherry-B_Cu.gbr, keyboard_cherry-B_Mask.gbr, keyboard_cherry-B_Silkscreen.gbr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]
2023-10-20 Added 4th hole for support, changed diameter to M3
    [delta48m.kicad_pcb]
2023-11-10 Small silkscreen fix
    [delta48m.kicad_pcb]
2023-11-13 DXF panel
    [panel.dxf]
2023-11-13 Rev2 Update
    [keyboard_cherry.kicad_pcb, keyboard_cherry.kicad_sch, keyboard_cherry_large_pcb.kicad_pcb]
2023-11-13 Routing rev2
    [keyboard_cherry.kicad_pcb]
2023-11-13 Layout ver.2 finalised
    [175u.stp, keyboard_cherry.kicad_pcb, keyboard_cherry_plate.step]
2023-11-13 3d design for ver2 final
    [keyboard_cherry.kicad_pcb, keyboard_cherry_plate.step]
2023-11-18 Clearing DOCs folder
    [BOM — копия.xlsx, BOM.xlsx, Netlist_1.xlsx]
2023-12-16 Video connector fix and labels
    [delta48m.kicad_pcb, external.kicad_sch, video.kicad_sch]
2024-02-01 Gerbers refresh
    [delta48m-B_Cu.gbr, delta48m-B_Mask.gbr, delta48m-B_Silkscreen.gbr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]
2024-03-18 Version 1.2 update
    [ROM.kicad_sch, SNP.kicad_sch, cpu.kicad_sch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]
2024-03-18 Update 1.2, additional pins
    [ROM.kicad_sch, external.kicad_sch, video.kicad_sch]
2024-03-18 Topology for version 1.2
    [ROM.kicad_sch, delta48m.kicad_pcb, video.kicad_sch]
2024-03-20 Gerbers update
    [delta48m-B_Cu.gbr, delta48m-B_Mask.gbr, delta48m-B_Silkscreen.gbr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]
2024-03-21 Documentation for 1.2
    [ROM.kicad_sch, delta48m.kicad_sch]
2024-04-04 Gerbers 05042024
    [delta48m-B_Cu.gbr, delta48m-B_Mask.gbr, delta48m-B_Silkscreen.gbr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]
2024-04-08 Gerbers 08042024
    [delta48m-B_Cu.gbr, delta48m-B_Mask.gbr, delta48m-B_Silkscreen.gbr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]
2025-03-24 Kicad 9 Update
    [ROM.kicad_sch, SNP.kicad_sch, cpu.kicad_sch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]
